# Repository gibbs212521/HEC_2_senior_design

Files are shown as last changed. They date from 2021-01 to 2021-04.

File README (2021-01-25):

##################################################################################
#                                                                                #

#                                                                                #
##################################################################################

##################################################################################

                #########################################
                #                                       #
                #              Code Example             #
                #   C Code Snippet for Multi-Platform   #
                #           ---Adaptations---           #
                #                                       #
                #########################################

#if defined(WIN32) || defined(_WIN32) || defined(__WIN32__) || defined(__NT__)
   //define something for Windows (32-bit and 64-bit, this part is common)
   #ifdef _WIN64
      //define something for Windows (64-bit only)
   #else
      //define something for Windows (32-bit only)
   #endif
#elif __APPLE__
    #include <TargetConditionals.h>
    #if TARGET_IPHONE_SIMULATOR
         // iOS Simulator
    #elif TARGET_OS_IPHONE
        // iOS device
    #elif TARGET_OS_MAC
        // Other kinds of Mac OS
    #else
    #   error "Unknown Apple platform"
    #endif
#elif __linux__
    // linux
#elif __unix__ // all unices not caught above
    // Unix
#elif defined(_POSIX_VERSION)
    // POSIX
#else
#   error "Unknown compiler"
#endif

/* ********** can be auto-generated in python *********** */

##################################################################################

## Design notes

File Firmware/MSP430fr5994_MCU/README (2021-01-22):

IMPORTANT:
--include_path="C:/ti/ccs1011/ccs/ccs_base/msp430/include" --include_path="C:/ti/ccs1011/ccs/tools/compiler/ti-cgt-msp430_20.2.4.LTS/include" --define=__MSP430FR5994__ --define=_MPU_ENABLE -g --advice:power=all

ALL from Code Composer Studio's compiler:
-vmspx --data_model=restricted --use_hw_mpy=F5 --include_path="C:/ti/ccs1011/ccs/ccs_base/msp430/include" --include_path="C:/ti/ccs1011/ccs/tools/compiler/ti-cgt-msp430_20.2.4.LTS/include" --advice:power=all --advice:hw_config=all --define=__MSP430FR5994__ --define=_MPU_ENABLE -g --printf_support=minimal --diag_warning=225 --diag_wrap=off --display_error_number --silicon_errata=CPU21 --silicon_errata=CPU22 --silicon_errata=CPU40

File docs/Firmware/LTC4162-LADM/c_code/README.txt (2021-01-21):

LTC4162 C Library
==============================

Introduction:
-------------

This  C library includes headers and several functions to simplify communication
with  the  LTC4162.  This  low  level library provides a header file with the
definitions  of registers and bit fields within those registers, and routines to
read and write those registers and individual bit-fields.

Files:
------

LTC4162-LADM_reg_defs.h - Header file containing definitions of registers and bit
fields in the LTC4162.  Names and addresses of registers are defined here.
Names, addresses, sizes, offsets, and masks are defined for bit fields in the
LTC4162.  This information is also packed into a definition that is used by
LTC4162-LADM.c

LTC4162-LADM.c - Functions to initialize a LTC4162 instance, read and write
registers and bit-fields

LTC4162-LADM.h - Header file defining prototypes, data structures and constants
used by LTC4162-LADM.c

LTC4162-LADM_formats.h - File defining constants and macros that can be used by
LTC4162-LADM.c to convert real values to LTC4162 integer values at compile-time
(optimized away) and to convert LTC4162 integer values to real values at run-time
for UI display or debug (floating point arithmetic required).

LTC4162-LADM_pec.c - File containing bit-wise and table lookup CRC-8 functions to
compute SMBus Packet Error Check byte.

LTC4162-LADM_pec.h - File containing Packet Error Check function headers.

LTC4162-LADM_example_generic.c - An example showing how to use the LTC4162.c
library. Dummy functions containing print statements are used in place of
hardware reads and writes.

LTC4162-LADM_example_linux.c - An example using the Linux kernel i2c-dev
interface to communicate with the LTC4162. We've tested this
on a Raspberry Pi 3 Model B.

LTC4162-LADM_bf_config.c - An example re-writing all LTC4162 writable
bit fields to their power-on default state. Can be used as a template to
quickly modify settings from their default.

LTC4162-LADM_reg_config.c - An example re-writing all LTC4162 writable
registers to their power-on default state. Can be used as a template to
quickly modify settings from their default. This program is smaller, but
less readable than LTC4162-LADM_bf_config.c.

LTC4162-LADM_example_mzero.ino - An Arduino Zero compatible example using
the libraries within MZeroSketchbook to communicate with the LTC4162.
This example can be uploaded directly to the DC2038A demoboard. The default GUI-
compatible DC2038A firmware can be restored through the DC2038A GUI.
To build the Arduino Zero project successfully, the following common files
must be in the LTC4162-LADM_example_mzero folder:
  LTC4162-LADM_example_mzero.ino (exists in folder by default)
  LTC4162-LADM.c
  LTC4162-LADM.h
  LTC4162-LADM_formats.h
  LTC4162-LADM_reg_defs.h
Install Arduino IDE version 1.8.7 or later from https://www.arduino.cc/en/Main/Software
if you don't already have it. In Windows Explorer, double-click on the copy of
LTC4162-LADM_example_mzero.ino to launch Arduino IDE.
Click on Tools -> Board: -> Boards Manager , and install the
"Arduino SAMD Boards" version 1.6.20 or later.
Click on Tools -> Board: and select Arduino/Genuino Zero (Native USB Port).
Click on File -> Preferences , and change Sketchbook location to be the path to
the MZeroSketchbook folder. This is located at the top-level directory of this SDK.
Plug in your LTC4162-LADM demoboard via USB.
Click on Tools -> Port . Select the port corresponding to the LTC4162-LADM demoboard.
You're now ready to compile and upload the sketch to your LTC4162-LADM demoboard.

LTC4162-LADM_example_linduino.ino - An example using the LT_SMBus Linduino library
to communicate with the LTC4162. This example can be uploaded onto a Linduino and
can also be easily adapted to use other TWI/I2C/SMBus Arduino libraries.
More information about Linduino is available here:
https://www.analog.com/en/design-center/evaluation-hardware-and-software/linduino.html
To build the Linduino project successfully, the following common files
must be in the LTC4162-LADM_example_linduino folder:
  LTC4162-LADM_example_linduino.ino
  LTC4162-LADM.c
  LTC4162-LADM.h
  LTC4162-LADM_formats.h
  LTC4162-LADM_reg_defs.h
Install Arduino IDE version 1.8.7 or later from https://www.arduino.cc/en/Main/Software
if you don't already have it. In Windows Explorer, double-click on the copy of
LTC4162-LADM_example_ linduino.ino to launch Arduino IDE.
Click on Tools -> Board: and select Arduino/Genuino Uno.
Click on File -> Preferences , and change Sketchbook location to be the path to
the LTSketchbook folder which can be downloaded from here:
https://github.com/analogdevicesinc/Linduino/tree/master/LTSketchbook
Plug in your Linduino via USB.
Click on Tools -> Port . Select the port corresponding to the Linduino.
You're now ready to compile and upload the sketch to your Linduino.

Makefile - Makefile to build the examples.  Targets are generic, linux and clean.
  "make generic" builds LTC4162-LADM_example_generic.c.
  "make linux" builds LTC4162-LADM_example_linux.c.

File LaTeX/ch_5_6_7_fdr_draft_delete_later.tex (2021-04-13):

%		For public use only, fair use laws still apply
%		A tutorial template created by Chad Gibbons

%	I recommend for generic help the following website
%	http://www.emerson.emory.edu/services/latex/latex_toc.html
%	There are many good websites and forums for LaTeX
%
%	If you have a problem, google it. (ex. "How do I start my page numbers at a different number")

%%%%%%%%%%%%%%%%%%%%%%%%%%%%%%%%%%%%%%%%%%%%%%%%%%%%%%
%					 													  %
%					 													  %
%					  ALWAYS BEGIN THE PROGRAM WITH								  %
%					 													  %
%						\documentclass{class_type}								  %
%																		  %
%		Different class types have different commands associated with them, similar to header files			  %
%					 													  %
%					 													  %`
%%%%%%%%%%%%%%%%%%%%%%%%%%%%%%%%%%%%%%%%%%%%%%%%%%%%%%

\documentclass[12pt]{article}
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
\usepackage[english]{babel}
\usepackage{csquotes}				%	Permits \enquote{quote}
\usepackage{graphicx}				%	Permits \includegraphics[]{image}
\usepackage{caption}				%	Permits the void caption \caption*{}
\usepackage{titlesec}				%	Modify section titles
\usepackage{wrapfig}				% 	Insert wrappable objects like figures or tables
%\usepackage{a4wide}				% 	Expand width of body lazily
\usepackage{multicol}				% 	Permits multicolumn
\usepackage{multirow}				%	Permites utilization of multiple rows of a table
\usepackage{tocloft}				%	Permits modification of Table of Contents
\usepackage{amssymb}				%	Greek Alphabet Symbols
\usepackage{appendix}

\usepackage{scrextend}				% 	Permits padding margins of document

\graphicspath{ {./images/} }			%	Sets filepath to images folder in location of TeX Document

\usepackage[utf8]{inputenc}			%	biblatex depends on on this package
\usepackage{comment}
%\usepackage[backend=bibtex,style=numeric]{biblatex}	%	LaTeX blibliography	%% Note: ieee stle lower-cases titles past first letter (Which seems wrong)
\usepackage[backend=bibtex,style=numeric,sorting=none]{biblatex}
%\bibliographystyle{ieeetr}			% INVESTIGATE FURTHER FOR AUTO ORDERING OF BIB REFERENCES
\bibliography{FDR_Draft}				%	REMEMBER TO RENAME THIS FILE IF MOVING TO NEW .bib

%\addbibresource{hec2.bib}

			%	Makes Table of Contents Functionally a table of Hyperlinks
\usepackage{hyperref}
\hypersetup{
	colorlinks,
	citecolor= black,
	filecolor = black,
	linkcolor = blue,
	urlcolor = blue
	}

			%	Next Three Lines permit use of .tif images in \includegraphics
\usepackage{epstopdf}
\epstopdfDeclareGraphicsRule{.tif}{png}{.png}{convert #1 \OutputFile}
\AppendGraphicsExtensions{.tif}

\renewcommand{\thesection}{\Roman{section}} 
\renewcommand{\thesubsection}{\thesection.\Alph{subsection}}
\renewcommand{\thesubsubsection}{\thesection.\arabic{subsubsection}}
\setlength\cftsecnumwidth{3em}
\setlength\cftsubsecnumwidth{3em}
\setlength\cftsubsubsecnumwidth{3em}

			%	Define Abstract to be IEEE compliant (10pt, centered, roman numerals, capitalized)
\titleformat{\abstract}{\normalfont\btshape}{\Roman{section}}{1em}{\MakeUppercase}
			%	Define Sections to be IEEE compliant (10pt, centered, roman numerals, capitalized)
\titleformat{\section}{\normalfont\filcenter}{\Roman{section}.}{1em}{\MakeUppercase}
			%	Define Subections to be IEEE compliant (10pt, left, roman numerals, capitalized)
\titleformat{\subsection}{\normalfont\itshape}{\Alph{subsection}.}{1em}{}
			%	Define Subsubections to be IEEE compliant (10pt, left, roman numerals, capitalized, inline text)
\titleformat{\subsubsection}[runin]{\normalfont\itshape}{\indent\arabic{subsubsection}.)}{1em}{}
			%	Define Table of Contents to be IEEE compliant

			%	Next Two Lines Make Document San-Serif
%\renewcommand{\familydefault}{\sfdefault}		
%\usepackage{helvet}

\usepackage{textcomp}				%	For subsection symbol w/ \textsection
\usepackage{pdfpages}				%	For inserting PDF document and pages into LaTeX file
							%% 		Recommended pdfpages format : 									%%
							%%		\includepdf[pages=-,width=0.9\linewidth,pagecommand={}]{./appendices/file.pdf}		%%

\newcommand{\cross}[1][1pt]{\ooalign{ 	%	Creating footnote cross symbol
  \rule[1ex]{1ex}{#1}\cr% Horizontal bar
  \hss\rule{#1}{.7em}\hss\cr}}% Vertical bar

%\usepackage[T1]{fontspec}
\usepackage{inconsolata}				%	converts \ttfamily to consolas font
%\IfFileExists{zi4.sty}{\usepackage{zi4}}					%	renamed version of inconsolata
%{\usepackage{inconsolata}}	
%\newfontfamily{\ttconsolas}{Consolas}

%%%%%%%%%%%%%%%%%%%%%%%%%%%%%%%%%%%%%%%%%%%%%%%%%%%%%%%			PREAMBLE

%%%%%%%%%%%%%%%%%%%%%%%%%%%%%%%%%%%%%%%%%%%%%%%%%%%%%%%			DOCUMENT

%%%%%%%%%%%%%%%%%%%%%%%%%%%%%%%%%%%%%%%%%%%%%%%%%%%%%%
%					 													  %
%					 													  %
%					  ALWAYS BEGIN THE DOCUMENT WITH								  %
%					 													  %
%							\begin{document}									  %
%					 													  %
%					 													  %
%%%%%%%%%%%%%%%%%%%%%%%%%%%%%%%%%%%%%%%%%%%%%%%%%%%%%%

\begin{document}

\section{Testing and Validation}
\indent
Validation of a product prototype is an important step to determine the performance, reliability, and durability of the designed product. Without proper testing, the product life cycle can be severely limited due to component failure or subcircuit malfunction.  All basic functionality for each subsystem is verified by following standard test practices. The transmitter and receiver subsystems were subjected to validation tests described below to observe their actual performance. 

\pagebreak

\section*{Transmitter Tests} %%%%%%%%%%%%%%%%%%%%%%%%%%%%%%%%%%%%%%%%%%%%%%%%%
\subsection{Transmitter Power Supply Tests}
\indent
The transmitter prototype board testing starts by applying DC voltage on pins 3, and 4 positive terminals and pins 1-7 negative terminals. DC voltage is supplied using a bench power supply with the current limit set to 0.3A. The power supply voltage is gradually increased from 0V to the nominal voltage of 48V while the bench power supply current was constantly monitored.
The 30V regulator will start regulating if the input voltage is higher than 38.3V. The expected output voltage on TP 1 is 30V +/-2\% due to reference voltage tolerance and resistors used for setting the output voltage.\\

\noindent
After the 30V regulator test, the voltage output is verified the following low voltage regulators are verified:\\
\hfill \\
\indent \indent $\cdot$ 3.3V regulator (U11) test point TP2 nominal voltage 3.3V  tolerance +/- 1.5\% \\
\indent \indent $\cdot$ 5V regulator (U11) test point TP3 nominal voltage 5V  tolerance +/- 1.5\%\\

\noindent
Below is the part of the schematic diagram showing test points TP1, TP2, and TP3.
\hfill
\begin{figure}[h!]
\centering
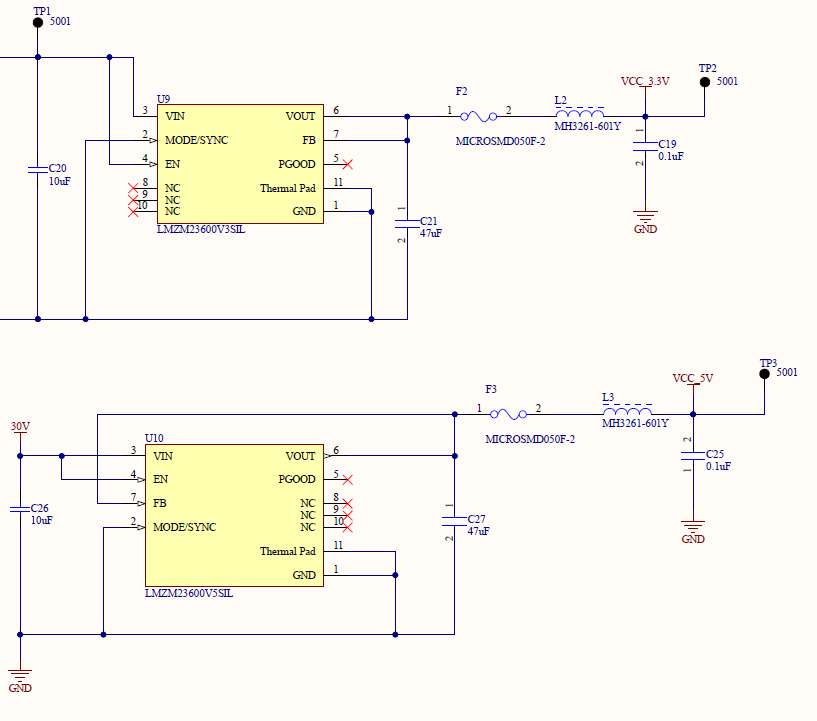
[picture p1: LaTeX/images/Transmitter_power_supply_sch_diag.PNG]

\caption{Transmitter Voltage Regulator Circuits}
\end{figure}

\hfill \\
\indent
After power modules are verified the test firmware can be loaded using a JTAG connection on the board.  The firmware sets all parameters in the default state for testing. The coil driver is disabled and all peripherals are turned off.

\subsection{Transmitter Coil Driver Tests}
\indent
After the firmware is loaded the board is turned off and the transmitter coil is connected to the terminals J3 and J4. The coil driver circuit is tested using a variable voltage supply. To perform this test PPTC fuse, F1 is removed and the bench power supply is connected to the TP1 (positive terminal) and the negative terminal is connected to the ground.  The oscilloscope probe is attached to the drain of  Q1 (GaN FET transistor).  The second probe is connected to the output of the 13.56MHz temperature compensated oscillator (TP4).\\

\indent
After the test equipment is attached the power supply is turned on and the output voltage is gradually increased. When the power supply is higher than 5V voltage regulators (3.3V and 5V) are enabled and they provide power to the transmitter subcircuits.  The temperature compensated oscillator (TXCO) enable line is controlled by push buttons. When the oscillator enable line is set to a high level a 13.56MHz signal is enabled and 13.56MHz is fed into the Class E amplifier driver (U11). The expected voltage from the TXCO on TP4 is 3.3Vpp.  After the oscillator subcircuit is verified the oscilloscope probe is placed on one of the terminals of jumper R32 to verify the functionality of U11. The expected amplitude on the output of the Class E amplifier driver is 5Vpp.\\

\noindent
The figure below presents the subcircuit wherein the transmission signal is generated and tested.
\hfill
\begin{figure}[h!]
\centering
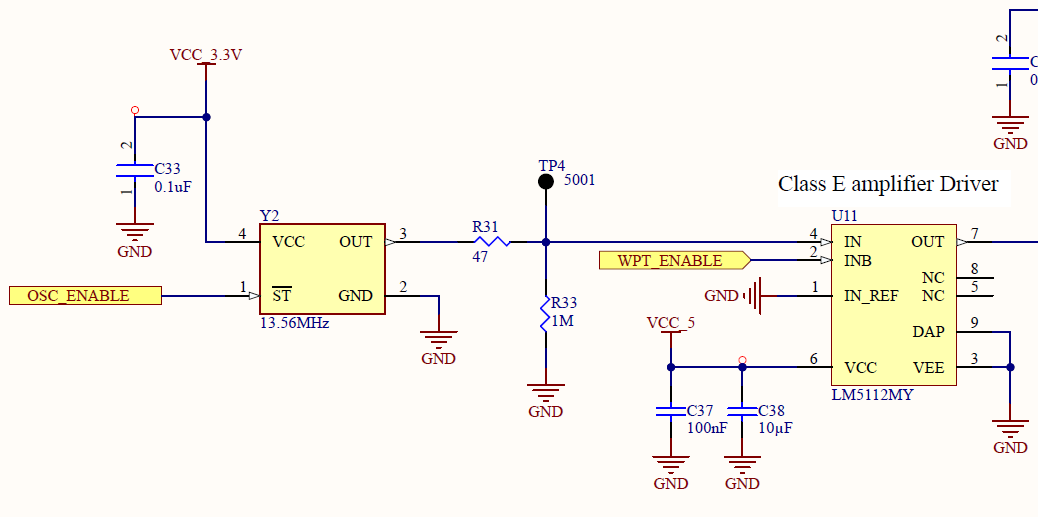
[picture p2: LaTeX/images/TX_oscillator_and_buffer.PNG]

\caption{Oscillator and Buffer Subcircuit}
\end{figure}
\hfill \\
\pagebreak

\indent
The GaN FET switching is verified by observing the GaN FET drain voltage waveform that will have a voltage swing from 0V to 117V if the power supply voltage is set to 30 V. For lower supply voltages the swing will be lower but it always should swing from 0V to some positive voltage.  After the GaN FET switching is verified the transmitter coil resonance will be adjusted. \\

\indent
To set transmitter coil resonance a variable capacitor (C28) must be adjusted while the voltage across the coil is monitored using a 100X oscilloscope probe attached to J4  (transmitter board coil terminal). The trimmer capacitor must be adjusted until the voltage across the transmitter coil reaches the maximum value. After the resonance is achieved the power supply voltage is gradually increased to 30V while the supply current is constantly monitored.  The expected voltage on the drain of the GaN FET is 117Vpp. The measured voltage is recorded.  The 30V power supply current should be 120mA if there is no load present (no receiver coil in the front of the transmitter coil).\\

\noindent
The figure below presents the subcircuit wherein the transmission signal is amplified and observed by a Class E amplifier.
\hfill
\begin{figure}[h!]
\centering
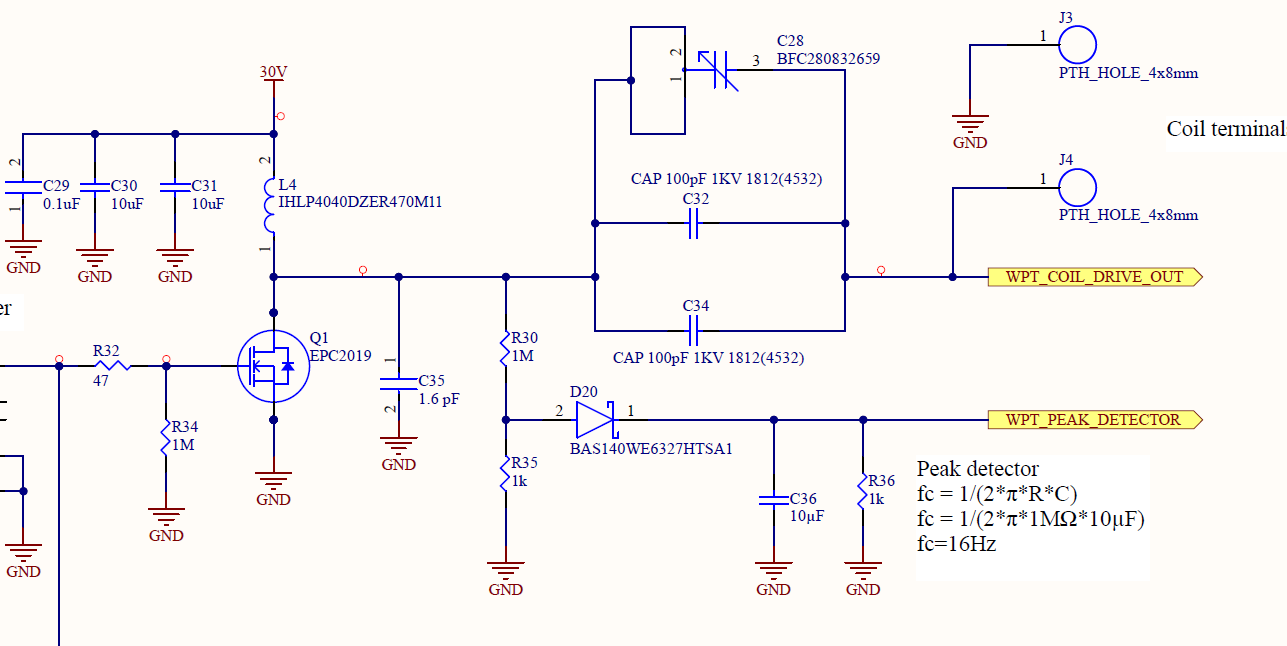
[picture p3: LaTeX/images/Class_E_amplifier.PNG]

\caption{Transmission Signal Class E Amplifier Subcircuit}
\end{figure}
\hfill \\
\pagebreak
\hfill \\
\indent
Transmitter power output is measured when the class E amplifier is verified and the amplifier power supply voltage is 30V.  The specified transmitter power output is 30W. The power output is measured by placing receiving LC circuit loaded with a 50Ω high power resistor in the front of the transmitter coil at a distance of 5 cm. The peak to peak voltage across the load is measured using the oscilloscope and recorded in the table. This process is repeated for distances of 4 cm, 3 cm, 2 cm, and 1 cm.
\hfill
\begin{figure}[h!]
\centering
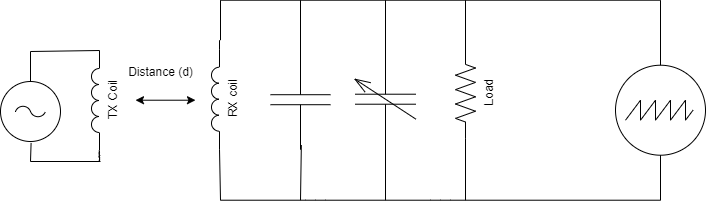
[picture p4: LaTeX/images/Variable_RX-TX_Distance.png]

\caption{Received Power vs. Distance Test Setup}
\end{figure}

\subsection{Transmitter Firmware Tests}

\noindent
The figure below is a reference for the transmitter part numbers and pin numbers.  The part numbers can be found adjacent to the part outline with a prefix of P, J, U, Q, F, D, R, C, or L.  Pin numbers are found without a prefix adjacent to the first and last pin with their respective number in any part denoted by the prefix P where space provides.
\hfill
\begin{figure}[h!]
\centering
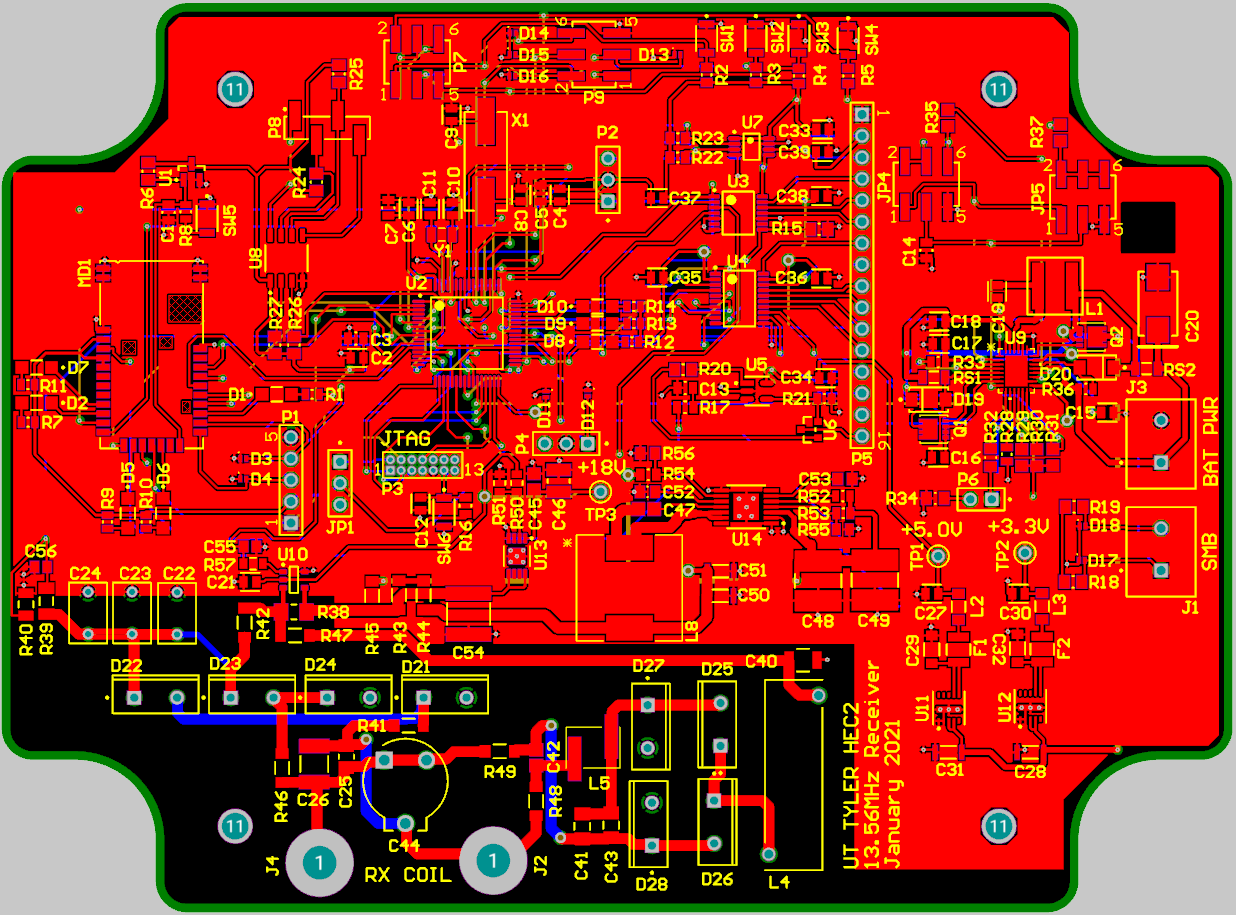
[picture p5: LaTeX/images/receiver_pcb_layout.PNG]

\caption{Reference Layout for Part and Pin Numbers}
\end{figure}

\hfill
\pagebreak
\hfill 
\subsection{Transmitter Firmware Tests}

\indent
The first recommendation in any trouble rise of troubleshooting of quality assurance is to check the mcu\_setup.c and mcu\_setup.h files.  Additionally, it is good to note that a unit test is a type of software test that only requires building a small portion of the codebase in order to test a set of specific modules.  Unit testing reduces the total amount of time dedicated into the development of any software.

%%% Currently at once every two seconds
\subsubsection*{The MCU Clock On LED} (MCU\_Clock\_on or D8 by the microcontroller) should be blinking at a rate of approximately twice every second \textbf{(This rate is subject to change)}.  If this is not occurring, the clock interrupt routine is not operating properly.  Investigate for over-polling at the UART RX Pins (P2.0 and P2.5) is occurring.  Alternatively, the TX Pins could be written out of turn (P2.1 and P2.6) which would thus initiate the UART Interrupts EUSCI\_A0\_VECTOR (located at P2.0 and P2.1) or EUSCI\_A1\_VECTOR (located at P2.5 and P2.6).  If this is not the case, the next step would be to troubleshoot the ADC (Analog to Digital Converter) Pins (P3.0, P3.1, P3.2, and P3.3).  If this issue where the ADC12\_B\_VECTOR interrupt contravenes the clock interrupt is detected, the error is likely caused by a breakdown in the hierarchy of interrupts.  In such a case, the code must be provided additional logic on how to handle specific interrupts in the scheduler’s run method.

\subsubsection*{The LCD Ticker Panel} should display some coherent statement or acronym.  If it does not, running of a “Hello World” unit test to the LCD is required for appropriate troubleshooting.  The unit test should utilize the identical function used in the production code.  If the unit test passes without errors, the error would reside in the accumulation of text that is meant to be passed into the LCD Ticker Panel.

\subsubsection*{The UART (RX/TX) CON} tests require unit tests. There are four unit tests to be done to test the non-Bluetooth UART ports (P2.5 and P2.6).  The first involves transmitting a ‘A’ character to the same PCB’s RX\_CON Pin (P2.5).  The next unit test would involve transmitting a string and acknowledgement TCP handshake.  These same unit tests are repeated with a secondary PCB.

\subsubsection*{The Bluetooth} validation tests will involve a unit test from the personal computer that connects to the receiver and sweeps through a set of pre-programmed unit tests that provide specific responses and sample data points.

\subsubsection*{The Wireless Power Transmission (WPT) Signal Generation} test should be conducted prior to connecting the transmitter's WPT coil.  Press Button 0 at SW1 to turn on the signal generator and measure the voltage at the transmitter WPT Coil Junction points (J3 with J4 as well as J5 with J6).  Once the voltage is observed, press Button 1 at SW2 to turn off the signal generator, and a drop off of voltage should be observed. \textbf{(NOTE: The button closest to the microcontroller is Button 0 while the button furthest from the microcontroller and closest to the pins of Part P5 is Button 4. The buttons are arranged in sequential order.)}
%%%%%%%%%%%%%%%  NEED WPT_PEAK_DETECTOR Algorithm
\hfill
\pagebreak
\section*{Receiver Tests}  %%%%%%%%%%%%%%%%%%%%%%%%%%%%%%%%%%%%%%%%%%%%

\subsection{Receiver Power Supply Tests}
\indent
The receiver prototype board testing starts by applying DC voltage across coil terminals for power supply verification at the Receiver Coil Junction Points (J2 and J4).  The Coil terminal subcircuit is shown in the figure below.
\hfill
\begin{figure}[h!]
\centering
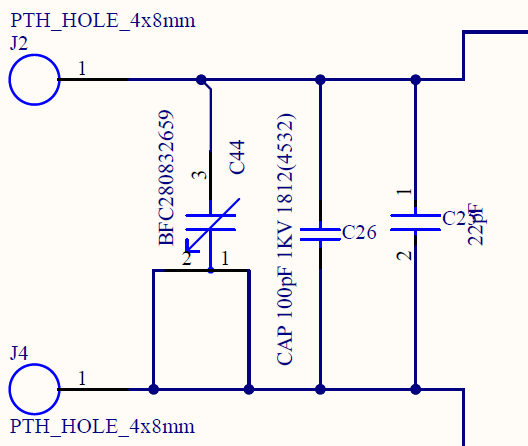
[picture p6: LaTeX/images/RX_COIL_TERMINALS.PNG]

\caption{Receiver Coil Terminal Subcircuit}
\end{figure}
\hfill \\
\indent
This test is necessary for determining whether the voltage regulators output voltages are matching the design specification.\\

\noindent
The following voltage regulators are verified in this test:
\indent \indent $\cdot$3.3V regulator (U12) test point TP2 nominal voltage 3.3V  tolerance +/- 1.5\%\\
\indent \indent $\cdot$5V regulator (U11) test point TP1 nominal voltage 5V  tolerance +/- 1.5\%\\
\indent \indent $\cdot$18V regulator (U13A) test point TP3 nominal voltage 18V tolerance +/- 2\%\\

\noindent
After power module verification the test firmware can be loaded using a JTAG connection on the board.  The firmware sets all parameters in the default state for testing.

\hfill \\
\pagebreak

\subsection{Receiver Wireless Power Rectifier Tests}

\noindent
Specification  for AC-DC (RF-DC) conversion efficiency is 80\%\\
 
\noindent
Conversion efficiency is tested using resistive load and without any other circuit attached to the DC side of the converter (R43 is removed). The load voltage and current are continuously  measured.  The specified receiver coil distance from the charger coil is 5 cm max.
\subsubsection*{Efficiency Test Protocol}\hfill \\
\noindent
This test is determines the efficiency of the power transfer at various distances:\\
\indent \indent $\cdot$The transmitter RF output is set to output 30W.\\
\indent \indent $\cdot$The receiver coil is placed at a 5 cm distance from the transmitter\\
\indent \indent $\cdot$Current and load voltage are recorded\\

\noindent
Previous steps are performed for distances 4 cm, 3 cm 2 cm, and 1 cm.  Using collected information load power is calculated.  Efficiency is calculated using the following equation:

\begin{equation}
\eta = \frac{P_{receiver}}{P_{transmitter}} \cdot 100\%
\end{equation}
\hfill
\begin{figure}[h!]
\centering
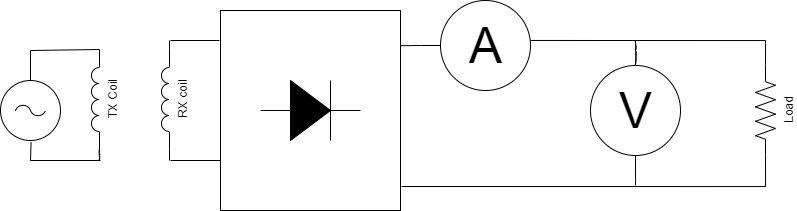
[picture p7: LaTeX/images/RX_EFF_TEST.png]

\caption{Receiver RF-DC Converter Efficiency Test Setup}
\end{figure}

\subsection{Receiver Battery Charger Tests}

\indent
The bench power supply current should initially be llimited to 1A and the initial voltage should be set to 20V.  There are two diode voltage drops (1.4V) in the full wave rectifier bridge circuit.  18.6V on charger input is high enough for the proper operating voltage for the LTC4162-L battery charger.  The charger is functional without the battery pack and according to the datasheet, the voltage on the charger output will rise to the programmed constant-voltage value. By measuring this voltage it is possible to determine whether the charger regulates the proper voltage for a given programmed value.
\hfill 
\pagebreak
\hfill \\

\indent
A 18650 battery with two cells in series discharged to 3.2-3.8V per cell may be used for constant current and constant voltage charge testing.  The bench power supply should be connected followed by the battery and no change in MCU behavior should be noted. Constant current charging should begin.  The current limit of the bench power supply may be increased and the charging current should increase up to a maximum of 3.2A. The maximum charging current, charging voltage, cell count, and power supply current and voltage should be recorded and efficiency calculated.\\

\indent Then the power supply should be disconnected and reconnected and there should be no effect on the MCU power state. Charging should automatically resume when the power supply is reconnected. The battery should be allowed to charge until it enters constant voltage mode, which may be recognized by a slowly decreasing charge current that is much lower than the maximum current observed during constant current charging.  A 2 ohm load should be connected to the battery under charge for at least 30 seconds and removed without any effect on MCU operation.

\subsection{Receiver Firmware Tests}

\indent
The first recommendation in any trouble rise of troubleshooting of quality assurance is to check the mcu\_setup.c and mcu\_setup.h files.  Additionally, it is good to note that a unit test is a type of software test that only requires building a small portion of the codebase in order to test a set of specific modules.  Unit testing reduces the total amount of time dedicated into the development of any software.

%%% Currently at once every two seconds
\subsubsection*{The MCU Clock On LED} (MCU\_Clock\_on or D8 by the microcontroller) should be blinking at a rate of approximately twice every second \textbf{(This rate is subject to change)}.  If this is not occurring, the clock interrupt routine is not operating properly.  Investigate for over-polling at the UART RX Pins (P2.0 and P2.5) is occurring.  Alternatively, the TX Pins could be written out of turn (P2.1 and P2.6) which would thus initiate the UART Interrupts EUSCI\_A0\_VECTOR (located at P2.0 and P2.1) or EUSCI\_A1\_VECTOR (located at P2.5 and P2.6).  If this is not the case, the next step would be to troubleshoot the ADC (Analog to Digital Converter) Pins (P3.0, P3.1, P3.2, and P3.3).  If this issue where the ADC12\_B\_VECTOR interrupt contravenes the clock interrupt is detected, the error is likely caused by a breakdown in the hierarchy of interrupts.  In such a case, the code must be provided additional logic on how to handle specific interrupts in the scheduler’s run method.

\subsubsection*{The LCD Ticker Panel} should display some coherent statement or acronym.  If it does not, running of a “Hello World” unit test to the LCD is required for appropriate troubleshooting.  The unit test should utilize the identical function used in the production code.  If the unit test passes without errors, the error would reside in the accumulation of text that is meant to be passed into the LCD Ticker Panel.

\subsubsection*{The UART (RX/TX) CON} tests require unit tests. There are four unit tests to be done to test the non-Bluetooth UART ports (P2.5 and P2.6).  The first involves transmitting a ‘A’ character to the same PCB’s RX\_CON Pin (P2.5).  The next unit test would involve transmitting a string and acknowledgement TCP handshake.  These same unit tests are repeated with a secondary PCB.

\subsubsection*{The Bluetooth} validation tests will involve a unit test from the personal computer that connects to the receiver and sweeps through a set of pre-programmed unit tests that provide specific responses and sample data points.  The Bluetooth tests for the receiver should also include data requests pertaining to the voltage from the battery, the battery's current charge, and any data utilized in the battery charger.
\hfill \\
\pagebreak
\hfill
\section*{System Tests}
\subsection{Coil Test}
Coil impedance is measured using Vector Network Analyzer (VNA). The impedance measurement is obtained by setting the instrument to measure S-parameters (S11) at 13.56 MHz.  Before measurements, the instrument must be calibrated using calibration standards (short circuit, open circuit, and 50$\omega$ load).  The measured impedance is in complex form R+jX form.\\

\noindent
Specified inductance: 909.66nH\\

\noindent
The coil's inductance is determined using the formula below:
\begin{equation}
L = \frac{X_L}{\omega}
\end{equation}
\noindent
Where $\omega$ = 2$\pi$f\\

\noindent
The figure below shows the the equivalent circuit of how the transmitter / receiver coils were evaluated using a Vector Network Analyzer.
\hfill
\begin{figure}[h!]
\centering
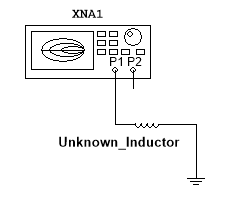
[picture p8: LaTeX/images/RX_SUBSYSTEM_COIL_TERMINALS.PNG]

\caption{VNA Test Setup}
\end{figure}

\pagebreak

\noindent
Although VNA is not very precise for quality factor measurements it still can be used for estimation. The quality factor is determined by obtaining S21 parameter (forward voltage gain).\\

\noindent
Specified Q factor: 1119\\
 
 \noindent
The quality factor also can be determined by dividing reactance by the resistance the formula is shown below:
\begin{equation}
Q = \frac{X_L}{R}
\end{equation}

\subsection{System Level Firmware Tests}

\subsubsection*{The Bluetooth Localization Test} utilizes the “M” command on the RN4870 BLE chip with 3 prior locations to triangulate which direction is moving towards the transmitter.  This test begins with a computer provided unit test that accepts four distances, the first three that are used to triangulate the receiver in reference to the transmitter and a fourth that must be closer than all three triangulating distances to be considered passing.
\hfill 
\pagebreak

\subsection{Test Results Summary}

\subsubsection{Transmitter Evaluations} \hfill
\subsubsection*{DC Power Test} \hfill \\
\noindent
30V regulator no-load condition measured output voltage 30.04 V\\
5V regulator measured output voltage TP3 5.03V\\
3.3V regulator measured output voltage TP2 3.33V\\
 
\subsubsection*{Coil Driver Test} \hfill \\
Oscillator output voltage TP4 3.69V$_{pp}$\\
 
\noindent
Oscillator output Frequency (13.56 MHz) measured: 13.56MHz\\
Class E amplifier driver voltage jumper R32 (nominal 5Vpp) measured 5.80Vpp
\hfill
\begin{figure}[h!]
\centering
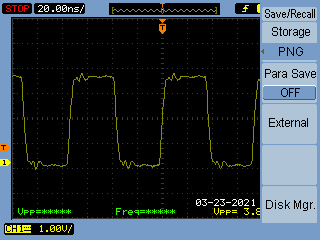
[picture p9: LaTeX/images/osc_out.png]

\caption{Class E Amplifier Driver Output}
\end{figure}
\hfill \\
\pagebreak

\noindent
Q1 Dran nom. 117 V$_{pp}$ (30 V supply) Measured 102V$_{pp}$
\hfill
\begin{figure}[h!]
\centering

\caption{Q1 Drain Voltage Waveform}
\end{figure}

\noindent
Transmitter coil voltage 117 V$_{pp}$ (30 V supply) Measured 204V$_{pp}$
\hfill
\begin{figure}[h!]
\centering

\caption{Q1 Drain Voltage Waveform}
\end{figure}
\hfill 
\pagebreak
\hfill \\
\noindent
Transmitter subsystem input current at 30V supply (120 mA nom. no laod) Measured 140 mA

\begin{table}[h!]
\centering
%Received Power (DC) vs Distance Test
\caption{Transmitted Power vs. Distance Test}
\begin{tabular}{ | c | c | c | }
\hline
 Distance [cm] & Measured Voltage [V$_{pp}$] & Received Power [W] \\
 \hline
5 & & \\
\hline
4 & & \\
\hline
3 & & \\
\hline
2 & & \\
\hline
1 & & \\
\hline
\end{tabular}
\end{table}

\subsubsection{Receiver Evaluations} \hfill \\
\subsubsection*{DC Power Test} \hfill \\
\noindent
5V regulator measured output voltage TP1 5.07V\\
3.3V regulator measured output voltage TP2 3.33V\\
18V regulator measured output voltage TP3 18.26V\\

\begin{table}[h!]
\centering
\caption{Received Power (DC) vs Distance Test}
\begin{tabular}{ | c | c | c |  c |}
\hline
Distance [cm] & Measured Voltage [V] & Measured Current [A] & Power Received [W] \\
\hline
5 & & & \\
\hline
4 & & & \\
\hline
3 & & & \\
\hline
2 & & & \\
\hline
1 & & & \\
\hline
\end{tabular}
\end{table}

\subsubsection*{Coil Design Verification Test}\hfill \\
\noindent
Specified inductance: 909.66nH\\ 
Measured impedance at 13.56MHz: 0.43 +j78.28$\Omega$\\
\hfill \\
\pagebreak
\hfill \\
\begin{figure}[h!]
\centering

\caption{VNA TX/RX Coil Impedance Measurement}
\end{figure}
\hfill \\
\noindent 
Measured inductance using VNA (HP8753E) 0.917 $\mu$H\\
Measured inductance using LCR meter (HP4262A) 0.97$\mu$H\\
Q factor from VNA impedance measurement: 182
\hfill
\pagebreak
\section{Broader Impacts of the Project}

\indent
This product follows FDA, IEE, and government safety regulations. A few ethical issues faced by our design include high voltages across the coil, excessive heat generation within the receiver, and electromagnetic field interference. During simulation stages, high voltages were observed across the coil which increases the risk of electric shock hazard. In order to lower this risk, the coil insulation will adhere to a wider voltage range. Within the receiver, excessive heat generation along high current levels can cause damage to batteries. Therefore, lower charging currents will be used in order to prevent damage. Excessive heat also increases the cost of the project as fans would need to be added. Electromagnetic field interference caused by the transmitter coil can disrupt the charging circuit and cause battery failure. To prevent this issue, additional shielding will be implemented. \\

\indent
During testing stages, minor ethical issues were faced by the design. Within the receiver board, there was an inductor that was not suited for a frequency of 13.56 MHz board causing failure, and our rectifier circuits caused more loading than expected when tested with a signal generator. Also, the 48V to 30V buck stage microcontroller failed during testing for reasons that are yet to be further investigated by the team. When components get too hot, there’s not only a risk of it failing, but also of leaking its chemicals which can be dangerous to human skin and eyes. Therefore, the group will adhere to safety procedures such as wearing Personal Protective Equipment (PPE). Another risk observed here is electrical shock hazard due to the overloading in the circuit. To prevent this, the group will continuously measure the circuit for abnormal values while testing.\\

\indent
Our project’s goal is to provide users a low-cost medium-power wireless charger. There are no products like this one in the market for a few reasons: chargers do not supply more than 5W via inductive charging, an existing industrial unit with same purposes as our product is priced at about \$2000 USD, and available wireless chargers are limited for charging a single type of device only. With our product, users will be able to charge a standard battery type and integrate it in their own design or use it for stand-alone operations. Our product communicates electronic circuits, electromagnetic fields, digital systems, and microprocessors concepts to the audience. This product will not only be a low-cost wireless charger option, it will also provide customers with a charger for mobile devices of all shapes and sizes, no wiring exposure, apply greater range of tolerance for misalignment when charging, and provide a compact charging area. \\

\indent
Our product will be useful to robotics hobbyists and inventors who are developing new products that require wireless charging, serve to influence kids and teenagers interested in STEM, can be used for research and development, and capitalized in OEM market.

\begin{table}[h!]
\centering
\caption*{Ethical and Professional Considerations}
\begin{tabular} {| r | c | }
\hline
\parbox{0.4\linewidth}{\raggedright Public Health} &   \parbox{0.65\linewidth}{\hfill \\
$\cdot$ Medical Equipment RF Exposure \\ $\cdot$ Electrical Shock \\ $\cdot$ Chemical Exposure}\\
\hline
\parbox{0.4\linewidth}{\raggedright Safety and Wellness} &   \parbox{0.65\linewidth}{\hfill \\
$\cdot$ RF Bandwidth Jamming \\ $\cdot$ Electrical Shock \\ $\cdot$ Chemical Exposure}\\
\hline
\parbox{0.4\linewidth}{\raggedright Global Factors} &   \parbox{0.65\linewidth}{\hfill \\
$\cdot$ International Governing Bodies \\ $\cdot$ Sourcing Restrictions \\ $\cdot$ Inter-Market Penetrability}\\
\hline
\parbox{0.4\linewidth}{\raggedright Societal Factors} &   \parbox{0.65\linewidth}{\hfill \\
$\cdot$ Open-Source Capitalization\\ $\cdot$ STEM Educational Resources \\ $\cdot$ Professional Organizations \\ $\cdot$ Customer Privacy \& Security}\\
\hline
\parbox{0.4\linewidth}{\raggedright Environmental Factors} &   \parbox{0.65\linewidth}{\hfill \\
$\cdot$ Chemical Pollution\\ $\cdot$ User Environmental Awareness\\ $\cdot$ Emergency Shut Off Cases}\\
\hline
\parbox{0.4\linewidth}{\raggedright Economic Factors} &   \parbox{0.65\linewidth}{\hfill \\
$\cdot$ Open-Source Capitalization\\ $\cdot$ Specialty Clientele\\ $\cdot$ Rapid Agile-Deployment\\ $\cdot$ Light-Weight Production}\\
\hline
\end{tabular}
\end{table}
\hfill \\

\section{Conclusion}

\indent
This conclusion reflects the current state of our testing and troubleshooting process. We expect to continue testing our prototype and resolving issues in order to bring performance as close as possible to our initial specifications.\\

\indent
The 5V LCD contrast control circuit on both boards failed due to a design error: the digital potentiometer chosen was not capable of controlling a voltage greater than the 3.3V digital supply voltage. The 5V supplied to the potentiometer simply fed into the 3.3V supply through the protection diodes until the circuit was disabled.\\

\indent
The 48V to 30V buck stage control IC on the transmitter board self-destructed for as-yet unknown reasons. No obvious design errors were found. Further diagnosis was postponed pending testing of the remainder of the board using a bench power supply.\\
\hfill \\
\pagebreak
\hfill \\

\indent
Initial tests of the battery charging circuit were successful. A test battery of two fully charged 18650 cells was correctly detected and not charged further. After partial discharge the charger entered a constant-voltage charging mode and charged the battery at a slowly decreasing current of approximately 1A. The receiver board continued to operate on battery power when simulated wireless power was removed. Further testing of constant current charging, telemetry, and the SMbus smart battery interface is pending.\\

\indent
Initial testing of the wireless power transfer resulted in a period of successful inductive power transfer and a brief success in achieving a resonant link. A failure on the transmitter board was traced to an inductor that was not suitable for operation at 13.56 Mhz. The inductor and damaged components were replaced and testing continued. A resonant link was achieved between the transmitter and receiver, but an unexpected transient destroyed the transmitter amplifier transistor. A more robust replacement will be installed for further testing.\\

\indent
In summation, our testing revealed a few avoidable design errors which can be corrected or managed until a major revision is possible. The greatest challenge our testing has revealed is controlling the high voltages and unexpected transients that even a moderate-power resonant link creates. We hope that the use of more robust components will make it possible to continue testing and characterizing the real-world performance of our wireless power circuit. A further challenge is minimizing the losses from the high-frequency rectification stage. Our initial tests indicate that switching losses in the full wave bridge rectifier are significant. As suggested by our faculty advisor, it is possible that half-wave rectification will prove more efficient than a full-wave bridge.\\

\indent
With the benefit of foresight, we would have made a few minor and one major change in our design process. The wireless power transfer circuit is the most original component of our design and ideally would have been prototyped and tested much earlier in the design process. More minor changes would include accepting the more limited selection of 3.3V LCD’s and deleting the 5V rail and support circuitry. The 48V transmitter power supply and buck stage was chosen to minimize current and provide headroom for adjustments to the wireless transmitter voltage, but further testing may prove that a 30V supply with no further conversion is sufficient.
\hfill 
\pagebreak

%%%%%%%%%%%%%%%%%%%%%%%%%%%%%%%%%%%%%%%%%%%%%%%%%%%%%%%%
%%%%%%%%%%%%%										        %%%%%%%%%%%%%
%%%%						ABOVE IS IN DOCUMENT PROPER					         %%%%
%%%%%%%%%%%%%										        %%%%%%%%%%%%%
%%%%%%%%%%%%%%%%%%%%%%%%%%%%%%%%%%%%%%%%%%%%%%%%%%%%%%%%

%%%% APPENDICES %%%%

%\hline
%\parbox{0.4\linewidth}{\raggedright
%
%} &  \parbox{0.4\linewidth}{\raggedright
%
%}\\
%\hline
\section{Experimental Data Collection Sheets}

\subsection{Transmitter Subsystem Data}

\begin{table}[h!]
\centering
\caption*{Transmitter Subsystem Data}
\begin{tabular}{ | c | c | }
\hline
\textbf{Power Supply Verification} & \textbf{Pass or Fail} \\
\hline
\parbox{0.5\linewidth}{\raggedright \hfill \\[-0.25 em]
30V power supply voltage nominal 30V +/-2\% Measured (TP1) \hfill \\[0.1 em]
} &  \parbox{0.4\linewidth}{\raggedright \hfill \\ [0.7 em]
\underline{\hspace{0.625in}} V  \hspace{0.125 in}Pass \space / \space  Fail \hfill \\ [0.3 em]
} \\
\hline
\parbox{0.5\linewidth}{\raggedright \hfill \\[-0.25 em]
3.3V regulator (U11) test point TP2 nominal voltage 3.3V  tolerance +/- 1.5\% \hfill \\[0.1 em]
} &  \parbox{0.4\linewidth}{\raggedright \hfill \\ [0.7 em]
\underline{\hspace{0.625in}} V  \hspace{0.125 in}Pass \space / \space  Fail \hfill \\ [0.3 em]
} \\
\hline
\parbox{0.5\linewidth}{\raggedright \hfill \\[-0.25 em]
5V regulator (U11) test point TP3 nominal voltage 5V  tolerance +/- 1.5\% \hfill \\[0.1 em]
} &  \parbox{0.4\linewidth}{\raggedright \hfill \\ [0.7 em]
\underline{\hspace{0.625in}} V  \hspace{0.125 in}Pass \space / \space  Fail \hfill \\ [0.3 em]
} \\ 
\hline
\parbox{0.5\linewidth}{\raggedright \hfill \\[-0.25 em]
Coil driver Circuit Test \hfill \\[0.1 em]
} &  \parbox{0.4\linewidth}{\raggedright \hfill \\ [0.7 em]
\underline{\hspace{0.625in}} V  \hspace{0.125 in}Pass \space / \space  Fail \hfill \\ [0.3 em]
} \\ 
\hline
\parbox{0.5\linewidth}{\raggedright \hfill \\[-0.25 em]
Verify functionality of Transmitter Sub-circuits \hfill \\[0.1 em]
} &  \parbox{0.4\linewidth}{\raggedright \hfill \\ [0.7 em]
\underline{\hspace{0.625in}} V  \hspace{0.125 in}Pass \space / \space  Fail \hfill \\ [0.3 em]
} \\ 
\hline
\parbox{0.5\linewidth}{\raggedright \hfill \\[-0.25 em]
Verify Functionality of U11 \hfill \\[0.1 em]
} &  \parbox{0.4\linewidth}{\raggedright \hfill \\ [0.7 em]
\underline{\hspace{0.625in}} V  \hspace{0.125 in}Pass \space / \space  Fail \hfill \\ [0.3 em]
} \\ 
\hline
\parbox{0.5\linewidth}{\raggedright \hfill \\[-0.25 em]
Voltage test for drain of the GaN FET \hfill \\[0.1 em]
} &  \parbox{0.4\linewidth}{\raggedright \hfill \\ [0.7 em]
\underline{\hspace{0.625in}} V  \hspace{0.125 in}Pass \space / \space  Fail \hfill \\ [0.3 em]
} \\ 
\hline
\parbox{0.5\linewidth}{\raggedright \hfill \\[-0.25 em]
Test Peak to Peak Voltage across load \hfill \\[0.1 em]
} &  \parbox{0.4\linewidth}{\raggedright \hfill \\ [0.7 em]
\underline{\hspace{0.625in}} V  \hspace{0.125 in}Pass \space / \space  Fail \hfill \\ [0.3 em]
} \\ 
\hline
\parbox{0.5\linewidth}{\raggedright \hfill \\[-0.25 em]
Test Transmitter Power Output \hfill \\[0.1 em]
} &  \parbox{0.4\linewidth}{\raggedright \hfill \\ [0.7 em]
\underline{\hspace{0.625in}} V  \hspace{0.125 in}Pass \space / \space  Fail \hfill \\ [0.3 em]
} \\ 
\hline
\end{tabular}
\end{table}
\noindent
\textbf{This process is repeated for distances of 5 cm, 4 cm, 3 cm, 2 cm, and 1 cm.}

\subsection{Receiver Regulators Subsystem Data}

\begin{table}[h!]
\centering
\caption*{Receiver Regulators Subsystem Data}
\begin{tabular}{ | c | c | }
\hline
\textbf{Power Supply Verification} & \textbf{Pass or Fail} \\
\hline
\parbox{0.5\linewidth}{\raggedright \hfill \\[-0.25 em]
DC voltage across coil terminals (J2 \& J4)
 \hfill \\[0.1 em]} &  \parbox{0.4\linewidth}{\raggedright \hfill \\ [0.7 em]
\underline{\hspace{0.625in}} V  \hspace{0.125 in}Pass \space / \space  Fail \hfill \\ [0.3 em]
} \\
\hline
\parbox{0.5\linewidth}{\raggedright \hfill \\[-0.25 em]
5V regulator (U11) test point TP3 nominal voltage 5V  tolerance +/- 1.5\%
\hfill \\[0.1 em]} &  \parbox{0.4\linewidth}{\raggedright \hfill \\ [0.7 em]
\underline{\hspace{0.625in}} V  \hspace{0.125 in}Pass \space / \space  Fail \hfill \\ [0.3 em]
} \\
\hline
\parbox{0.5\linewidth}{\raggedright \hfill \\[-0.25 em]
3.3V regulator (U11) test point TP2 nominal voltage 3.3V  tolerance +/- 1.5\%
\hfill \\[0.1 em]} &  \parbox{0.4\linewidth}{\raggedright \hfill \\ [0.7 em]
\underline{\hspace{0.625in}} V  \hspace{0.125 in}Pass \space / \space  Fail \hfill \\ [0.3 em]
} \\ 
\hline
\parbox{0.5\linewidth}{\raggedright \hfill \\[-0.25 em]
Firmware Test Successful Load
\hfill \\[0.1 em]} &  \parbox{0.4\linewidth}{\raggedright \hfill \\ [0.7 em]
\underline{\hspace{0.625in}} V  \hspace{0.125 in}Pass \space / \space  Fail \hfill \\ [0.3 em]
} \\ 
\hline
\end{tabular}
\end{table}
\hfill \\
\pagebreak

\subsection{Receiver Rectifier Subsystem Data}

\begin{table}[h!]
\centering
\caption*{Receiver Rectifier Subsystem Data}
\begin{tabular}{ | c | c | }
\hline
\textbf{Efficiency Test Protocols} & \textbf{Parameters} \\
\hline
\parbox{0.5\linewidth}{\raggedright \hfill \\[-0.25 em]
The transmitter RF output
 \hfill \\[0.1 em]} & 
 30 W\\
\hline
\parbox{0.5\linewidth}{\raggedright \hfill \\[-0.25 em]
The receiver coil placement (parallel)
\hfill \\[0.1 em]} & 
5 cm\\
\hline
\parbox{0.5\linewidth}{\raggedright \hfill \\[-0.25 em]
Current measured
\hfill \\[0.1 em]} &  \parbox{0.4\linewidth}{\raggedright \hfill \\ [0.7 em] \underline{\hspace{0.625in}} 
A 
\hspace{0.125 in}Pass \space / \space  Fail \hfill \\ [0.3 em]} \\ 
\hline
\parbox{0.5\linewidth}{\raggedright \hfill \\[-0.25 em]
Load Voltage measured
\hfill \\[0.1 em]} &  \parbox{0.4\linewidth}{\raggedright \hfill \\ [0.7 em]\underline{\hspace{0.625in}} 
V  
\hspace{0.125 in}Pass \space / \space  Fail \hfill \\ [0.3 em]} \\ 
\hline
\parbox{0.5\linewidth}{\raggedright \hfill \\[-0.25 em]
Load Power
\hfill \\[0.1 em]} &  \parbox{0.4\linewidth}{\raggedright \hfill \\ [0.7 em]\underline{\hspace{0.625in}} 
W
\hspace{0.125 in}Pass \space / \space  Fail \hfill \\ [0.3 em]} \\ 
\hline
\parbox{0.5\linewidth}{\raggedright \hfill \\[-0.25 em]
Efficiency
\hfill \\[0.1 em]} &  \parbox{0.4\linewidth}{\raggedright \hfill \\ [0.7 em]\underline{\hspace{0.625in}} 
\%
\hspace{0.125 in}Pass \space / \space  Fail \hfill \\ [0.3 em]} \\ 
\hline
\end{tabular}
\end{table}
\noindent
\textbf{This process is repeated for distances of 5 cm, 4 cm, 3 cm, 2 cm, and 1 cm.}

\subsection{Charger Subsystem Data}

\begin{table}[h!]
\centering
\caption*{Charger Subsystem Data}
\begin{tabular}{ | c | c | }
\hline
\textbf{Test Protocols} & \textbf{Parameters} \\
\hline
\parbox{0.5\linewidth}{\raggedright \hfill \\[-0.25 em]
Set bench power supply current limit
 \hfill \\[0.1 em]} & 
 1 A \\
\hline
\parbox{0.5\linewidth}{\raggedright \hfill \\[-0.25 em]
Set initial voltage
\hfill \\[0.1 em]} & 
20 V\\
\hline
\parbox{0.5\linewidth}{\raggedright \hfill \\[-0.25 em]
Verify Charger Input Voltage
\hfill \\[0.1 em]} &  
18.6 V\\
\hline
\parbox{0.5\linewidth}{\raggedright \hfill \\[-0.25 em]
Voltage Charger Output
\hfill \\[0.1 em]} &  \parbox{0.4\linewidth}{\raggedright \hfill \\ [0.7 em] \underline{\hspace{0.625in}} 
V 
\hspace{0.125 in}Pass \space / \space  Fail \hfill \\ [0.3 em]} \\ 
\hline
\end{tabular}
\end{table}
\hfill \\
\pagebreak

\subsection{SMBus Subsystem Test  Data}

\begin{table}[h!]
\centering
\caption*{SMBus Subsystem Test Data}
\begin{tabular}{ | c | c | }
\hline
\textbf{Test Protocols} & \textbf{Parameters} \\
\hline
\parbox{0.5\linewidth}{\raggedright \hfill \\[-0.25 em]
Verify Interface Functionality
\hfill \\[0.1 em]} &  \parbox{0.4\linewidth}{\centering \hfill \\ [0.7 em] 
Pass \space / \space  Fail \hfill \\ [0.3 em]} \\ 
\hline
\parbox{0.5\linewidth}{\raggedright \hfill \\[-0.25 em]
Input Undervoltage Setting
\hfill \\[0.1 em]} &  \parbox{0.4\linewidth}{\raggedright \hfill \\ [0.7 em]\underline{\hspace{0.625in}} 
V  
\hspace{0.125 in}Pass \space / \space  Fail \hfill \\ [0.3 em]} \\ 
\hline
\parbox{0.5\linewidth}{\raggedright \hfill \\[-0.25 em]
Final Charge Voltage
\hfill \\[0.1 em]} &  \parbox{0.4\linewidth}{\raggedright \hfill \\ [0.7 em]\underline{\hspace{0.625in}} 
V
\hspace{0.125 in}Pass \space / \space  Fail \hfill \\ [0.3 em]} \\ 
\hline
\parbox{0.5\linewidth}{\raggedright \hfill \\[-0.25 em]
Target Charge Current
\hfill \\[0.1 em]} &  \parbox{0.4\linewidth}{\raggedright \hfill \\ [0.7 em]\underline{\hspace{0.625in}} 
A
\hspace{0.125 in}Pass \space / \space  Fail \hfill \\ [0.3 em]} \\ 
\hline
\parbox{0.5\linewidth}{\raggedright \hfill \\[-0.25 em]
Input Current Limit Target
\hfill \\[0.1 em]} &  \parbox{0.4\linewidth}{\raggedright \hfill \\ [0.7 em]\underline{\hspace{0.625in}} 
A
\hspace{0.125 in}Pass \space / \space  Fail \hfill \\ [0.3 em]} \\ 
\hline
\end{tabular}
\end{table}

\subsection{Coil Subsystem Test Data}
\begin{table}[h!]
\centering
\caption*{Coil Subsystem Test Data}
\begin{tabular}{ | c | c | }
\hline
\textbf{Test Protocols} & \textbf{Parameters} \\
\hline
\parbox{0.5\linewidth}{\raggedright \hfill \\[-0.25 em]
Calibration Test for Short Circuit
\hfill \\[0.1 em]} &  \parbox{0.4\linewidth}{\raggedright \hfill \\ [0.7 em] \underline{\hspace{0.625in}} 
$\mu$H
\hspace{0.125 in}Pass \space / \space  Fail \hfill \\ [0.3 em]} \\ 
\hline
\parbox{0.5\linewidth}{\raggedright \hfill \\[-0.25 em]
Calibration Test for Open Circuit
\hfill \\[0.1 em]} &  \parbox{0.4\linewidth}{\raggedright \hfill \\ [0.7 em]\underline{\hspace{0.625in}} 
$\mu$H
\hspace{0.125 in}Pass \space / \space  Fail \hfill \\ [0.3 em]} \\ 
\hline
\parbox{0.5\linewidth}{\raggedright \hfill \\[-0.25 em]
Calibration Test with 50$\Omega$ Resistive Load
\hfill \\[0.1 em]} &  \parbox{0.4\linewidth}{\raggedright \hfill \\ [0.7 em]\underline{\hspace{0.625in}} 
$\mu$H
\hspace{0.125 in}Pass \space / \space  Fail \hfill \\ [0.3 em]} \\ 
\hline
\parbox{0.5\linewidth}{\raggedright \hfill \\[-0.25 em]
Inductive Reactance
\hfill \\[0.1 em]} &  \parbox{0.4\linewidth}{\raggedright \hfill \\ [0.7 em]\underline{\hspace{0.625in}} 
j$\Omega$
\hspace{0.125 in}Pass \space / \space  Fail \hfill \\ [0.3 em]} \\ 
\hline
\parbox{0.5\linewidth}{\raggedright \hfill \\[-0.25 em]
Impedance
\hfill \\[0.1 em]} &  \parbox{0.4\linewidth}{\raggedright \hfill \\ [0.7 em]\underline{\hspace{0.625in}} 
$\Omega$
\hspace{0.125 in}Pass \space / \space  Fail \hfill \\ [0.3 em]} \\ 
\hline
\parbox{0.5\linewidth}{\raggedright \hfill \\[-0.25 em]
Quality Factor Estimation
\hfill \\[0.1 em]} &  \parbox{0.4\linewidth}{\raggedright \hfill \\ [0.7 em]\underline{\hspace{0.625in}} 
\hspace{0.125 in}Pass \space / \space  Fail \hfill \\ [0.3 em]} \\ 
\hline
\parbox{0.5\linewidth}{\raggedright \hfill \\[-0.25 em]
S$_{21}$ parameter (Forward Voltage Gain)
\hfill \\[0.1 em]} &  \parbox{0.4\linewidth}{\raggedright \hfill \\ [0.7 em]\underline{\hspace{0.625in}} 
\hspace{0.125 in}Pass \space / \space  Fail \hfill \\ [0.3 em]} \\ 
\hline
\end{tabular}
\end{table}

\end{document}

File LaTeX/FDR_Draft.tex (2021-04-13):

%		For public use only, fair use laws still apply
%		A tutorial template created by Chad Gibbons

%	I recommend for generic help the following website
%	http://www.emerson.emory.edu/services/latex/latex_toc.html
%	There are many good websites and forums for LaTeX
%
%	If you have a problem, google it. (ex. "How do I start my page numbers at a different number")

%%%%%%%%%%%%%%%%%%%%%%%%%%%%%%%%%%%%%%%%%%%%%%%%%%%%%%
%					 													  %
%					 													  %
%					  ALWAYS BEGIN THE PROGRAM WITH								  %
%					 													  %
%						\documentclass{class_type}								  %
%																		  %
%		Different class types have different commands associated with them, similar to header files			  %
%					 													  %
%					 													  %`
%%%%%%%%%%%%%%%%%%%%%%%%%%%%%%%%%%%%%%%%%%%%%%%%%%%%%%

\documentclass[12pt]{article}
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

\title{\Large \textbf{The University of Texas at Tyler\\
College of Engineering and Computer Science\\
Tyler, TX 75799\\
\hfill \\
\hfill \\[0.5em]
Final Design Report \\ [0.25em] For\\[0.25em]
Wireless Charger Project}}		%note left quote command vs " = \textquotedblright
%%  FIX FONT of Sub Sub Title  >> It should fit in with the text below. <<
\author{\large \hfill \\[0.5em] \textbf{A design project to fulfill the requirements of Senior Design}\\ \textbf{ 
in the Department of Electrical Engineering}\\ \textbf{ 
at The University of Texas at Tyler
}\hfill \\ \hfill \\[0.5em]}
\date{\normalsize \flushleft  The  individuals  whose  names  and  signatures  appear  below  certify  that  the  narrative, diagrams,  figures,  tables,  calculations,  and  analyses  contained  within  this  document  are their original work except as otherwise cited.
\hfill \\ \hfill \\[0.5em]
\underline{Flory, David\space\space\space\space\space\space\space\space\space\space\space} \hspace{0.25in}
\underline{\space\space\space\space\space\space\space\space\space\space\space\space\space\space\space\space\space\space\space\space\space\space\space\space\space\space\space\space\space\space\space\space\space\space\space\space\space\space\space\space\space} \hspace{0.25in}
\underline{\today \space\space\space\space\space\space\space} \hspace{0.25in}\\
\hspace{1.8in} Signature \hspace{1.8in} Date \hfill \\ \hfill \\
\underline{Fran\c{c}a, Natasha\space\space\space\space\space\space} \hspace{0.25in}
\underline{\space\space\space\space\space\space\space\space\space\space\space\space\space\space\space\space\space\space\space\space\space\space\space\space\space\space\space\space\space\space\space\space\space\space\space\space\space\space\space\space\space} \hspace{0.25in}
\underline{\today \space\space\space\space\space\space\space} \hspace{0.25in}\\
\hspace{1.8in} Signature \hspace{1.8in} Date \hfill \\ \hfill \\
\underline{Franulovic, Franci \space\space} \hspace{0.25in}
\underline{\space\space\space\space\space\space\space\space\space\space\space\space\space\space\space\space\space\space\space\space\space\space\space\space\space\space\space\space\space\space\space\space\space\space\space\space\space\space\space\space\space} \hspace{0.25in}
\underline{\today \space\space\space\space\space\space\space} \hspace{0.25in}\\
\hspace{1.8in} Signature \hspace{1.8in} Date \hfill \\ \hfill \\
\underline{Gibbons, Chad \space\space\space\space\space\space\space} \hspace{0.25in}
\underline{\space\space\space\space\space\space\space\space\space\space\space\space\space\space\space\space\space\space\space\space\space\space\space\space\space\space\space\space\space\space\space\space\space\space\space\space\space\space\space\space\space} \hspace{0.25in}
\underline{\today \space\space\space\space\space\space\space} \hspace{0.25in}\\
\hspace{1.8in} Signature \hspace{1.8in} Date \hfill \\ \hfill \\
\underline{Sosa, Francisco \space\space\space\space\space\space\space} \hspace{0.25in}
\underline{\space\space\space\space\space\space\space\space\space\space\space\space\space\space\space\space\space\space\space\space\space\space\space\space\space\space\space\space\space\space\space\space\space\space\space\space\space\space\space\space\space} \hspace{0.25in}
\underline{\today \space\space\space\space\space\space\space} \hspace{0.25in}\\
\hspace{1.8in} Signature \hspace{1.8in} Date \hfill \\
}
%\date{12/29/2018}					%	Set permanent date or use date section as additional text real estate on the title page.
%\date{Sic et Non \\ Quid Faciendus Est}

%%%%%%%%%%%%%%%%%%%%%%%%%%%%%%%%%%%%%%%%%%%%%%%%%%%%%%%			DOCUMENT

%%%%%%%%%%%%%%%%%%%%%%%%%%%%%%%%%%%%%%%%%%%%%%%%%%%%%%
%					 													  %
%					 													  %
%					  ALWAYS BEGIN THE DOCUMENT WITH								  %
%					 													  %
%							\begin{document}									  %
%					 													  %
%					 													  %
%%%%%%%%%%%%%%%%%%%%%%%%%%%%%%%%%%%%%%%%%%%%%%%%%%%%%%

\begin{document}
\includepdf[pages=-,pagecommand={}]{./front_page/FDR_front_page_signed.pdf}

\pagenumbering{gobble}

\pagebreak

\section*{Acknowledgments}
\pagenumbering{roman}
\indent \indent
We as a team wish to thank Indus Instruments and Dr. Sridhar Madala for being the benefactors and sponsors of our Project.  Indus Instruments develops and creates electronic devices and software to meet the needs of various industries; for instance, they provide Baylor College of Medicine critical equipment for medical research.   Dr. Sridhar Madala has been generous with our time and was critical in the initial planning phase of the project.  Dr. Madala's familiarity with FCC and international wireless transmission regulations gave clear constraints and direction to this project.  Thus, we especially thank Dr. Sridhar Madala for agreeing to be HEC-2's technical advisor.

\pagebreak

\section*{Executive Summary}
\indent \indent
The team has designed and is prototyping a managed, 30 watt wireless resonant charger for use with lithium-ion battery packs. It shall be a versatile solution to the problem of powering autonomous mobile devices fitted with moderately sized battery packs of approximately four to six 18650 cells configured for 7.4 to 14.7 volts nominal output. With an estimated cost around \$300, it fills a gap between inexpensive inductive chargers in the 5 watt range and custom 90 watt robotic power systems that have an entry level price of \$2000.\\ \indent

Our charging system is made with two essential components: a transmitter and receiver. The transmitter is supplied by standard line voltage and will be responsible for safely delivering up to 30 watts of resonant power to the receiver when in range and appropriately positioned. It shall communicate status with the receiver over a Bluetooth link and shall enable or disable power transmission when requested.\\ \indent

The receiver shall communicate with the transmitter and to a user GUI over Bluetooth links, and optionally with the user’s own application (i.e. a robot microcontroller) over a serial link. It will be capable of delivering requested power transmission and charging status information and beginning or ending the charging process. It shall cease charging on receipt of an error status from the charging circuit and will notify the user to take corrective action. Under normal conditions it will deliver power to the charging control IC, which shall charge the attached battery pack.\\ \indent

The charger may be configured to charge 7.4 to 14.7 nominal Li-Ion battery cells, which must have internal protection circuitry in accordance with UL1642 and IEC61960. Optimal configurations would include a 7.4V pack rated for 3.2A charging, a 11.1V pack rated for 2.2A charging, or a 14.8V pack rated for 1.7A charging.\\ \indent

To best demonstrate the full potential of our project, the team is pursuing optional deliverables that should be completed if time permits once the core project is completed. These stretch goals include a mobile robot capable of charging itself for continuous wireless operation and integration with a smart Li-ion battery for detailed fuel gauge and battery health status.

\pagebreak

\tableofcontents

\pagebreak

\listoffigures

\pagebreak

\listoftables

\pagebreak

	%%%%%%%%%%%%%%%%%%%%%%%%%%%%%%%%%%%%%%%%%%
	%														 %
	%														 %
	%		\hfill fills in the remaining spaces of the given line with spaces			 %
	%														 %
	%					\\ ends line           							 %
	%														 %
	%	Determine the number of "\hfill \\ " iterations in accord with the number of lines		 %
	%				   within you abstract.							 %
	%														 %
	%														 %
	%%%%%%%%%%%%%%%%%%%%%%%%%%%%%%%%%%%%%%%%%%

	%%%%%%%%%%%%%%%%%%%%%%%%%%%%%%%%%%%%%%%%%%
	%														 %
	%														 %
	%		The primary purpose of an abstract is to give sufficient information		 %
	%					on your report to inform 						 %
	%		researchers, students, grant providers, corporate executives, professors,  	 %
	%				professionals, or the audience of your intention			 %
	%		whether or not either reading or purchasing your report is necessary.		 %
	%														 %
	%														 %
	%%%%%%%%%%%%%%%%%%%%%%%%%%%%%%%%%%%%%%%%%%

\pagenumbering{arabic}

%
%	Start with defining the problem you are trying to solve and why there is still a need to solve it
%
%	+ (Problem) User devices need wireless recharging solutions
%	+ (Why need to solve exists) Shortage of cost effective mid range wireless power transfer products in market.
%
%	Is this the only product in the market? <-- we answered this >:(
%
%	
%

\section{Project Description}
\indent \indent
Our team noted a need for users to charge medium power devices via wireless charging.  After further investigation we also determined that there is a shortage of cost effective medium power wireless chargers on the market.\\ \indent

Our project is a 30 watts nominal resonant wireless charger prototype for use with 4 to 6 cell lithium ion battery packs. It is managed by a microcontroller. It may be monitored and controlled by a user GUI or directly by the target application. Unlike existing customized and proprietary robotic charging systems, our product will charge a standard battery type and be suitable for both stand-alone operations and integration into the user's own design.\\ \indent

The team has been unable to discover any equivalent products to our own for retail. The most comparable product is Wibotic's Standard High Power System\cite{WiboSHPS}, a 90 watt magnetic resonance device that is marketed to businesses designing commercial drones and robotic systems. On the lower end, nearly all unbranded, low-cost wireless chargers that are available from mass online retailers supply no more than 5W via inductive charging. For a single industrial unit, we have received a price quote for approximately \$2000 USD. Individuals and small R\&D teams that search for suitable devices through online retailers will find that these low-end transmitters are not modular and are limited to one specific purpose such as charging cell phones or key-fobs.\\ \indent

Our charging system employs magnetic resonance coupling to charge a lithium ion battery pack, delivering between 15 and 30 watts of power. The power transmitter and receiver communicates as a unified system that can provide battery management, protect against overcharging, and provide both diagnostic and telemetric information to the user and to an optional serial connection with the powered application’s control circuitry. The charging system may be monitored and controlled by the user either through an attached LCD interface or a GUI from either a Bluetooth connected PC or smartphone.\\ \indent

This wireless charging alternative's intended market consists of hobbyists and prototype designers considering a self-docking direct electrical connection solution. This is the charging method used by the Roomba\cite{RoombaEduData}, which engages with a custom dock and charges using metal contacts. While this is a cost-effective solution for a mass-produced product, wireless charging is a superior choice for autonomous mobile devices that might have a wide variety of sizes and shapes. The benefits offered by our product's wireless charging include flexible placement of the charger, a compact charging area, greater tolerance for misalignment between the charger and the target device, and the absence of exposed electrical connections.  Additionally, this product would solve the same need for OEM producers who are interested in a ``turn-key'' wireless charging solution.\\

\pagebreak
\indent
To best demonstrate the full potential of our project, the team has specified optional deliverables that include a mobile robot capable of charging itself for continuous wireless operation, fully integrated with a smart Li-ion battery for detailed fuel gauge and battery health status.\\ \indent %% (May be retracted at a later date)

The team holds that a moderate power, low cost wireless charger with accessible telemetry is useful to a small but important market of robotics hobbyists and developers, who at present, are not being served by either costly, proprietary business-to-business solutions or the low power and poorly documented inductive chargers available on the hobby market.\\ \indent

Below in Figure 1, the general flow of power from the AC to DC Wall Converter to the end user's device and information from the user is shown.
\hfill 
\begin{figure}[h!]
\centering
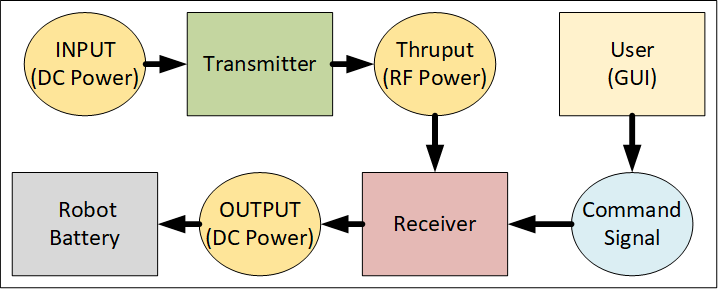
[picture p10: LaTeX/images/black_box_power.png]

\caption{Operation Story Block Diagram}
\end{figure}

\indent
The project is divided between two teams: the hardware team and the software team.

\subsection{Software Team's Focus for Project}

\indent \indent
The software team is focused on two programs: the microcontrollers' firmware and the graphical user interface (GUI) software application.  The firmware operates the transmitter or receiver while the GUI allows for the user to readily monitor and interact throughout the charging process.

\hfill
\pagebreak
\hfill

\subsection{Hardware Team's Focus for Project}

\indent \indent
The hardware team is focused on producing three modular components: the receiver PCB, the transmitter PCB, and the coil module.  The image below displays how these modules operate together.

%%%%%%%%%%%%%%%

\begin{figure}[h!]
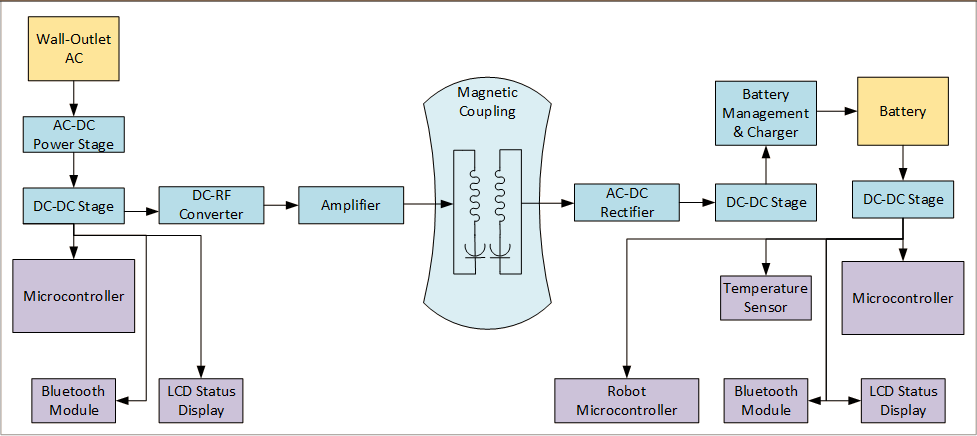
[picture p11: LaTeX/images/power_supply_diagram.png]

\caption{Power Supply of Transmitter and Receiver Subsystems}
\end{figure}
\indent
While the image below explicitly separates out the receiver and transmitter modules.  Note that the completed PCB boards have a power transferring coil module affixed to them individually.
\begin{figure}[h!]
\centering
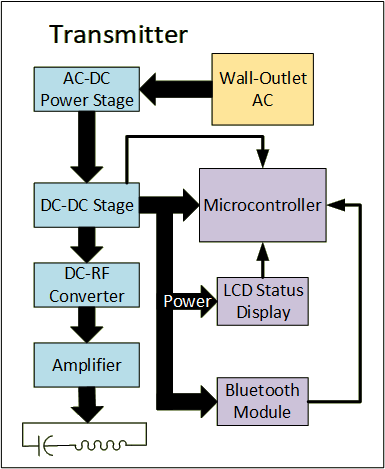
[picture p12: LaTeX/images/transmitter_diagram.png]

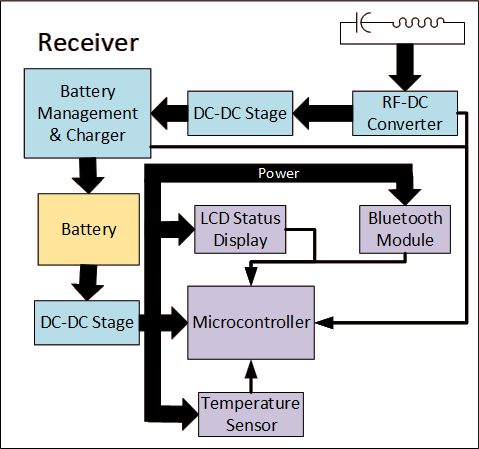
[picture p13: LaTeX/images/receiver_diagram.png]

\caption{Transmitter and Receiver Block Diagrams}
\end{figure}
\hfill \\

%%%%%%%%%%%%%%%%%%%%%%%%5

\hfill 
\pagebreak
\hfill

\section{Final Design Specifications}

\indent
Table 1 below shows the specs of the receiver subsystem.
\hfill

	% Wrap Table Example

%\begin{wraptable}[1]{2}[3]{4}
%...
%\end{wraptable}
%Number of lines (optional)
%“r” for right and “l” for left figure placement.
%Overhang (optional)
%Width to be reserved.

%\newcolumntype{C}{>{\centering\arraybackslash} m{6cm} }  %# New column type
%\newcolumntype{R}{>{\raggedleft \arraybackslash} m{6cm} }  %# New column type

\begin{table}[h!]
\centering
\caption{Receiver Specifications}
\begin{tabular} {| r | c | }
\hline
\parbox{0.225\linewidth}{\raggedleft \hfill \\ Charge time \\  (Per 4Ah Battery Packs)\\} & ~ 5 Hours Max\\
\hline
Battery pack voltage & 14.2 V  \\
\hline
\parbox{0.25\linewidth}{\raggedleft \hfill \\  Coupling Efficiency \\ Transmitter to Receiver\\[0.4em]} & 90\%\\
\hline
\parbox{0.25\linewidth}{\raggedleft \hfill \\  AC-DC \\ Conversion Efficiency} & 80\%\\
\hline
\parbox{0.25\linewidth}{\raggedleft \hfill \\  Charging Controller \\  DC-DC converter} & 85\%\\[0.4em]
\hline
\parbox{0.25\linewidth}{\raggedleft \hfill \\  Overall Receiver \\  Conversion Efficiency} & 61.2\%\\[0.4em]
\hline
\parbox{0.25\linewidth}{\raggedleft \hfill \\  Maximum Battery \\ Charging Current} &   \parbox{0.225\linewidth}{\centering 1.25 A (14.7 V \\ battery pack)}\\
\hline
\parbox{0.25\linewidth}{\raggedleft \hfill \\  Charger Subsystem \\  Charge Protocol} &  \parbox{0.225\linewidth}{\centering \hfill \\  Constant Current \\Constant Voltage \\(Li-ION Battery)}\\
\hline
Battery Type &   \parbox{0.25\linewidth}{\centering\hfill \\  Lithium-Ion \\ (4 x18650 in Series or 2P4S Configuration)}\\
\hline
\parbox{0.25\linewidth}{\raggedleft \hfill \\  Power Negotiation} &  \parbox{0.225\linewidth}{\centering\hfill \\ Bluetooth 5 LE\\}\\
\hline
\parbox{0.25\linewidth}{\raggedleft \hfill \\  Transmitter Locator \\ Method \\[0.4em]} &   \parbox{0.225\linewidth}{\centering \hfill \\  RF Localization  [Bluetooth]}\\
\hline
Deliverable Demo &   \parbox{0.25\linewidth}{\centering \hfill \\  Self-Moving Device (Robot)}\\
\hline
Telemetry &   \parbox{0.25\linewidth}{\centering \hfill \\  Report State \\to GUI Device}\\[0.4em]
\hline
LCD display &   \parbox{0.25\linewidth}{\centering \hfill \\  Diagnostic Character \\String Display}\\
\hline
\end{tabular}
\end{table}
 
 \pagebreak
 
\indent 
Table 2 below shows the specs of the transmitter subsystem.  

\hfill

\begin{table}[h!]
\centering
\caption{Transmitter Specifications}
\begin{tabular} {| r | c | }
\hline
Operating frequency & 13.56 MHz\\
\hline
RF power output & 30 W\\
\hline
Max operating range & 5 cm\\
\hline
DC Power supply  & 48 V 1.25 A max.  \\
\hline
\parbox{0.275\linewidth}{\raggedleft  Conversion Efficiency\\ DC-AC\\[0.4em]}  & 80\%\\
\hline
Telemetry &\parbox{0.24\linewidth}{\centering Report State \\to GUI Device\\[0.4em]}\\
\hline
\end{tabular}
\end{table}

\indent
Table 3 below shows the communication specifications. 
\hfill

\begin{table}[h!]
\centering
\caption{Communication Link Specifications}
\begin{tabular} {| r | c | }
\hline
\parbox{0.275\linewidth}{\raggedleft Communication Medium \\[0.4em]} &  \parbox{0.24\linewidth}{\centering Bluetooth 5 LE}\\
\hline
\parbox{0.275\linewidth}{\raggedleft Protocol} &  \parbox{0.24\linewidth}{\centering \hfill\\[0.1em] L2CAP \\ (RFCOMM)\\[0.5em]}\\
% L2CAP === Logical Link Control and Adaptation Protocol (Host Stack --> One Controller with multiple devices pairing)
\hline
\end{tabular}
\end{table}

\indent
 Table 4 below shows the GUI software specifications.
 \hfill

\begin{table}[h!]
\centering
\caption{GUI Specifications}
\begin{tabular} {| r | c | }
\hline
\parbox{0.275\linewidth}{\raggedleft GUI OS} & \parbox{0.24\linewidth}{\centering \hfill \\ WinOS, IOS, \\ Linux, \& Android}\\[0.4em]
\hline
\parbox{0.275\linewidth}{\raggedleft License} &    \parbox{0.24\linewidth}{\centering LGPL 3.0} \\
\hline
\parbox{0.275\linewidth}{\raggedleft Software Architecture} &   \parbox{0.24\linewidth}{\centering \hfill \\ Model-Controller-View (MCV) Architecture\\[0.4em]} \\
\hline
\parbox{0.275\linewidth}{\raggedleft Delivery Model} &   \parbox{0.24\linewidth}{\centering \hfill \\ Open Source \\ (Free App Download)} \\[0.4em]
\hline
%\parbox{0.45\linewidth}{\raggedleft Deployment Model} &   \parbox{0.45\linewidth}{\centering Open Source / Free To Download App} \\
%\hline
\end{tabular}
\end{table}

\pagebreak

\subsection{Feasibility Study}

\indent \indent
The design consists of two subsystems: the transmitter and the receiver. This product is expected to be used by hobbyists and prototype designers for different applications that require contactless charging. There is no similar device available in the price range from \$200 to \$400.  The expected cost of the charger system is \$300. There are some commercial chargers available right now and the cost of that system is \$2000. The price of \$300 per system will make wireless charging affordable for hobbyists and freelance hardware developers.\\

\indent
The design tools such as Altium designer and Multisim simulator are available free of charge to all group members using the provided UT Tyler license. Also, parts manufacturers are providing free simulation and evaluation tools for development. In addition to the software evaluation kits may be required for testing certain parts of the system such as the microcontroller, Bluetooth module, and the battery charger controller. Most of those evaluation modules are already purchased and they are available to team members. Evaluation kits are purchased by Indus Instruments.\\

\indent
The system is designed such that it uses standard components that are available at any electronic components store and they can be purchased without restrictions. PCB fabrication will be given to a company located in China that is offering quick turnaround PCB fabrication and fast shipping. Components purchasing and printed circuit board assembly will be done at Indus Instruments. Indus Instruments have all the necessary equipment that can handle surface mount components.\\

\indent
All test equipment required for development and testing will be available. Indus Instruments will provide space and necessary test equipment for the wireless charging system prototype evaluation and testing.\\

\indent
The final product cost is estimated at around \$300 (for small quantities). Most likely for larger quantities, it is possible to decrease the cost even more. 

\pagebreak

\subsection{Microcontroller}

\indent \indent
There are four aspects to analyze: economics, technical, legal, and scheduling. A single MSP430FR5994 part costs about \$3 to \$4, while the MSP-EXP430FR5994 LaunchPad kit costs \$16.99. Considering the team only needs two of these microcontrollers (one for the transmitter and one for the receiver), this is an economic and reasonable cost. \cite{MSP430FR599x}  \cite{testKit}. On the technical side, this microcontroller’s memory, voltage supply limitations, UART and I$^2$Cmode specifications, and overall low power consumption makes it the ideal model for our project needs \cite{MSP430FR599x}. Some of the most important standards TI’s MSP430FR5994 complies with include ANSI, JEDEC, and ESDA \cite{MSP430FR599x}. Lastly, the team already has in hands the LaunchPad kit for the microcontroller. The individual microcontrollers are also ready-to-purchase items with delivery times of less than 7 days. More testing will be done once the team has the first PCB design in hands.

\subsection{Transmitter Coil}

%%%%%%  COME BACK TO ME %%%%%%%%%%%%%%%%%%%%%%%%%%%%%%%%%%%%%%%%%%%%%%%%%%%%%%%%%%%%%%%%%%%%%%%%%%%%%%%%%%%%%%%%%%%%%%%%%%%%%%%%%%%%%%%%%%%%%%%%%%%%%%%%%%%%%%%%%%%%%%%%%%%%%%%%%%%%%%%%%%%%%%%%%%%%%%%%%%%%%%%%%%%%%%%%%%%%%%%%%%%%%%%%%%%%%%%%%%%%%%%%%%%%%%%%%%%%%%%%%%%%%%%%%%%%%%%%%%%%%%%%%%%%%%%%%%%%%%%%%%%%%%%%%%%%%%%%%%%%%%%%%%%%%%%%%%%%%%%%%%%%%%%%%%%%%%%%%%%%%%%%%%%%%%%%%%%%%%%%%%%%%%%%%%%%%%%%%%%%%%%%%%%%%%%%%%%%%%%%%%%%%%%%%%%%%%%%%%%%%%%%%%%%%%%%%%%%%%%%%%%%%%%%%%%%%%%%%%%%%%%%%%%%%%%%%%%%%%%%%%%%%%%%%%%%%%%%%%%%%%%%%%%%%%%%%%%%%%%%%%%%%%%%%%%%%%%%%%%%%%%%%%%%%%%%%%%%%%%%%%%%%%%%%%%%%%%%%%%%%%%%%%%%%%%%%%%%%%%%%%%%%%%%%%%%%%%%%%%%%%%%%%%%%%%%%%%%%%%%%%%%%%%%%%%%%%%%%%%%%%%%%%%%%%%%%%%

\indent \indent
The circular planar coil was the most inexpensive approach, the copper tubing to make the coils has an approximate value of  \$15.99. The design properties also significantly contributed to reducing the complexity of acquiring the main coil parameters. It was important to take this factor into account because of the time constraint of two months. In order to reduce the complexity in our project, the spiral planar design was the best option.\\

\indent
The calculation of the inductance formula in the planar spiral design was easier to acquire than the other two proposed solutions. This was crucial because it significantly gave the project a higher chance of matching the predestined inductance of the circuit requirement of .909 $\mu$H.\\

\indent
The economical and ethical considerations did not affect our decision making as much, due to the fact that there were not many differences. Furthermore, this design was appropriate for our project and the team does have the budget, resources and time to successfully to implement this design. \\

\indent
The planar spiral coil design allows the project to more reduces the complexity of the formulas implemented in the calculations. 

%%%%%%%%%%%%%%%%%%%%%%%%%%%%%%%%%%%%%%%%%%%%%%%%%%%%%%%%%%%%%%%%%%%%%%%%%%%%%%%%%%%%%%%%%%%%%%%%%%%%%%%%%%%%%%%%%%%%%%%%%%%%%%%%%%%%%%%%%%%%%%%%%%%%%%%%%%%%%%%%%%%%%%%%%%%%%%%%%%%%%%%%%%%%%%%%%%%%%%%%%%%%%%%%%%%%%%%%%%%%%%%%%%%%%%%%%%%%%%%%%%%%%%%%%%%%%%%%%%%%%%%%%%%%%%%%%%%%%%%%%%%%%%%%%%%%%%%%%%%%%%%%%%%%%%%%%%%%%%%%%%%%%%%%%%%%%%%%%%%%%%%%%%%%%%%%%%%%%%%%%%%%%%%%%%%%%%%%%%%%%%%%%%%%%%%%%%%%%%%%%%%%%%%%%%%%%%%%%%%%%%%%%%%%%%%%%%%%%%%%%%%%%%%%%%%%%%%%%%%%%%%%%%%%%%%%%%%%%%%%%%%%%%%%%%%%%%%%%%%%%%%%%%%%%%%%%%%%%%%%%%%%%%%%%%%%%%%%%%%%

\subsection{Transmitter}

\indent \indent
The transmitter class-E amplifier circuit was simulated at an efficiency of 98\%. The actual transmitter efficiency would be around 90\%. In the simulation, it was determined that the current required to power the class-E amplifier is 0.9 A at 30 V. The power for the transmitter will be supplied by using an external 48 V AC to DC converter followed by a step-down converter in the transmitter subsystem.\\

\pagebreak

\indent
The main concern in this subsystem is the immunity of the supporting circuits to the RF electromagnetic field generated by the transmitter coil. The transmitter coil placement must be done such that the electromagnetic field has minimal effects on the electronic circuits in the transmitter. The transmitter sensitive electronic parts may require EMI shields.\\

\indent
During the simulation, the high voltage across the coil was observed. The highest voltage observed was 320 V$_{pp}$. That voltage poses a serious electric shock hazard. Therefore, the transmitter coil insulation must be capable of withstanding voltages that are in the 500V to 1kV range to provide a safety margin for the design. One way of achieving this is to make a plastic box that would contain the transmitter coil and have insulation that is capable of withstanding voltages in the 500 V to 1000 V range.  \\

\indent
Heat dissipation in the Class E amplifier circuit is expected to be around 3W (based on the efficiency of 90\%). That dissipation will occur in inductors, capacitors (due to ESR), and the amplifier transistor. The transistor will have a proper heatsink to prevent overheating. Since the dissipation in the transistor is very small (on-resistance is 50 mΩ) the proper thermal management will be achieved on the printed circuit board. Coils used in the transmitter will be designed such that the col resistance is minimized which also will decrease the heat dissipation in the transmitter circuit.

\subsection{Receiver}

\indent \indent
There is a possibility that the receiver RF to DC stage performs with higher losses than the losses that were determined in the simulation. According to the simulation data, the RF to DC conversion will be 81\% efficient. In the system specification, the conversion efficiency is set to 80\%. It is important to keep efficiency above 80\% to prevent excessive heat generation. If received power is 25W and efficiency is  80\% then power dissipation is 5 W.   \\

\indent
The excessive heat may have adverse effects on battery life and the speed of charging \cite{TPSM265R1}. A higher temperature environment requires lower charging currents to prevent further temperature rise and damage to the battery cells. Also, excessive heat generation must be minimized to avoid the use of fans and large heat-sinks. Heat-sinks and fans would increase the cost and the size of our product.   If during the prototype test phase efficiency drops below 80\% the circuit must be redesigned to achieve the target specification efficiency. \\

\pagebreak

\indent
One problem that is likely to occur is the interference in the battery charging and communication link circuits caused by a strong electromagnetic field generated by the transmitter coil. Even though all good practices will be followed for the circuit board design the electromagnetic interference still may not be prevented. Charging circuit disruption can cause battery failure due to overcharging or overheating. If this problem occurs the additional EMI shielding will be required. The shielding includes placing metal boxes over sensitive electronic subcircuits and placing additional filters in series with DC power supplies for sensitive parts such as a microcontroller, Bluetooth module, and charger controller.

\subsection{Thermal Considerations for 3.3V and 5V Voltage Regulators}

\indent \indent
According to the simulation data both parts have small power dissipation. The largest power dissipation is 0.18 W (5.0V regulator).\\

\indent
The graph below provides thermal resistance junction to ambient as a function of the printed circuit board. The equation below can be used to find the required thermal resistance junction to ambient ($\Theta_{JA}$). The estimated ambient temperature in the transmitter is 45$^{\circ}$C.

\begin{equation}
\Theta_{JA} = \frac{125^\circ C - T_{A(max)}}{P_{D(max)}} \Bigg[\frac{^\circ C}{W}\Bigg]
\end{equation}

\noindent
$\Theta_{JA}$ = $\frac{125-45}{0.18}$ = 444.44 \Big[$\frac{^\circ C}{W}$\Big]

\noindent
The estimated transmitter PCB area will be around 100cm2. Given the board size and thermal resistance vs. board size, those regulators will have a proper heatsink.

\begin{figure}[h!]
\centering
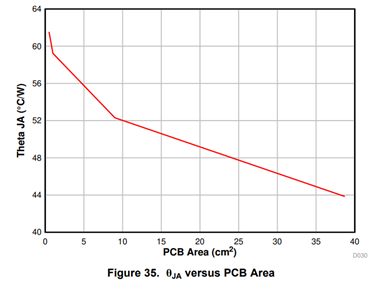
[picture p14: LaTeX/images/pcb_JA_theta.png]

\caption{Thermal Resistance vs. PCB Area \cite{TPSM265R1}}
\end{figure}

\pagebreak

\noindent
Thermal considerations (for class E amplifier voltage regulator (30V, 1.0A buck converter) 

\begin{equation}
T_{A(max)} = T_{J(max)} - R_{TH} \cdot P_{TOT}
\end{equation}
\noindent
$\cdot $ P$_{TOT}$ is the total device power dissipation in [W]
\\
\noindent
$\cdot $ T$_A$ is the ambient temperature in [$^\circ$C]
\\
\noindent
$\cdot $ T$_J$ is the junction temperature in [$^\circ$C]
\\
\noindent
$\cdot $ R$_{TH}$ is the thermal resistance of the package \Big[$\frac{^\circ C}{W}$\Big]
\\
\noindent
$\cdot $ T$_{A(max)}$ is the maximum ambient temperature in [$^\circ$C]
\\
\noindent
$\cdot $ T$_{J(max)}$ is the maximum junction temperature in [$^\circ$C]
\\

\noindent
The expected ambient temperature is 40$^\circ$C (that is temperature inside the transmitter enclosure).\\
Thermal resistance for a standard board ($\Theta_{JA}$) is 62.5\Big[$\frac{^\circ C}{W}$\Big] \cite{TPS54160}.\\
From the simulation the total power dissipation is 1 W.\\
From the recommended operating conditions the maximum junction temperature is 150$^\circ$C \cite{TPS54160}.\\
Based on the data from the simulation and the datasheet the maximum ambient temperature can be determined\\
T$_{A(MAX)}$ = T$_{J(MAX)}$ - R$_{TH}$*P$_{TOT}$ \\
T$_{A(MAX)}$ = 150 – 62.5*1 = 87.5$^\circ$C

\hfill
\pagebreak
\hfill

\indent
The expected ambient temperature is lower than the maximum temperature calculated based on simulation data. Therefore, this part will operate within specified recommended conditions in the datasheet.

\subsection{Charging Subsystem}

\indent \indent
The LTC4162-L is designed to manage a power path between an external input power source Vin, an output power V$_{out}$, and an installed battery pack. When external input power greater than the battery voltage is available at V$_{in}$, the LTC4162 will route V$_{in}$ to V$_{out}$ and charge the connected battery. If external power is interrupted or falls below V$_{bat}$, battery power will be automatically routed to V$_{out}$. As long as the battery has charge or a power source exists at V$_{in}$, V$_{out}$ will be supplied with power, but the voltage will range from V$_{bat}$ to V$_{in}$. In order to provide consistent voltage to the target device output power should be drawn directly from the battery. Leaving V$_{out}$ unused allows the maximum power point tracking feature to operate with optimal efficiency.\\

\indent
The LTC4162 draws power directly from Vout and has its own internal LDO linear regulators. All other components of the wireless receiver PCB must be powered by an appropriate DC-DC stage at V$_{out}$ that can convert any potential input voltage (i.e. 7.4-35 V) to the required operating voltages of 5 V and 3.3 V. In the event that the battery is severely depleted and cannot power the microprocessor and Bluetooth interface, it will be necessary for the transmitter to be capable of initiating charging independently.\\

\indent
Since the LTC4162 has only an internal buck voltage regulator, the wireless power receiver subsystem must provide power to Vin that is higher than the voltage of the battery but below the maximum input voltage of 35V.\\

\indent
The LTC4162 approaches 95\% efficiency at recommended switching frequency when the input voltage is no more than approximately 5V above battery charging voltage, and surpasses 90\% in less ideal configurations. Heat losses will be in the range of three watts or less. It has a $\Theta_{JC}$ of 3.4 \Big[$\frac{^\circ C}{W}$\Big] and will be soldered to a four-layer PCB. The team does not anticipate any thermal management issues with this circuit.

\subsection{Battery Considerations}
\indent
Li-Ion batteries offer superb performance and high energy density, but require special attention to safety. Under normal circumstances the LTC4162-L will monitor battery voltage and avoid overcharging. A NTC thermistor will allow the LTC4162 to monitor local charging temperatures and limit current in accordance with JEIDA recommendations.\\

\pagebreak

\indent
For safety reasons, the team requires stricter battery specifications than originally planned. While our charger’s thermistor can limit charging current in response to ambient temperature extremes, it cannot monitor individual cells--particularly if the battery pack is intended to be modular. While it can recognize and respond to abnormal battery voltages or short conditions, it cannot automatically determine maximum safe charging current. Any battery pack used must have a maximum charge current greater than the maximum current delivery of the charger. Battery packs must also meet UL1642 and IEC61960 standards and contain internal protection circuitry to limit charge and discharge currents and protect against thermal runaway.\\

\indent
The LTC4162 can deliver a maximum of 3.2 amps and has an efficiency of up to 95\%. Assuming optimal efficiency and 26 W output from the wireless receiver, the charging voltage must be at least $\frac{25 W}{3.2 A}$ = 7.8 V in order to fully utilize the available power. Since the voltage of a typical Li-Ion cell is 3.7 V and the charging voltage is 4.2 V, the target battery pack should consist of two or more cells in series. The LTC4162 supports 1 to 8 cell series arrangements provided the input voltage is adequate. Optimal arrangements would include a 7.4V pack rated for 3.2 A charging, a 11.1 V pack rated for 2.2 A charging, or a 14.8 V pack rated for 1.7 A charging. The number of cells is set by selection pins and may be configured by a DIP switch or jumpers. It is not necessary to specify a specific number of cells for suitable battery packs, provided that they meet UL1642 and IEC61960 standards. The optimal balance of safe charging rates and performance will likely be found with packs utilizing six to eight 18650 cells or the equivalent. The power delivery estimates above are optimistic and actual power delivery from the charger may not reach these levels. As prototyping progresses, it will be possible to refine battery recommendations and expected charging times.\\

\indent
Ideally, up to 25 W will be delivered to the battery pack, making the battery the largest potential source of heat in our system. Since the battery pack is intended to be a modular, removable component with flexible specifications, it will not necessary for it to be enclosed with the wireless receiver PCB and receiving coil. It will be connected by an appropriate low-loss cable and connector, and exact placement will be determined by the user application. For this reason, the team has specified that only battery packs with internal temperature monitoring and protection circuitry should be used with this charger.\\

\indent
Our original specifications suggested that the charging subsystem would be capable of detailed monitoring of battery health and charge state. The team has learned that this type of information must be obtained at the individual cell level by a specialized controller which is usually integrated into the battery pack itself. Our charge subsystem can only recognize an approaching low-battery condition by a drop in voltage, and cannot estimate battery capacity except by calculation using charging voltage, charge times and currents, and such data would be of limited use considering battery aging and user-replaceability. It will be possible to notify the user and target device of a drop in battery voltage, but more detailed fuel gauge and battery health information will require an SMBus enabled smart battery. An I$^2$C line on the MSP430FR5994 will be reserved for communication with an optional SMBus capable smart battery pack. If feasible, optional battery pack telemetry may be polled by firmware and reported to the user along with the data already available from the LTC4162.\\

\indent
All the parts and design resources needed to complete the charging and power subsystem are readily available. Constructing this subsystem within the projected time-frame is feasible.

\begin{table}[h!]
\centering
\caption{Final Design's Charging Subsystem  Specifications}
\begin{tabular} {| r | c | }
\hline
\parbox{0.3\linewidth}{\raggedleft DC-DC stage from wireless receiver to V$_{in}$} &   \parbox{0.65\linewidth}{\hfill \\
May not be necessary, pending further determination of wireless receiver output voltage}\\
\hline
\parbox{0.3\linewidth}{\raggedleft DC-DC stage from V$_{out}$} &   \parbox{0.65\linewidth}{\hfill \\
5V at 100mA; 3.3V at 100 mA}\\
\hline
\parbox{0.3\linewidth}{\raggedleft Battery Requirements} &   \parbox{0.65\linewidth}{\hfill \\
UL1642 and IEC61960 compliant Li-Ion packs with 7.4-15 V$_{DC}$ nominal output voltage}\\
\hline
\parbox{0.3\linewidth}{\raggedleft \vspace{0.4em} Maximum Charging Current} &   \parbox{0.65\linewidth}{\hfill \\
3.2A (7.4V); 2.2A (11.1V); 1.7A (14.8V)}\\
\hline
\parbox{0.3\linewidth}{\raggedleft \vspace{0.4em} Provision for optional smart battery health and fuel gauge monitoring} &   \parbox{0.65\linewidth}{\hfill \\
Reserved I$^2$C line from MSP430FR5994 with buffering}\\
\hline
\end{tabular}
\end{table}
\hfill \\

\subsection{Microcontroller Considerations}

\indent \indent
The MSP430FR5994 has a body size that ranges from 6mm by 6mm to 12mm by 12mm depending on the package the group purchases, 8KB RAM, 68 GPIO pins, 4 I$^2$C, 4 UART, up to four serial communication ports, and 20 ADC channels. The MSP430 series include limitations that range from safety to performance \cite{MSP430FR599x}.\\

\noindent
Relevant limitations to the project include:\\

\noindent
1. ESD (Electrostatic discharge) ratings. For a human-body model, safe discharge ratings are around 500 V to 1000 V, while for a charged-device model, safe discharge ratings are around 250 V. These regulations are taken from JEDEC JS-001 and JESD22-C101 respectively \cite{MSP430FR599x}.\\

\noindent
2. Absolute maximum ratings: voltage applied to any pin must be within -0.3 V to 4.1 V, voltage difference between DVCC and AVCC pins must stay within -0.3 V to 0.3 V (if not, writing errors could occur to RAM and FRAM), and current at any device pin must have a maximum of  -2 to 2 mA \cite{MSP430FR599x}.\\

\noindent
3. Supply voltage applied should be within 1.8 V to 3.6 V, maximum ACLK frequency should be 50 kHz, and maximum SMCLK frequency should be 16 MHz \cite{MSP430FR599x}.\\

\noindent
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

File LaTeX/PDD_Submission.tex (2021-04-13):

%		For public use only, fair use laws still apply
%		A tutorial template created by Chad Gibbons

%	I recommend for generic help the following website
%	http://www.emerson.emory.edu/services/latex/latex_toc.html
%	There are many good websites and forums for LaTeX
%
%	If you have a problem, google it. (ex. "How do I start my page numbers at a different number")

%%%%%%%%%%%%%%%%%%%%%%%%%%%%%%%%%%%%%%%%%%%%%%%%%%%%%%
%					 													  %
%					 													  %
%					  ALWAYS BEGIN THE PROGRAM WITH								  %
%					 													  %
%						\documentclass{class_type}								  %
%																		  %
%		Different class types have different commands associated with them, similar to header files			  %
%					 													  %
%					 													  %`
%%%%%%%%%%%%%%%%%%%%%%%%%%%%%%%%%%%%%%%%%%%%%%%%%%%%%%

\documentclass[12pt]{article}
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

\title{\Large \textbf{The University of Texas at Tyler\\
College of Engineering and Computer Science\\
Tyler, TX 75799\\
\hfill \\
\hfill \\[0.5em]
Primary Design Document Draft \\ For\\[0.5em]
Wireless Charger Project}}		%note left quote command vs " = \textquotedblright
%%  FIX FONT of Sub Sub Title  >> It should fit in with the text below. <<
\author{\large \hfill \\[0.5em] \textbf{A design project to fulfill the requirements of Senior Design}\\ \textbf{ 
in the Department of Electrical Engineering}\\ \textbf{ 
at The University of Texas at Tyler
}\hfill \\ \hfill \\[0.5em]}
\date{\normalsize \flushleft  The  individuals  whose  names  and  signatures  appear  below  certify  that  the  narrative, diagrams,  figures,  tables,  calculations,  and  analyses  contained  within  this  document  are their original work except as otherwise cited.
\hfill \\ \hfill \\[0.5em]
\underline{Flory, David\space\space\space\space\space\space\space\space\space\space\space} \hspace{0.25in}
\underline{\space\space\space\space\space\space\space\space\space\space\space\space\space\space\space\space\space\space\space\space\space\space\space\space\space\space\space\space\space\space\space\space\space\space\space\space\space\space\space\space\space} \hspace{0.25in}
\underline{\today \space\space\space\space\space\space\space} \hspace{0.25in}\\
\hspace{1.8in} Signature \hspace{1.8in} Date \hfill \\ \hfill \\
\underline{Franca, Natasha\space\space\space\space\space\space} \hspace{0.25in}
\underline{\space\space\space\space\space\space\space\space\space\space\space\space\space\space\space\space\space\space\space\space\space\space\space\space\space\space\space\space\space\space\space\space\space\space\space\space\space\space\space\space\space} \hspace{0.25in}
\underline{\today \space\space\space\space\space\space\space} \hspace{0.25in}\\
\hspace{1.8in} Signature \hspace{1.8in} Date \hfill \\ \hfill \\
\underline{Franulovic, Franci \space\space} \hspace{0.25in}
\underline{\space\space\space\space\space\space\space\space\space\space\space\space\space\space\space\space\space\space\space\space\space\space\space\space\space\space\space\space\space\space\space\space\space\space\space\space\space\space\space\space\space} \hspace{0.25in}
\underline{\today \space\space\space\space\space\space\space} \hspace{0.25in}\\
\hspace{1.8in} Signature \hspace{1.8in} Date \hfill \\ \hfill \\
\underline{Gibbons, Chad \space\space\space\space\space\space\space} \hspace{0.25in}
\underline{\space\space\space\space\space\space\space\space\space\space\space\space\space\space\space\space\space\space\space\space\space\space\space\space\space\space\space\space\space\space\space\space\space\space\space\space\space\space\space\space\space} \hspace{0.25in}
\underline{\today \space\space\space\space\space\space\space} \hspace{0.25in}\\
\hspace{1.8in} Signature \hspace{1.8in} Date \hfill \\ \hfill \\
\underline{Sosa, Francisco \space\space\space\space\space\space\space} \hspace{0.25in}
\underline{\space\space\space\space\space\space\space\space\space\space\space\space\space\space\space\space\space\space\space\space\space\space\space\space\space\space\space\space\space\space\space\space\space\space\space\space\space\space\space\space\space} \hspace{0.25in}
\underline{\today \space\space\space\space\space\space\space} \hspace{0.25in}\\
\hspace{1.8in} Signature \hspace{1.8in} Date \hfill \\
}
%\date{12/29/2018}					%	Set permanent date or use date section as additional text real estate on the title page.
%\date{Sic et Non \\ Quid Faciendus Est}

%%%%%%%%%%%%%%%%%%%%%%%%%%%%%%%%%%%%%%%%%%%%%%%%%%%%%%%			DOCUMENT

%%%%%%%%%%%%%%%%%%%%%%%%%%%%%%%%%%%%%%%%%%%%%%%%%%%%%%
%					 													  %
%					 													  %
%					  ALWAYS BEGIN THE DOCUMENT WITH								  %
%					 													  %
%							\begin{document}									  %
%					 													  %
%					 													  %
%%%%%%%%%%%%%%%%%%%%%%%%%%%%%%%%%%%%%%%%%%%%%%%%%%%%%%

\begin{document}
%\maketitle
\includepdf[pages=-,pagecommand={}]{./front_page/FDR_front_page_signed.pdf}

\pagenumbering{gobble}

\pagebreak

\section*{Executive Summary}
\pagenumbering{roman}
\indent \indent
The team proposes to design and prototype a managed, 30 watt wireless resonant charger for use with lithium-ion battery packs. It will be a versatile solution to the problem of powering autonomous mobile devices fitted with moderately sized battery packs of approximately four to six 18650 cells configured for 7.4 to 14.7 volts nominal output. With a preliminary cost estimate of \$300, it fills a gap between inexpensive inductive chargers in the 5 watt range and custom 90 watt robotic power systems with an entry level price of \$2000.\\ \indent

Our charging system will be made of two essential components: a transmitter and receiver. The transmitter will be supplied by standard line voltage and will be responsible for safely delivering up to 30 watts of resonant power to the receiver when in range and appropriately positioned. It will communicate status with the receiver over a Bluetooth link and will enable or disable power transmission when requested.\\ \indent

The receiver will communicate with the transmitter and to a user GUI over Bluetooth links, and optionally with the user’s own application (i.e. a robot microcontroller) over a serial link. It will be capable of delivering requested power transmission and charging status information and beginning or ending the charging process. It will disable charging on receipt of an error status from the charging circuit and will notify the user to take corrective action. Under normal conditions it will deliver power to the charging control IC, which in turn will charge the attached battery pack.\\ \indent

The charger may be configured to charge 7.4 to 14.7 nominal Li-Ion battery cells, which must have internal protection circuitry in accordance with UL1642 and IEC61960. Optimal configurations would include a 7.4V pack rated for 3.2A charging, a 11.1V pack rated for 2.2A charging, or a 14.8V pack rated for 1.7A charging.\\ \indent

To best demonstrate the full potential of our project, the team has specified optional deliverables that will be completed if time permits once the core project is completed. These stretch goals include a mobile robot capable of charging itself for continuous wireless operation and integration with a smart Li-ion battery for detailed fuel gauge and battery health status.\\

\pagebreak

\tableofcontents

\pagebreak

\listoffigures

\pagebreak

\listoftables

\pagebreak

	%%%%%%%%%%%%%%%%%%%%%%%%%%%%%%%%%%%%%%%%%%
	%														 %
	%														 %
	%		\hfill fills in the remaining spaces of the given line with spaces			 %
	%														 %
	%					\\ ends line           							 %
	%														 %
	%	Determine the number of "\hfill \\ " iterations in accord with the number of lines		 %
	%				   within you abstract.							 %
	%														 %
	%														 %
	%%%%%%%%%%%%%%%%%%%%%%%%%%%%%%%%%%%%%%%%%%

	%%%%%%%%%%%%%%%%%%%%%%%%%%%%%%%%%%%%%%%%%%
	%														 %
	%														 %
	%		The primary purpose of an abstract is to give sufficient information		 %
	%					on your report to inform 						 %
	%		researchers, students, grant providers, corporate executives, professors,  	 %
	%				professionals, or the audience of your intention			 %
	%		whether or not either reading or purchasing your report is necessary.		 %
	%														 %
	%														 %
	%%%%%%%%%%%%%%%%%%%%%%%%%%%%%%%%%%%%%%%%%%

\pagenumbering{arabic}

\section{Project Description}
\indent \indent
Our project is to design and prototype a 30 watts nominal resonant wireless charger for use with 4 to 6 cell lithium ion battery packs. It will be microcontroller managed and may be monitored and controlled by a user GUI or directly by the target application. Unlike existing customized and proprietary robotic charging systems, our product will charge a standard battery type and be suitable for both stand-alone operation and integration into the user's own design.\\ \indent

The team has been unable to discover any equivalent to our intended product for retail. The closest comparable product is a 90 watt magnetic resonance device that is marketed to businesses designing commercial drones and robotic systems. On the lower end, nearly all unbranded, low-cost wireless chargers that are available from mass online retailers supply no more than 5W via inductive charging. For a single industrial unit, the team has received a price quote for approximately \$2000 USD. Individuals and small R\&D teams that search for suitable devices through online retailers will find that these low-end transmitters are not modular and are limited to one specific purpose such as charging cell phones or key-fobs.\\ \indent
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

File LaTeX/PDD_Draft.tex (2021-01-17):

%		For public use only, fair use laws still apply
%		A tutorial template created by Chad Gibbons

%	I recommend for generic help the following website
%	http://www.emerson.emory.edu/services/latex/latex_toc.html
%	There are many good websites and forums for LaTeX
%
%	If you have a problem, google it. (ex. "How do I start my page numbers at a different number")
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

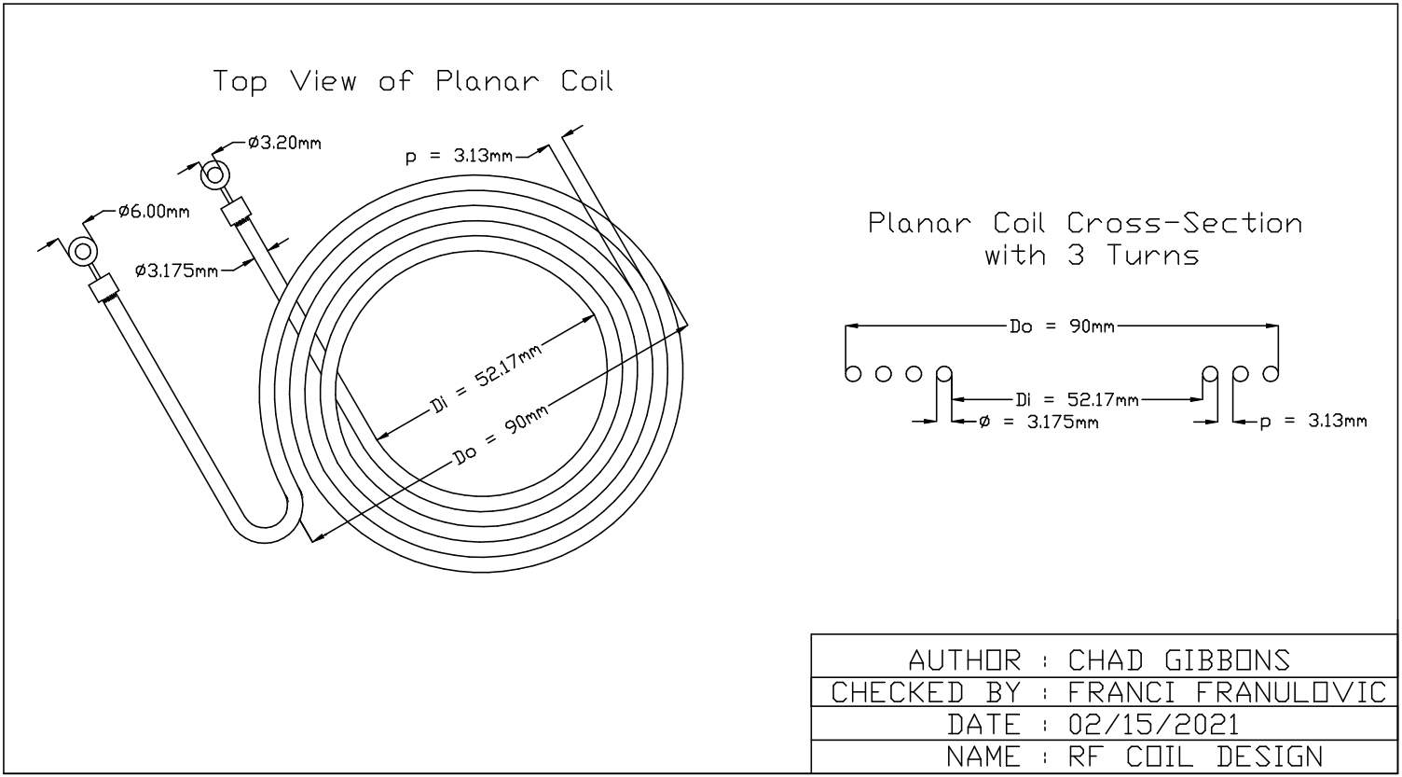
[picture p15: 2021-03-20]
docs/Hardware/Coil_CAD.PNG

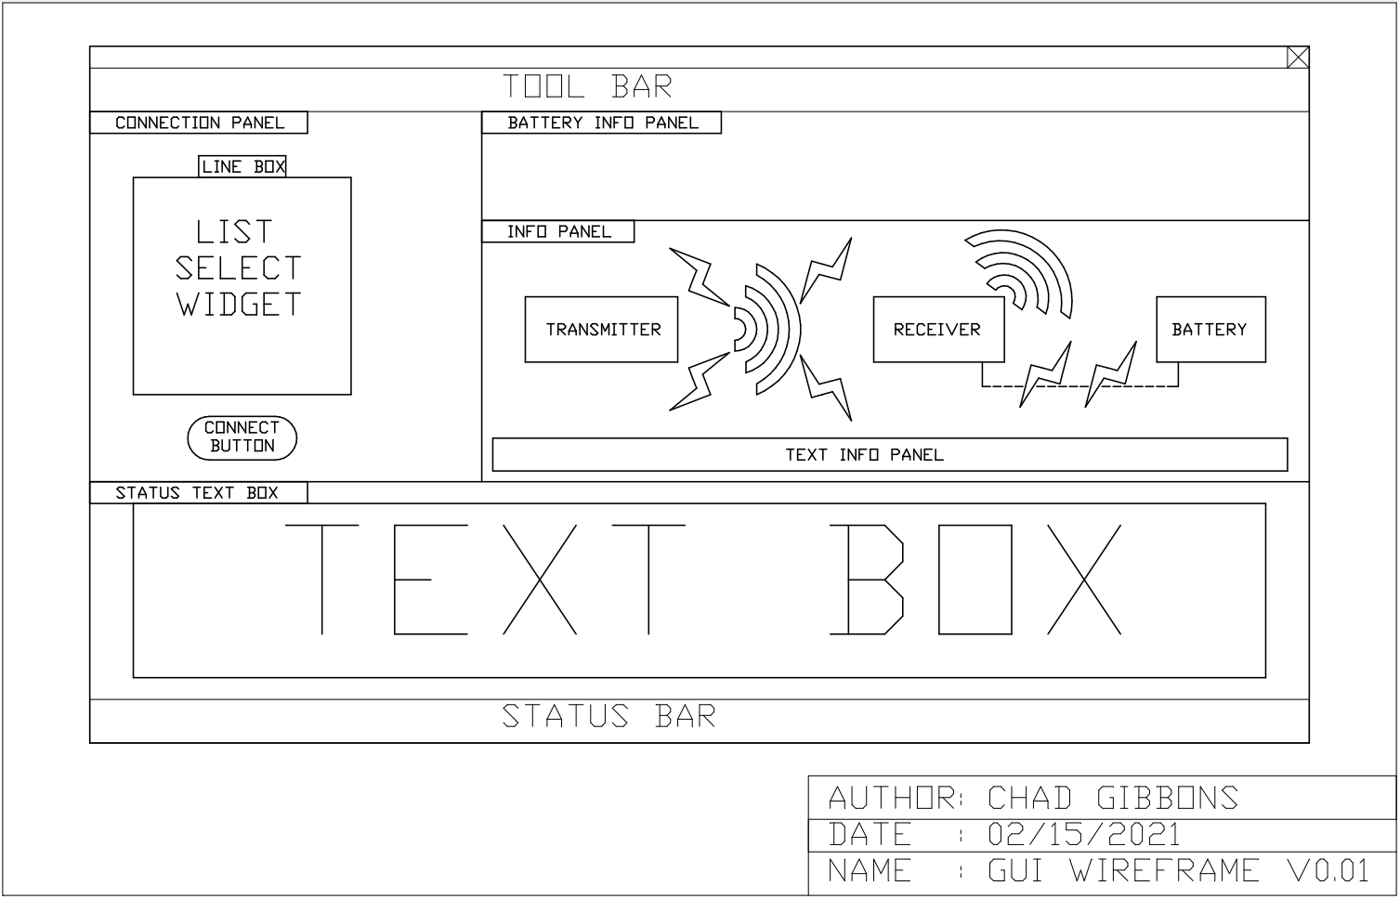
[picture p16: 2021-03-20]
docs/Hardware/GUI_Wireframe_V0_01.PNG

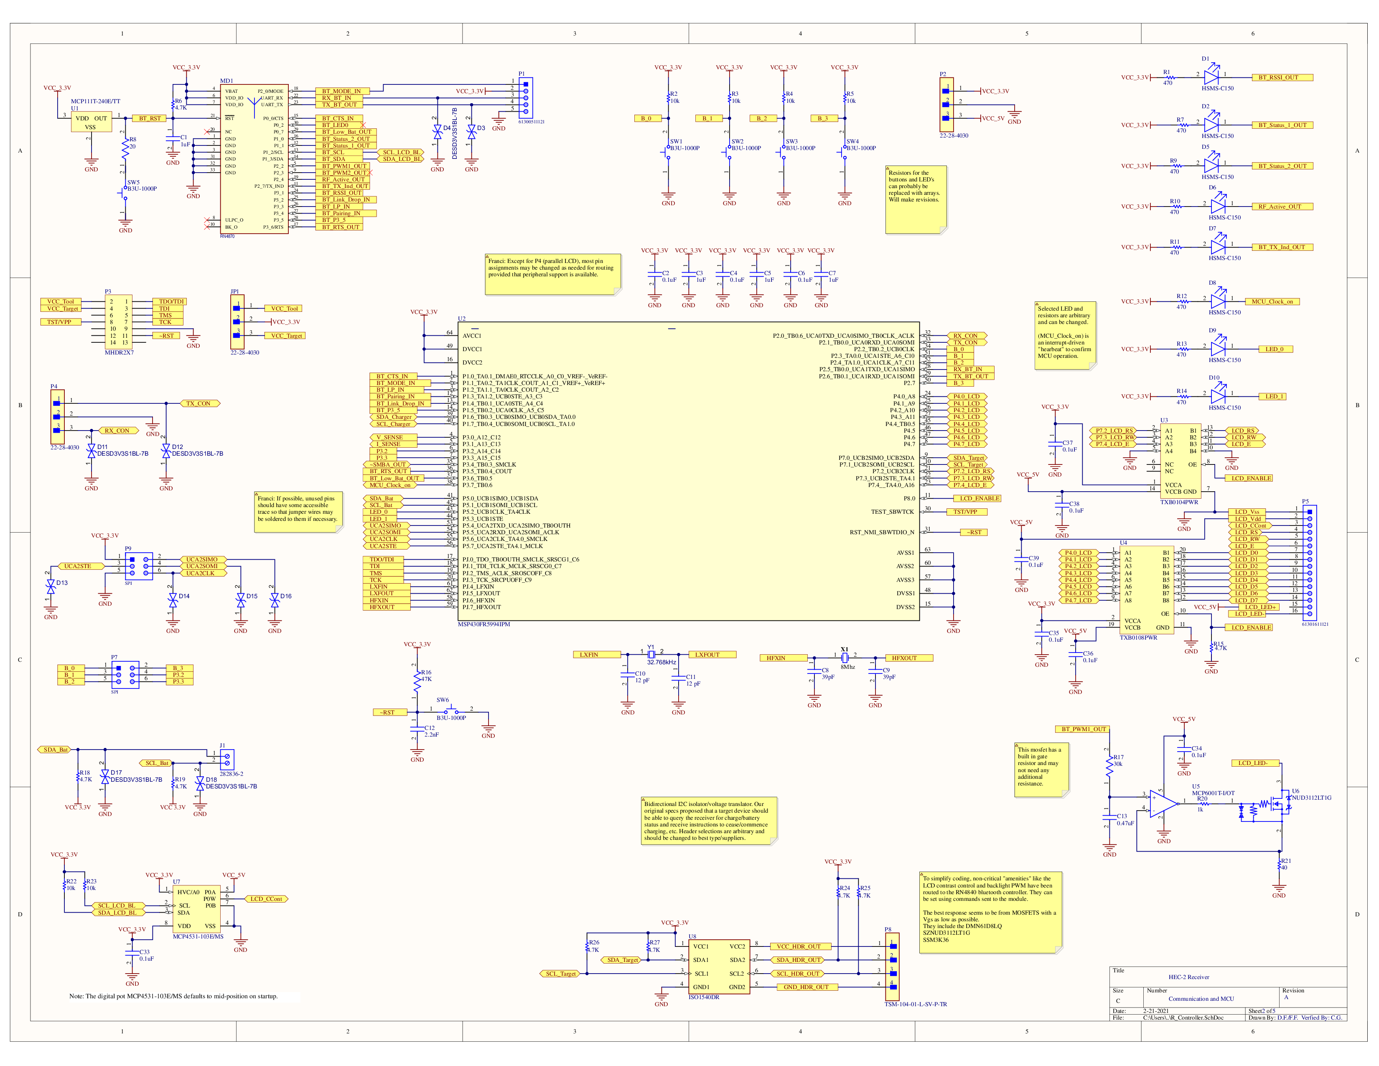
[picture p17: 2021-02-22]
Hardware/Receiver/receiver_png/HEC2 Receiver_002.png

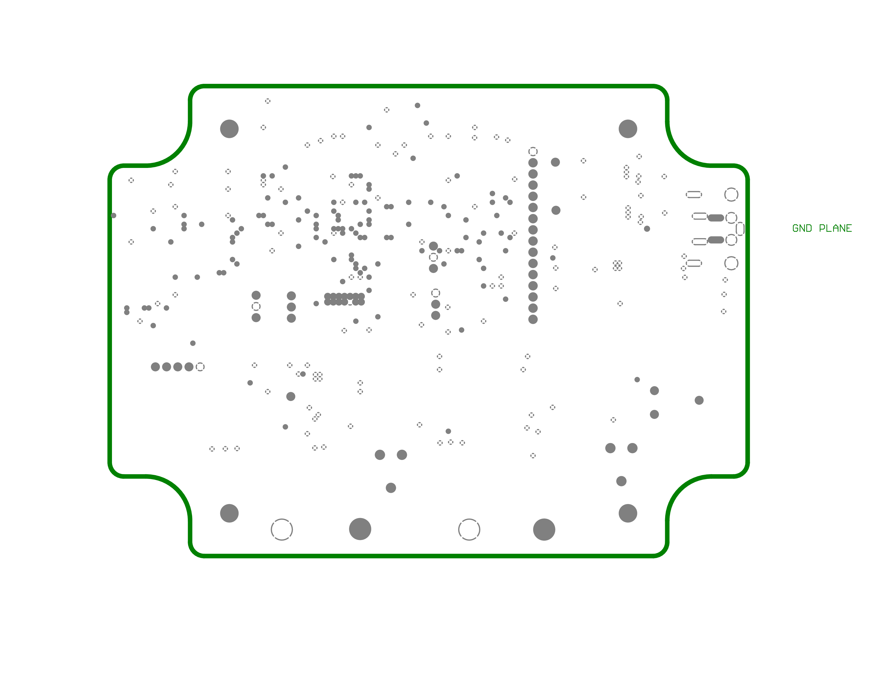
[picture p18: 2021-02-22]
Hardware/Transmitter/transmitter_png/HEC2 Transmitter_006.png

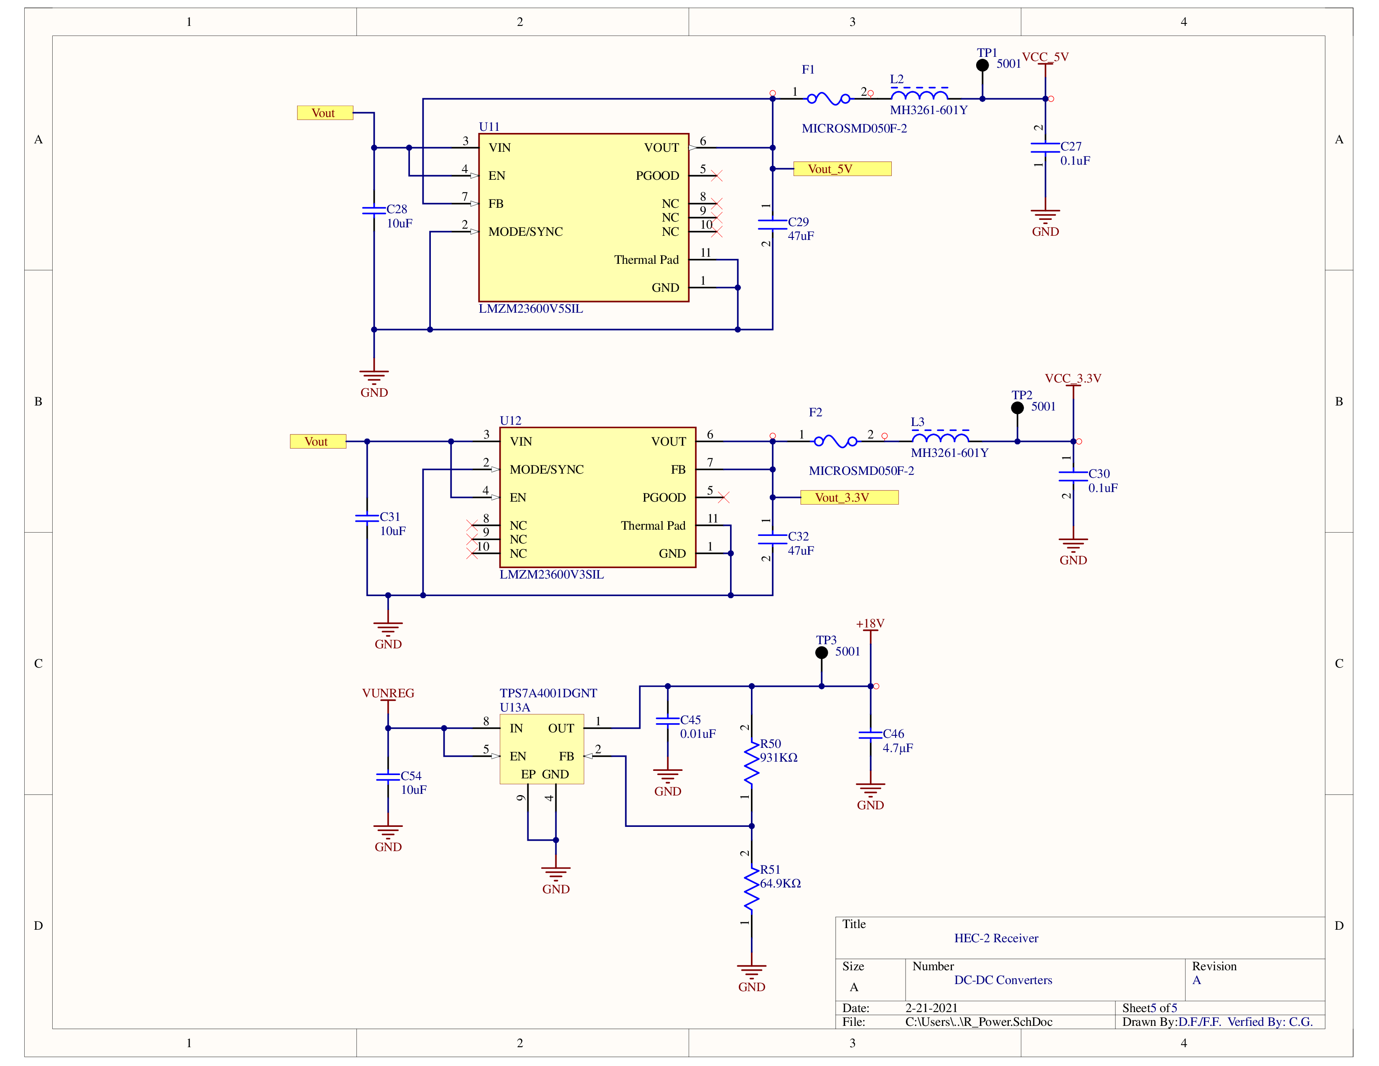
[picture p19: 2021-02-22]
Hardware/Receiver/receiver_png/HEC2 Receiver_005.png

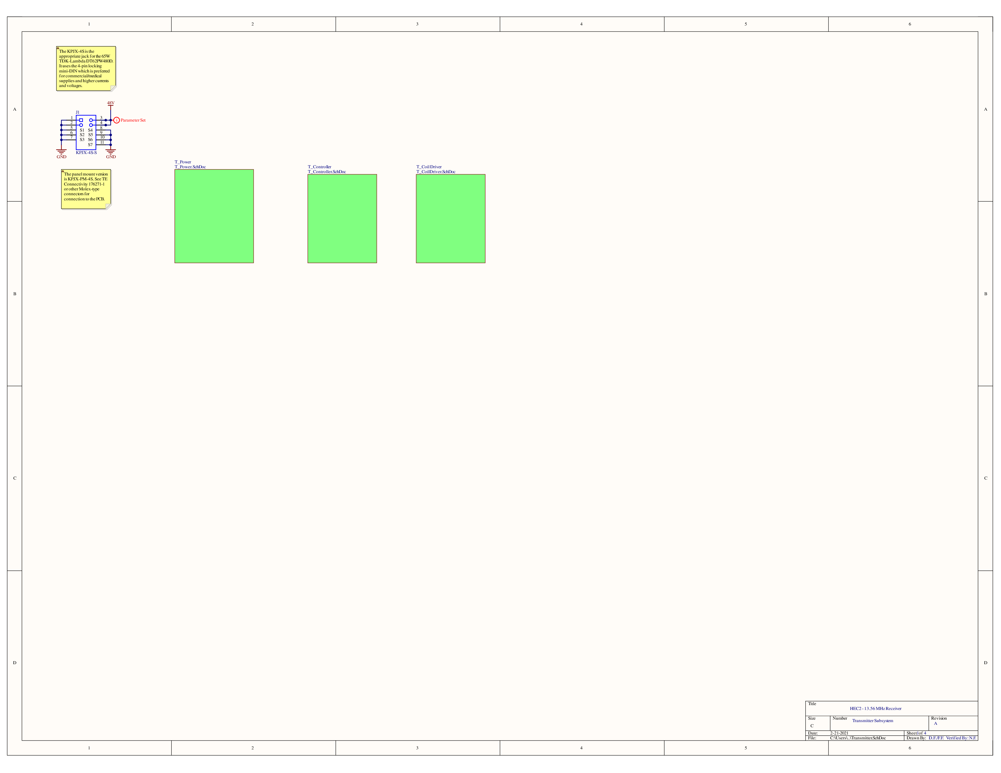
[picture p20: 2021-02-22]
Hardware/Transmitter/transmitter_png/HEC2 Transmitter_001.png

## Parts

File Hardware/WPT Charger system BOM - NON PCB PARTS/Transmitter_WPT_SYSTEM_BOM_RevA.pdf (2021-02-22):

ASSEMBLY NO: | | DATE: | 03-02-21
ASSEMBLY NAME: | Wireless Charger System | PREPARED BY: | Franci Franulovic
REVISION: | A | VERIFIED BY: | David Flory
SOLDER TYPE: | Lead-Free
ITEM | QTY | REFERENCE | DESCRIPTION | MFG | MFG P/N | VENDOR | VENDOR P/N | Datasheet URL | NOTES | Unit Price
1 | 1 | RECEIVER | Desktop AC Adapters 65W 48Vout 1.36A | TDK-Lambda | DT62PW480D | Mouser | 967-DT62PW480D | https://www.mouser.com/datasheet/2/400/dt62-80-d_e-1825770.pdf | | $53.00

2 1

RECEIVER /
TRANSMITTER

Electrical Enclosures IP68/NEMA 6P
Plastic Enclosure 5.88" x 4.38" x 2.19"
Opaque | Bud Industries | PU-16537 | Mouser | 967-DT62PW480D

https://www.mouser.com/catalog/specsheets/Bud_
PU%20Series_NEMA_6PIP68_PC_Enclosure.pdf | $25.30
3 | 1 | RECEIVER | Printed Circuit Board | JLC PCB | JLC PCB | Custom made | $6.68
4 | 1 | TRANSMITTER | Printed Circuit Board | JLC PCB | JLC PCB | Custom made | $6.69
5 | 0.1 | COIL RECEIVER

Hook-up Wire 14AWG 19/27 PTFE Spool
304.8 m | Alpha Wire | 5859 RD005 | Mouser | 602-5859-100-03

https://www.mouser.com/datasheet/2/14/AW_Pro
duct_Specification-1837536.pdf | $1.98
6 | 0.1 | COIL TRANSMITTER

Hook-up Wire 14AWG 19/27 PTFE
Spool 304.8 m | Alpha Wire | 5859 RD005 | Mouser | 602-5859-100-03

https://www.mouser.com/datasheet/2/14/AW_Pro
duct_Specification-1837536.pdf | $1.98

7 4

COIL RECEIVER /
TRANSMITTER | Terminals SOLIS DIN 0.5-1.0 | TE Connectivity | 165291 | Mouser | 571-165291

https://www.te.com/commerce/DocumentDelivery/DDEController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
rtCntxt=165291&DocFormat=pdf | $0.45
8 0.67 | | COIL RECEIVER | Super-Conductive 101 Copper TubesCopper Tubing 1/8" 3ft spool | Mcmaster-Carr | 8965K22 | Mcmaster-Carr | 8965K22 | https://www.mcmaster.com/tubing/od~1-8/material~copper/ | $6.94
9 0.67 | | COIL TRANSMITTER | Super-Conductive 101 Copper TubesCopper Tubing 1/8" 3ft spool | Mcmaster-Carr | 8965K22 | Mcmaster-Carr | 8965K22 | https://www.mcmaster.com/tubing/od~1-8/material~copper/ | $6.94
10 | 1 | Receiver | RRC-SMBus Cable | RRC | RRC-SMBus Cable | Mouser | 328-RRCSMBUSCABLE | https://www.mouser.com/datasheet/2/836/DS_SMBus_Battery_Cable_B-1360935.pdf | $22.35

11 2

COIL RECEIVER /
TRANSMITTER

Enclosures, Boxes, & Cases SENSOR
CUBE WHITE | New Age Enclosures | 789-S1A-404012 | Mouser | 789-S1A-404012

https://www.mouser.com/datasheet/2/290/NewAgeEnclosures_12092019_404012_cube_r1_0-
1673104.pdf | Coil enclosure | $5.70

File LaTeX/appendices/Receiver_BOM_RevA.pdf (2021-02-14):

ASSEMBLY NO: | | DATE: | 03-02-21
ASSEMBLY NAME: | HEC2 Receiver | PREPARED BY: | David Flory
REVISION: | A | VERIFIED BY: | Franci Franulovic
SOLDER TYPE: | Lead-Free
ITEM | QTY | REFERENCE | DESCRIPTION | MFG | MFG P/N | VENDOR | VENDOR P/N | Datasheet URL | NOTES | Unit Price
1 | 4 | C1, C3, C5, C7 | Multilayer Ceramic Capacitors MLCC - SMD/SMT Multilayer Ceramic Capacitors MLCC - SMD/SMT 1.0uF 10V X7R 10% | Yageo | CC0805KKX7R6BB105 | Mouser | 603-CC805KKX7R6BB105 | https://www.mouser.com/datasheet/2/447/UPY-GPHC_X7R_6.3V-to-50V_18-1154002.pdf | | $0.25
2 14 | | C2, C4, C6, C17, C21, C27, C30, C33, C34, C35, C36, C37, C38, C39 | Multilayer Ceramic Capacitors MLCC - SMD/SMT Multilayer Ceramic Capacitors MLCC - SMD/SMT 50V 0.1uF X7R 0805 10% | KEMET | C0805C104K5RACTU | Mouser | 80-C0805C104K5R | https://www.mouser.com/datasheet/2/212/KEM_C1002_X7R_S MD-1102033.pdf | | $0.13
3 | 2 | C8, C9 | Multilayer Ceramic Capacitors MLCC - SMD/SMT Multilayer Ceramic Capacitors MLCC - SMD/SMT 50V 39pF C0G 0805 5% | KEMET | C0805C390J5GACTU | Mouser | 80-C0805C390J5G | https://www.mouser.com/datasheet/2/212/KEM_C1003_C0G_S MD-1101588.pdf | | $0.24
4 | 2 | C10, C11 | Multilayer Ceramic Capacitors MLCC - SMD/SMT Multilayer Ceramic Capacitors MLCC - SMD/SMT 50V 12pF C0G 0805 5% | KEMET | C0805C120J5GACTU | Mouser | 80-C0805C120J5G | https://www.mouser.com/datasheet/2/212/KEM_C1003_C0G_S MD-1101588.pdf | | $0.11
5 | 1 | C12 | Multilayer Ceramic Capacitors MLCC - SMD/SMT Multilayer Ceramic Capacitors MLCC - SMD/SMT 50V 2200pF X8R 0805 5% | KEMET | C0805C222J5HACTU | Mouser | 80-C0805C222J5H | https://www.mouser.com/datasheet/2/212/KEM_C1007_X8R_ULTRA_150C_SMD-1102703.pdf | | $0.69
6 | 1 | C13 | Multilayer Ceramic Capacitors MLCC - SMD/SMT Multilayer Ceramic Capacitors MLCC - SMD/SMT 470nF 16V X7R 10% | Yageo | CC0805KKX7R7BB474 | Mouser | 603-CC805KKX7R7BB474 | https://www.mouser.com/datasheet/2/447/UPY-GPHC_X7R_6.3V-to-50V_18-1154002.pdf | | $0.23
7 | 1 | C14 | Multilayer Ceramic Capacitors MLCC - SMD/SMT Multilayer Ceramic Capacitors MLCC - SMD/SMT 1.0uF 10V X7R 10% | Yageo | CC0805KKX7R6BB105 | Mouser | 603-CC805KKX7R6BB105 | https://www.mouser.com/datasheet/2/447/UPY-GPHC_X7R_6.3V-to-50V_18-1154002.pdf | | $0.25
8 | 2 | C15, C18 | Multilayer Ceramic Capacitors MLCC - SMD/SMT Multilayer Ceramic Capacitors MLCC - SMD/SMT 10volts 10uF X5R 10% | KEMET | C0805C106K8PACTU | Mouser | 80-C0805C106K8P | https://www.mouser.com/datasheet/2/212/KEM_C1006_X5R_S MD-1103249.pdf | | $0.14
9 | 1 | C16 | Multilayer Ceramic Capacitors MLCC - SMD/SMT Multilayer Ceramic Capacitors MLCC - SMD/SMT 50V 0.1uF X7R 0805 10% | KEMET | C0805C104K5RACTU | Mouser | 80-C0805C104K5R | https://www.mouser.com/datasheet/2/212/KEM_C1002_X7R_S MD-1102033.pdf | | $0.24
10 | 1 | C19 | Multilayer Ceramic Capacitors MLCC - SMD/SMT Multilayer Ceramic Capacitors MLCC - SMD/SMT 50V 0.022uF C0G 0805 5% | KEMET | C0805C223J5GACTU | Mouser | 80-C0805C223J5G | https://www.mouser.com/datasheet/2/212/KEM_C1003_C0G_S MD-1101588.pdf | | $0.76
11 | 1 | C20 | Tantalum Capacitors - Solid SMD Tantalum Capacitors - Solid SMD 50V 10uf 2917 10% ESR=800mOhms | KEMET | T491D106K050AT | Mouser | 80-T491D106K050 | https://www.mouser.com/datasheet/2/212/1/KEM_T2005_T49 1-1093550.pdf | | $1.83
12 | 1 | C25 | Multilayer Ceramic Capacitors MLCC - SMD/SMT Multilayer Ceramic Capacitors MLCC - SMD/SMT 22pF 1KVolts 5% | Murata | GRM31A7U3A220JW31D | Mouser | 81-GRM31A7U3A220JW1D | https://www.mouser.com/datasheet/2/281/1/GRM31A7U3A220JW31_01-1987629.pdf | | $0.43
13 | 1 | C26 | Multilayer Ceramic Capacitors MLCC - SMD/SMT Multilayer Ceramic Capacitors MLCC - SMD/SMT 100pF 1KV C0G 5% | Vishay | VJ1812A101JXGAT | Mouser | 77-VJ1812A101JXGAT | https://www.mouser.com/datasheet/2/427/vjcommercialseries-1764145.pdf | | $0.76
14 | 4 | C28, C31, C50, C51 | Multilayer Ceramic Capacitors MLCC - SMD/SMT Multilayer Ceramic Capacitors MLCC - SMD/SMT 1206 50V 10uF X5R 10% T: 1.6mm | TDK | C3216X5R1H106K160AB | Mouser | 810-C3216X5R1H106K | https://product.tdk.com/info/en/catalog/datasheets/mlcc_commercial_general_en.pdf?ref_disty=mouser | | $0.85
15 | 2 | C29, C32 | Multilayer Ceramic Capacitors MLCC - SMD/SMT Multilayer Ceramic Capacitors MLCC - SMD/SMT 1206 25VDC 47uF 20% X5R 1.6mm | TDK | C3216X5R1E476M160AC | Mouser | 810-C3216X5R1E476M | https://product.tdk.com/info/en/catalog/datasheets/mlcc_commercial_general_en.pdf?ref_disty=mouser | | $1.05
16 | 1 | C40 | Multilayer Ceramic Capacitors MLCC - SMD/SMT Multilayer Ceramic Capacitors MLCC - SMD/SMT 100Vdc 10uF 10% 1210/2502 | Murata | GRM32EC72A106KE05L | Mouser | 81-GRM32EC72A106KE05 | https://www.mouser.com/datasheet/2/281/1/GRM32EC72A106KE05_01A-1988109.pdf | | $1.38
17 | 1 | C42 | Multilayer Ceramic Capacitors MLCC - SMD/SMT Multilayer Ceramic Capacitors MLCC - SMD/SMT 0805 10pF 1KV C0G 5% | Vishay | VJ0805A100JXGAT5Z | Mouser | 77-VJ0805A100JXGAT5Z | https://www.mouser.com/datasheet/2/427/vjhvarcguard-1763127.pdf | | $0.68
18 | 1 | C44 | Trimmer / Variable Capacitors Trimmer / Variable Capacitors TRIMMER CAPACITOR | Vishay | BFC280832659 | Mouser | 594-2222-808-32659 | https://www.vishay.com/doc?28528 | | $7.21
19 | 1 | C46 | Multilayer Ceramic Capacitors MLCC - SMD/SMT Multilayer Ceramic Capacitors MLCC - SMD/SMT 50V 4.7uF X7R 1210 10% | KEMET | C1210X475K5RACTU | Mouser | 80-C1210X475K5R | https://www.mouser.com/datasheet/2/212/1/KEM_C1013_X7R_FT_CAP_SMD-1103280.pdf | | $1.81
20 | 1 | C47 | Multilayer Ceramic Capacitors MLCC - SMD/SMT Multilayer Ceramic Capacitors MLCC - SMD/SMT 16V .01uF C0G 0805 5% | AVX | 0805YA103JAT2A | Mouser | 581-0805YA103J | https://www.mouser.com/datasheet/2/40/C0GNP0_Dielectric-951274.pdf | | $0.96

21 | 2 | C48, C49
| | Multilayer Ceramic Capacitors MLCC - SMD/SMT Multilayer Ceramic Capacitors MLCC - SMD/SMT 2220 1uF 250volts X7R 10% | Murata | GRM55DR72E105KW01L | Mouser | 81-GRM55RR72E105K | https://www.mouser.com/datasheet/2/281/1/GRM55DR72E105KW01_01-1988382.pdf | | $1.48
22 | 1 | C52 | Multilayer Ceramic Capacitors MLCC - SMD/SMT Multilayer Ceramic Capacitors MLCC - SMD/SMT 16V 1uF X7R 0805 10% | KEMET | C0805C105K4RACTU | Mouser | 80-C0805C105K4R | https://www.mouser.com/datasheet/2/212/KEM_C1002_X7R_S MD-1102033.pdf | | $0.13
23 | 1 | C54 | Multilayer Ceramic Capacitors MLCC - SMD/SMT Multilayer Ceramic Capacitors MLCC - SMD/SMT 100V 10uF X7R 2220 20% Tol HIGH CV | AVX | 22201C106MAT2A | Mouser | 581-22201C106MAT2A | https://www.mouser.com/datasheet/2/40/X7RDielectric-777024.pdf | | $1.83
24 | 8 | D1, D2, D5, D6, D7, D8, D9, D10 | Standard LEDs - SMD Standard LEDs - SMD Red Diffused 626nm 10mcd | Broadcom Limited | HSMS-C150 | Mouser | 630-HSMS-C150 | https://www.mouser.com/datasheet/2/678/av02-0551en-ds-hsmx-cxxx-05mar2012-1827675.pdf | | $0.41
25 | 5 | D3, D11, D12, D17, D18 | ESD Suppressors / TVS Diodes ESD Suppressors / TVS Diodes Low Cap Bi TVS 10pF 3.3V 3.8Vbr 25kV | Diodes Incorporated | DESD3V3S1BL-7B | Mouser | 621-DESD3V3S1BL-7B | https://www.mouser.com/datasheet/2/115/DESD3V3S1BL-321080.pdf | | $0.29
26 | 5 | D4, D13, D14, D15, D16 | ESD Suppressors / TVS Diodes ESD Suppressors / TVS Diodes Low Cap Bi TVS 10pF 3.3V 3.8Vbr 25kV | Diodes Incorporated | DESD3V3S1BL-7B | Mouser | 621-DESD3V3S1BL-7B | https://www.mouser.com/datasheet/2/115/DESD3V3S1BL-321080.pdf | | $0.29
27 | 2 | D19, D20 | Schottky Diodes & Rectifiers Schottky Diodes & Rectifiers 1.0 Amp 40 Volt | STMicroelectronics | STPS140A | Mouser | 511-STPS140A | https://www.mouser.com/datasheet/2/389/stps140-1851573.pdf | | $0.44
28 8 | | D21, D22, D23, D24, D25, D26, D27, D28 | Schottky Diodes & Rectifiers Schottky Diodes & Rectifiers SIC DIODES | Infineon | IDH04SG60CXKSA2 | Mouser | 726-IDH04SG60CXKSA2 | https://www.infineon.com/dgdl/Infineon-ApplicationNote_PFCCCMBoostConverterDesignGuide-AN-v02_00-EN.pdf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 | | $2.64
29 | 2 | F1, F2 | Resettable Fuses - PPTC Resettable Fuses - PPTC .5A 13.2V 40A Imax | Littelfuse | MICROSMD050F-2 | Mouser | 650-MICROSMD050F-2 | https://www.mouser.com/datasheet/2/240/Littelfuse_PTC_MICROSMD_Catalog_Datasheet.pdf-1021745.pdf | | $0.47
30 | 2 | J1, J3 | Fixed Terminal Blocks Fixed Terminal Blocks 5.0MM PCB MOUNT 2P | TE Connectivity | 282836-2 | Mouser | 571-2828362 | http://www.te.com/commerce/DocumentDelivery/DDEController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 | | $0.80
31 | 2 | J2, J4 | | | | Mouser
32 | 3 | JP1, P2, P4 | Headers & Wire Housings Headers & Wire Housings 3P VERT HEADER Sn | Molex | 22-28-4030 | Mouser | 538-22-28-4030 | https://www.mouser.com/datasheet/2/276/0022284030_PCB_HEADERS-228162.pdf | | $0.16
33 | 2 | JP4, JP5 | Headers & Wire Housings Headers & Wire Housings WR-PHD 2.54mm SMT 6P Hdr Dual Strt | Wurth Elektronik | 61000621121 | Mouser | 710-61000621121 | https://www.mouser.com/datasheet/2/445/61000621121-1717892.pdf | | $0.93
34 | 1 | L1 | Fixed Inductors Fixed Inductors 6.8uH Shld 20% 9A 20.8mOhms AECQ2 | Coilcraft | XAL6060-682MEB | Mouser | 994-XAL6060-682MEB | https://www.mouser.com/datasheet/2/597/xal60xx-270658.pdf | | $2.58
35 | 2 | L2, L3 | Ferrite Beads Ferrite Beads 600 ohms 25% HIGH CURRENT | Bourns | MH3261-601Y | Mouser | 652-MH3261-601Y | https://www.mouser.com/datasheet/2/54/mh-777565.pdf | | $0.10
36 | 1 | L4 | Fixed Inductors Fixed Inductors WE-SD Rod Core 10uH 5A 15.1mOhm | Wurth Elektronik | 744711005 | Mouser | 710-744711005 | https://www.mouser.com/datasheet/2/445/744711005-1722097.pdf | | $1.83
37 | 1 | L5 | Fixed Inductors Fixed Inductors WE-CAIR Air Coil 100nH 1.7A 150MHz | Wurth Elektronik | 744912210 | Mouser | 710-744912210 | https://www.mouser.com/datasheet/2/445/744912210-1723335.pdf | | $1.16
38 | 1 | L8 | Fixed Inductors Fixed Inductors 220uH Shld 10% 2.1A 245mOhms AECQ2 | Coilcraft | MSS1210-224KEB | Mouser | 994-MSS1210-224KEB | https://www.mouser.com/datasheet/2/597/mss1210-270677.pdf | | $2.26
39 | 1 | MD1 | Bluetooth Modules (802.15.1) Bluetooth Modules (802.15.1) Bluetooth Low Energy BLE Module, Shielded, Antenna, ASCII Interface, 12x22mm | Microchip | RN4870-I/RM140 | Mouser | 579-RN4870-I/RM140 | https://www.mouser.com/datasheet/2/268/RN4870-71-Bluetooth-Low-Energy-Module-Data-Sheet-D-1658564.pdf | | $7.38
40 | 1 | P1 | Headers & Wire Housings Headers & Wire Housings WR-PHD 2.54mm Hdr 5P Single Str Gold | Wurth Elektronik | 61300511121 | Mouser | 710-61300511121 | https://www.mouser.com/datasheet/2/445/61300511121-1717845.pdf | | $0.25
41 | 1 | P3 | Headers & Wire Housings Headers & Wire Housings WR-PHD1.27mm Hdr 14P Dual Str Gold | Wurth Elektronik | 62201421121 | Mouser | 710-62201421121 | https://www.mouser.com/datasheet/2/445/62201421121-1718302.pdf | | $1.48
42 | 1 | P5 | Headers & Wire Housings Headers & Wire Housings WR-PHD 2.54mm Hdr 16P Single Str Gold | Wurth Elektronik | 61301611121 | Mouser | 710-61301611121 | https://www.mouser.com/datasheet/2/445/61301611121-1717958.pdf | | $0.90
43 | 1 | P6 | Headers & Wire Housings Headers & Wire Housings 02 SIL VERTICAL PIN HEADER TIN | Harwin | M20-9990246 | Mouser | 855-M20-9990246 | https://www.mouser.com/datasheet/2/181/M20-999-1218971.pdf | | $0.11
44 | 2 | P7, P9 | Headers & Wire Housings Headers & Wire Housings WR-PHD 2.54mm SMT 6P Hdr Dual Strt | Wurth Elektronik | 61000621121 | Mouser | 710-61000621121 | https://www.mouser.com/datasheet/2/445/61000621121-1717892.pdf | | $0.93
45 | 1 | P8 | Headers & Wire Housings Headers & Wire Housings .100" Surface Mount Terminal Strip | Samtec | TSM-104-01-L-SV-P-TR | Mouser | 200-TSM10401LSVPTR | https://www.mouser.com/datasheet/2/527/tsm-1344849.pdf | | $1.27
46 | 2 | Q1, Q2 | MOSFET MOSFET PT8 40V/20V LL NCh PowerTrench MOSFET | ON Semiconductor | FDMC8327L | Mouser | 512-FDMC8327L | https://www.mouser.com/datasheet/2/308/FDMC8327L-D-1807402.pdf | | $0.86
47 | 8 | R1, R7, R9, R10, R11, R12, R13, R14 | Thick Film Resistors - SMD Thick Film Resistors -SMD 470 OHM 1% | Yageo | RC0805FR-07470RL | Mouser | 603-RC0805FR-07470RL | https://www.mouser.com/datasheet/2/447/PYu_RC_Group_51_RoHS_L_10-1664068.pdf | | $0.13

48 | 6 | R2, R3, R4, R5, R22, R23
| | Thick Film Resistors - SMD Thick Film Resistors -SMD 10K OHM 1% | Yageo | RC0805FR-0710KL | Mouser | 603-RC0805FR-0710KL | https://www.mouser.com/datasheet/2/447/PYu_RC_Group_51_RoHS_L_10-1664068.pdf | | $0.13
49 8 | | R6, R15, R18, R19, R24, R25, R26, R27 | Thick Film Resistors - SMD Thick Film Resistors -SMD 1/8watt 4.7Kohms 5% 200ppm | Vishay | CRCW08054K70JNTA | Mouser | 71-CRCW0805J-4.7K | https://www.mouser.com/datasheet/2/427/dcrcw-1762150.pdf | | $0.12
50 | 1 | R8 | Thick Film Resistors - SMD Thick Film Resistors -SMD 1/8watt 20ohms 1% 100ppm | Vishay | CRCW080520R0FKEA | Mouser | 71-CRCW0805-20-E3 | https://www.mouser.com/datasheet/2/427/dcrcwe3-1762152.pdf | | $0.10
51 | 1 | R17 | Thick Film Resistors - SMD Thick Film Resistors -SMD 1/8watt 30Kohms 1% 100ppm | Vishay | CRCW080530K0FKEA | Mouser | 71-CRCW0805-30K-E3 | https://www.mouser.com/datasheet/2/427/dcrcwe3-1762152.pdf | | $0.10
52 | 1 | R20, R57 | Thick Film Resistors - SMD Thick Film Resistors -SMD 1K OHM 1% | Yageo | RC0805FR-071KL | Mouser | 603-RC0805FR-071KL | https://www.mouser.com/datasheet/2/447/PYu_RC_Group_51_RoHS_L_10-1664068.pdf | | $0.13
53 | 1 | R21 | Thick Film Resistors - SMD Thick Film Resistors -SMD 1/8watt 40.2ohms 1% 100ppm | Vishay | CRCW080540R2FKTA | Mouser | 71-CRCW0805-40.2 | https://www.mouser.com/datasheet/2/427/dcrcw-1762150.pdf | | $0.16
54 | 1 | R28 | Thick Film Resistors - SMD Thick Film Resistors -SMD 1/8watt 63.4Kohms 1% 100ppm | Vishay | CRCW080563K4FKEA | Mouser | 71-CRCW0805-63.4K-E3 | https://www.mouser.com/datasheet/2/427/dcrcwe3-1762152.pdf | | $0.10
55 | 3 | R29, R30, R31 | Thick Film Resistors - SMD Thick Film Resistors -SMD 1/8watt 4.7Kohms 1% | Vishay | CRCW08054K70FKEA | Mouser | 71-CRCW0805-4.7K-E3 | https://www.mouser.com/datasheet/2/427/dcrcwe3-1762152.pdf | | $0.10
56 | 2 | R32, R34 | Thick Film Resistors - SMD Thick Film Resistors -SMD 10K OHM 1% | Yageo | RC0805FR-0710KL | Mouser | 603-RC0805FR-0710KL | https://www.mouser.com/datasheet/2/447/PYu_RC_Group_51_RoHS_L_10-1664068.pdf | | $0.13
57 | 2 | R33, R36 | Thick Film Resistors - SMD Thick Film Resistors -SMD 1/8watt 10ohms 5% 200ppm | Vishay | CRCW080510R0JNEA | Mouser | 71-CRCW080510R0JNEA | https://www.mouser.com/datasheet/2/427/dcrcwe3-1762152.pdf | | $0.10
58 | 2 | R35, R37 | Thick Film Resistors - SMD Thick Film Resistors -SMD 100K OHM 1% | Yageo | RC0805FR-07100KL | Mouser | 603-RC0805FR-07100KL | https://www.mouser.com/datasheet/2/447/PYu_RC_Group_51_RoHS_L_10-1664068.pdf | | $0.13
59 | 1 | R38 | Current Sense Resistors - SMD Current Sense Resistors - SMD 1/4watt .02ohms 1% | Vishay | WSL1206R0200FEA | Mouser | 71-WSL1206R0200FEA | http://www.vishay.com/doc?30373 | | $0.89
60 | 1 | R39 | Thick Film Resistors - SMD Thick Film Resistors -SMD 1/4watt 158Kohms 1% | Vishay | CRCW1206158KFKEA | Mouser | 71-CRCW1206-158K-E3 | https://www.mouser.com/datasheet/2/427/dcrcwe3-1762152.pdf | | $0.10
61 | 1 | R40 | Thin Film Resistors - SMD Thin Film Resistors -SMD 0.1W 10Kohms 0.1% 1206 25ppm Auto | Vishay | MCA12060D1002BP500 | Mouser | 594-MCA12060D1002BP5 | https://www.mouser.com/datasheet/2/427/mcx0x0xpre-1762843.pdf | | $0.51
62 | 3 | R41, R42, R46 | Thick Film Resistors - SMD Thick Film Resistors -SMD 0ohm Jumper | Bourns | CR1206-J/-000ELF | Mouser | 652-CR1206-J/-000ELF | https://www.mouser.com/datasheet/2/54/crxxxxx-1858361.pdf | | $0.10
63 | 6 | R43, R44, R45, R47, R48, R49 | Thick Film Resistors - SMD Thick Film Resistors -SMD 0ohm Jumper | Bourns | CR1206-J/-000ELF | Mouser | 652-CR1206-J/-000ELF | https://www.mouser.com/datasheet/2/54/crxxxxx-1858361.pdf | | $0.10
64 | 1 | R50 | Thin Film Resistors - SMD Thin Film Resistors -SMD 1/8W 931K ohm .1% 25ppm | Yageo | RT0805BRD07931KL | Mouser | 603-RT0805BRD07931KL | https://www.mouser.com/datasheet/2/447/PYu_RT_1_to_0_01_RoHS_L_11-1669912.pdf | | $0.43
65 | 1 | R51 | Thin Film Resistors - SMD Thin Film Resistors -SMD 1/8W 64.9K ohm .1% 25ppm | Yageo | RT0805BRD0764K9L | Mouser | 603-RT0805BRD0764K9L | https://www.mouser.com/datasheet/2/447/PYu_RT_1_to_0_01_RoHS_L_11-1669912.pdf | | $0.43
66 | 1 | R52 | Thick Film Resistors - SMD Thick Film Resistors -SMD 1/8watt 1.1Mohms 1% | Vishay | CRCW08051M10FKEA | Mouser | 71-CRCW08051M10FKEA | https://www.mouser.com/datasheet/2/427/dcrcwe3-1762152.pdf | | $0.10
67 | 1 | R53 | Thick Film Resistors - SMD Thick Film Resistors -SMD 1/8watt 75Kohms 1% 100ppm | Vishay | CRCW080575K0FKEA | Mouser | 71-CRCW0805-75K-E3 | https://www.mouser.com/datasheet/2/427/dcrcwe3-1762152.pdf | | $0.10
68 | 1 | R54 | Thick Film Resistors - SMD Thick Film Resistors -SMD 1/8watt 28Kohms 1% 100ppm | Vishay | CRCW080528K0FKEA | Mouser | 71-CRCW0805-28K-E3 | https://www.mouser.com/datasheet/2/427/dcrcwe3-1762152.pdf | | $0.10
69 | 1 | R55 | Thick Film Resistors - SMD Thick Film Resistors -SMD 0805 2.94Kohms 1% AEC-Q200 | Panasonic | ERJ-6ENF2941V | Mouser | 667-ERJ-6ENF2941V | https://www.mouser.com/datasheet/2/315/AOA0000C304-1149620.pdf | | $0.10
70 | 1 | R56 | Thin Film Resistors - SMD Thin Film Resistors -SMD 1/10W 2Kohm 0.5% 25ppm | Susumu | RR1220P-202-D | Mouser | 754-RR1220P-202D | https://www.mouser.com/datasheet/2/392/susumu_RR_Data_Sheet-1206438.pdf | | $0.10
71 | 2 | RS1, RS2 | Current Sense Resistors - SMD Current Sense Resistors - SMD 1206 0.010ohm 1% Curr Sense AEC-Q200 | Panasonic | ERJ-8BWFR010V | Mouser | 667-ERJ-8BWFR010V | https://www.mouser.com/datasheet/2/315/AOA0000C313-1141758.pdf | | $0.74
72 | 6 | SW1, SW2, SW3, SW4, SW5, SW6 | Tactile Switches Tactile Switches Top Actuated w/o boss w/o ground | Omron | B3U-1000P | Mouser | 653-B3U-1000P | https://www.mouser.com/datasheet/2/307/en-b3u-3615.pdf | | $0.92
73 | 3 | TP1, TP2, TP3 | Circuit Board Hardware - PCB Circuit Board Hardware - PCB TEST POINT BLACK | Keystone Electronics | 5001 | Mouser | 534-5001 | https://www.mouser.com/datasheet/2/215/000-5004-741181.pdf | | $0.35
74 | 1 | U1 | Supervisory Circuits Supervisory Circuits Open Drain | Microchip | MCP111T-240E/TT | Mouser | 579-MCP111T-240E/TT | https://www.mouser.com/datasheet/2/268/21889b-64653.pdf | | $0.47
75 | 1 | U2 | 16-bit Microcontrollers - MCU 16-bit Microcontrollers - MCU | Texas Instruments | MSP430FR5994IPM | Mouser | 595-MSP430FR5994IPM | https://www.ti.com/lit/pdf/slaa722 | | $8.11
76 | 1 | U3 | Translation - Voltage Levels Translation - Voltage Levels 4-Bit Bi-directional V-Level Translator | Texas Instruments | TXB0104PWR | Mouser | 595-TXB0104PWR | https://www.ti.com/lit/pdf/scea064 | | $0.93
77 | 1 | U4 | Translation - Voltage Levels Translation - Voltage Levels 8-Bit Bi-directional V-Level Translator | Texas Instruments | TXB0108PWR | Mouser | 595-TXB0108PWR | http://www.ti.com/general/docs/suppproductinfo.tsp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 8 $1.29

78 | 1 | U5 | Operational Amplifiers - Op Amps Operational Amplifiers - Op Amps Single 1.8V 1MHz | Microchip | MCP6001T-I/OT | Mouser | 579-MCP6001T-I/OT | https://www.mouser.com/datasheet/2/268/21733j-740845.pdf | $0.24
79 | 1 | U6 | Gate Drivers Gate Drivers 12V Industrial Relay Inductive Load | ON Semiconductor | NUD3112LT1G | Mouser | 863-NUD3112LT1G | http://www.onsemi.com/pub/Collateral/AND8116-D.PDF | $0.44
80 | 1 | U7 | Digital Potentiometer ICs Digital Potentiometer ICs Sngl 7B V I2C POT | Microchip | MCP4531-103E/MS | Mouser | 579-MCP4531-103E/MS | https://www.mouser.com/datasheet/2/268/DS-22096a-36447.pdf | $0.70
81 | 1 | U8 | Digital Isolators Digital Isolators Low-Power,Bidirec I2C Iso | Texas Instruments | ISO1540DR | Mouser | 595-ISO1540DR | https://www.ti.com/lit/pdf/slyt403a | $4.51
82 | 1 | U9 | Battery Management Battery Management 35V/3.2A Multi-Cell Lithium-Ion Step-Down Battery Charger with PowerPath and I2C Telemetry | Analog Devices Inc. | LTC4162EUFD-SAD#PBF | Mouser | 584-4162EUFDSADPB | https://www.mouser.com/datasheet/2/609/LTC4162_S-1398197.pdf | $7.33
83 | 1 | U10 | Current & Power Monitors & Regulators Current & Power Monitors & Regulators Vltg Out Hi-Sd Msmnt Current Shunt Mntr | Texas Instruments | INA194AIDBVT | Mouser | 595-INA194AIDBVT | https://www.ti.com/lit/pdf/sloa228 | $2.89
84 | 1 | U11 | Non-Isolated DC/DC Converters Non-Isolated DC/DC Converters | Texas Instruments | LMZM23601V5SILT | Mouser | 595-LMZM23601V5SILT | https://www.ti.com/lit/pdf/snva834 | $6.17
85 | 1 | U12 | Non-Isolated DC/DC Converters Non-Isolated DC/DC Converters | Texas Instruments | LMZM23601V3SILT | Mouser | 595-LMZM23601V3SILT | https://www.ti.com/lit/pdf/slpa015 | $6.17
86 | 1 | U13 | LDO Voltage Regulators LDO Voltage Regulators 50mA,100Vin,Sgl Out put LDO Linear Reg | Texas Instruments | TPS7A4001DGNT | Mouser | 595-TPS7A4001DGNT | http://www.ti.com/general/docs/suppproductinfo.tsp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 001 $2.81
87 | 1 | U14 | Switching Voltage Regulators Switching Voltage Regulators | Texas Instruments | LM5161PWPR | Mouser | 595-LM5161PWPR | https://www.ti.com/lit/pdf/snaa137a | $4.21
88 | 3 | C22, C23, C24 | Film Capacitors Film Capacitors 100V .47uF 10% 1E=4.5x9.5x7.2 PCM 5 | WIMA | MKS2D034701E00KSSD | Mouser | 505-MKS2.47/100/10 | https://www.mouser.com/datasheet/2/440/e_WIMA_MKS_2-1139871.pdf | $0.48
89 | 1 | R16 | Thick Film Resistors - SMD Thick Film Resistors -SMD 1/8watt 47Kohms 1% 100ppm | Vishay | CRCW080547K0FKEA | Mouser | 71-CRCW0805-47K-E3 | https://www.mouser.com/datasheet/2/427/dcrcwe3-1762152.pdf | $0.10
90 | 1 | X1 | Crystals Crystals 8MHz 20pF | Fox | FOXSDLF/080-20 | Mouser | 559-FOXSD080-20-LF | https://www.mouser.com/datasheet/2/160/C4SD-1131563.pdf | $0.27
91 | 2 | C41, C43 | Multilayer Ceramic Capacitors MLCC - SMD/SMT Multilayer Ceramic Capacitors MLCC - SMD/SMT 1206 100pF 1000volt C0G +/-5% | Murata | GRM31A5C3A101JW01D | Mouser | 81-GRM31A5C3A101J01D | https://www.mouser.com/datasheet/2/281/1/GRM31A5C3A101JW01_01-1987513.pdf | $0.52
92 | 1 | C45 | Multilayer Ceramic Capacitors MLCC - SMD/SMT Multilayer Ceramic Capacitors MLCC - SMD/SMT 50V 0.01uF X7R 0805 10% | KEMET | C0805X103K5RAC7210 | Mouser | 80-C0805X103K5R7210 | https://www.mouser.com/datasheet/2/212/1/KEM_C1013_X7R_FT_CAP_SMD-1103280.pdf | $0.35
93 | 1 | C53 | Multilayer Ceramic Capacitors MLCC - SMD/SMT Multilayer Ceramic Capacitors MLCC - SMD/SMT 50V 0.033uF X7R 0805 10% | KEMET | C0805S333K5RACTU | Mouser | 80-C0805S333K5R | https://www.mouser.com/datasheet/2/212/1/KEM_C1014_X7R_FE_CAP_SMD-1102761.pdf | $0.41
94 | 2 | C55, C56 | Multilayer Ceramic Capacitors MLCC - SMD/SMT Multilayer Ceramic Capacitors MLCC - SMD/SMT 50V 100pF C0G 0805 5% | KEMET | C0805C101J5GACTU | Mouser | 80-C0805C101J5G | https://www.mouser.com/datasheet/2/212/KEM_C1003_C0G_S MD-1101588.pdf | $0.16
95 | 0 | Y1 | Crystals Crystals 32.768KHZ 10PPM 7PF -40C +85C | ABRACON | ABS07-166-32.768KHZ-T | Mouser | 815-ABS0716632.768KT | | $0.66
96 | 1 | Alternate Y1 | Crystals 32.768kHz 6pF -40C +85C | ECS | ECS-.327-6-34G-TR | Mouser | 520-.327-6-34GT | https://www.mouser.com/datasheet/2/122/ECX-34G-1064121.pdf | $0.74

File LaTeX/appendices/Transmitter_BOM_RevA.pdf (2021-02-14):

ASSEMBLY NO: | | DATE: | 03-02-21
ASSEMBLY | Transmitter | PREPARED BY: | David Flory
REVISION: | A | VERIFIED BY: | Franci Franulovic
SOLDER TYPE: | Lead-Free
ITEM | QTY | REFERENCE | DESCRIPTION | MFG | MFG P/N | VENDOR | VENDOR P/N | Datasheet URL | NOTES | Unit Price
1 | 1 | R42 | Thick Film Resistors - SMD Thick Film Resistors - SMD 1/8watt ZEROohm Jumper | Vishay | CRCW08050000Z0EA | Mouser | 71-CRCW0805-0-E3 | https://www.mouser.com/datasheet/2/427/dcrcwe3-1762152.pdf | | $0.10
2 | 1 | R8 | Thick Film Resistors - SMD Thick Film Resistors - SMD 1/8watt 20ohms 1% 100ppm | Vishay | CRCW080520R0FKEA | Mouser | 71-CRCW0805-20-E3 | https://www.mouser.com/datasheet/2/427/dcrcwe3-1762152.pdf | | $0.10
3 | 1 | R23 | Thick Film Resistors - SMD Thick Film Resistors - SMD 1/8watt 40.2ohms 1% 100ppm | Vishay | CRCW080540R2FKTA | Mouser | 71-CRCW0805-40.2 | https://www.mouser.com/datasheet/2/427/dcrcw-1762150.pdf | | $0.16
4 | 2 | R31, R32 | Thick Film Resistors - SMD Thick Film Resistors - SMD 0805 47.0ohms 1% Tol AEC-Q200 | Panasonic | ERJ-6ENF47R0V | Mouser | 667-ERJ-6ENF47R0V | https://www.mouser.com/datasheet/2/315/AOA0000C304-1149620.pdf | | $0.10
5 8 | | R1, R7, R9, R10, R11, R12, R13, R14 | Thick Film Resistors - SMD Thick Film Resistors - SMD 470 OHM 1% | Yageo | RC0805FR-07470RL | Mouser | 603-RC0805FR-07470RL | https://www.mouser.com/datasheet/2/447/PYu_RC_Group_51_RoHS_L_10-1664068.pdf | | $0.13
6 | 4 | TP1, TP2, TP3, TP4 | Circuit Board Hardware - PCB Circuit Board Hardware - PCB TEST POINT BLACK | Keystone Electronics | 5001 | Mouser | 534-5001 | https://www.mouser.com/datasheet/2/215/000-5004-741181.pdf | | $0.35
7 | 1 | P5 | Headers & Wire Housings Headers & Wire Housings WR-PHD 2.54mm Hdr 16P Single Str Gold | Wurth Elektronik | 61301611121 | Mouser | 710-61301611121 | https://www.mouser.com/datasheet/2/445/61301611121-1717958.pdf | | $0.90
8 | 4 | D13, D14, D15, D16 | ESD Suppressors / TVS Diodes ESD Suppressors / TVS Diodes Low Cap Bi TVS 10pF 3.3V 3.8Vbr 25kV | Diodes Incorporated | DESD3V3S1BL-7B | Mouser | 621-DESD3V3S1BL-7B | https://www.mouser.com/datasheet/2/115/DESD3V3S1BL-321080.pdf | | $0.29
9 16 | | C2, C4, C6, C14, C19, C25, C29, C33, C37, C40, C47, C48, C49, C50, C51, C52, C53 | Multilayer Ceramic Capacitors MLCC - SMD/SMT Multilayer Ceramic Capacitors MLCC - SMD/SMT 50V 0.1uF X7R 0805 10% | KEMET | C0805C104K5RACTU | Mouser | 80-C0805C104K5R | https://www.mouser.com/datasheet/2/212/KEM_C1002_X7R_SM D-1102033.pdf | | $0.13
10 | 1 | C13 | Multilayer Ceramic Capacitors MLCC - SMD/SMT Multilayer Ceramic Capacitors MLCC - SMD/SMT 470nF 16V X7R 10% | Yageo | CC0805KKX7R7BB474 | Mouser | 603-CC805KKX7R7BB474 | https://www.mouser.com/datasheet/2/447/UPY-GPHC_X7R_6.3V-to-50V_18-1154002.pdf | | $0.23
11 | 2 | C35, C45 | Multilayer Ceramic Capacitors MLCC - SMD/SMT 0805 1.6pF 250volts C0G 0.1pF | Murata | GQM2195C2E1R6BB12D | Mouser | 81-GQM2195C2E1R6BB2D | https://www.mouser.com/datasheet/2/281/GQM2195C2E1R6BB12_01-1976051.pdf
12 | 3 | C36, C38, C46 | Multilayer Ceramic Capacitors MLCC - SMD/SMT 10volts 10uF X5R 10% | KEMET | C0805C106K8PACTU | Mouser | 80-C0805C106K8P | https://www.mouser.com/datasheet/2/212/KEM_C1006_X5R_SM D-1103249.pdf | | $0.14
13 | 1 | R24 | Thin Film Resistors - SMD Thin Film Resistors - SMD 1/8W 105K ohm .1% 25ppm | Yageo | RT0805BRD07105KL | Mouser | 603-RT0805BRD07105KL | https://www.mouser.com/datasheet/2/447/PYu_RT_1_to_0_01_RoHS_L_11-1669912.pdf | | $0.43
14 6 | | R2, R3, R4, R5, R21, R22 | Thick Film Resistors - SMD Thick Film Resistors - SMD 10K OHM 1% | Yageo | RC0805FR-0710KL | Mouser | 603-RC0805FR-0710KL | https://www.mouser.com/datasheet/2/447/PYu_RC_Group_51_RoHS_L_10-1664068.pdf | | $0.13
15 | 1 | R29 | Thick Film Resistors - SMD Thick Film Resistors - SMD 10K 5% | Bourns | CR0805-JW-103ELF | Mouser | 652-CR0805-JW-103ELF | https://www.mouser.com/datasheet/2/54/crxxxxx-1858361.pdf | | $0.10
16 6 | | C20, C26, C30, C31, C41, C42 | Multilayer Ceramic Capacitors MLCC - SMD/SMT Multilayer Ceramic Capacitors MLCC - SMD/SMT 1206 50V 10uF X5R 10% T: 1.6mm | TDK | C3216X5R1H106K160AB | Mouser | 810-C3216X5R1H106K | https://product.tdk.com/info/en/catalog/datasheets/mlcc_commercial_general_en.pdf?ref_disty=mouser | | $0.85
17 | 2 | C10, C11 | Multilayer Ceramic Capacitors MLCC - SMD/SMT Multilayer Ceramic Capacitors MLCC - SMD/SMT 50V 12pF C0G 0805 5% | KEMET | C0805C120J5GACTU | Mouser | 80-C0805C120J5G | https://www.mouser.com/datasheet/2/212/KEM_C1003_C0G_SM D-1101588.pdf | | $0.11
18 | 1 | Y2 | Standard Clock Oscillators Standard Clock Oscillators 13.56MHz 50ppm -40C +85C | Epson | SG5032CAN 13.560000M-TJGA3 | Mouser | 732-5032CAN13.5TJGA3 | https://www.mouser.com/datasheet/2/137/SG5032CAN_en-961596.pdf | | $1.17
19 | 1 | R20 | Thick Film Resistors - SMD Thick Film Resistors - SMD 1K OHM 1% | Yageo | RC0805FR-071KL | Mouser | 603-RC0805FR-071KL | https://www.mouser.com/datasheet/2/447/PYu_RC_Group_51_RoHS_L_10-1664068.pdf | | $0.13
20 | 2 | R35, R40 | Thick Film Resistors - SMD Thick Film Resistors - SMD 2512 1Kohms 1% Tol AEC-Q200 | Panasonic | ERJ-1TNF1001U | Mouser | 667-ERJ-1TNF1001U | https://www.mouser.com/datasheet/2/315/AOA0000C304-1149620.pdf | | $0.63
21 | 2 | R36, R41 | Thick Film Resistors - SMD Thick Film Resistors - SMD 0805 1Kohms 5% AEC-Q200 | Panasonic | ERJ-6GEYJ102V | Mouser | 667-ERJ-6GEYJ102V | https://www.mouser.com/datasheet/2/315/AOA0000C301-1488782.pdf | | $0.10

22 | 2 | R30, R37 | Thick Film Resistors - SMD Thick Film Resistors - SMD 2512 1Mohms 1% Tol AEC-Q200 | Panasonic | ERJ-1TYF105U | Mouser | 667-ERJ-1TYF105U | https://www.mouser.com/datasheet/2/315/AOA0000C301-1488782.pdf | $0.46
23 | 3 | R33, R34, R39 | Thick Film Resistors - SMD 0805 1.0Mohms 0.5W 1% Tol AEC-Q200 | Panasonic | ERJ-P06F1004V | Mouser | 667-ERJ-P06F1004V | https://www.mouser.com/datasheet/2/315/AOA0000C331-1141874.pdf | $0.18
24 | 4 | C1, C3, C5, C7 | Multilayer Ceramic Capacitors MLCC - SMD/SMT Multilayer Ceramic Capacitors MLCC - SMD/SMT 1.0uF 10V X7R 10% | Yageo | CC0805KKX7R6BB105 | Mouser | 603-CC805KKX7R6BB105 | https://www.mouser.com/datasheet/2/447/UPY-GPHC_X7R_6.3V-to-50V_18-1154002.pdf | $0.25
25 | 1 | C12 | Multilayer Ceramic Capacitors MLCC - SMD/SMT Multilayer Ceramic Capacitors MLCC - SMD/SMT 50V 2200pF X8R 0805 5% | KEMET | C0805C222J5HACTU | Mouser | 80-C0805C222J5H | https://www.mouser.com/datasheet/2/212/KEM_C1007_X8R_ULTRA_150C_SMD-1102703.pdf | $0.69
26 | 3 | C16, C17, C18 | Multilayer Ceramic Capacitors MLCC - SMD/SMT Multilayer Ceramic Capacitors MLCC - SMD/SMT 1210 100V 2.2uF X7R 10% T: 2.3mm | TDK | C3225X7R2A225K230AB | Mouser | 810-C3225X7R2A225K | https://product.tdk.com/info/en/catalog/datasheets/mlcc_commercial_midvoltage_en.pdf?ref_disty=mouser | $0.70
27 | 4 | JP1, P2, P4, P6 | Headers & Wire Housings Headers & Wire Housings 3P VERT HEADER Sn | Molex | 22-28-4030 | Mouser | 538-22-28-4030 | https://www.mouser.com/datasheet/2/276/0022284030_PCB_HEA DERS-228162.pdf | $0.16
28 | 1 | R27 | Thin Film Resistors - SMD Thin Film Resistors - SMD 1/8W 28.7K ohm 1% 50ppm | Yageo | RT0805FRE0728K7L | Mouser | 603-RT0805FRE0728K7L | https://www.mouser.com/datasheet/2/447/PYu_RT_1_to_0_01_RoHS_L_11-1669912.pdf | $0.12
29 | 1 | R26 | Thin Film Resistors - SMD Thin Film Resistors - SMD 1/8W 3.4K ohm .1% 25ppm | Yageo | RT0805BRD073K4L | Mouser | 603-RT0805BRD073K4L | https://www.mouser.com/datasheet/2/447/PYu_RT_1_to_0_01_RoHS_L_11-1669912.pdf | $0.43
30 | 1 | R19 | Thick Film Resistors - SMD Thick Film Resistors - SMD 1/8watt 30Kohms 1% 100ppm | Vishay | CRCW080530K0FKEA | Mouser | 71-CRCW0805-30K-E3 | https://www.mouser.com/datasheet/2/427/dcrcwe3-1762152.pdf | $0.10
31 | 0 | Y1 | Crystals Crystals 32.768KHZ 10PPM 7PF -40C +85C | ABRACON | ABS07-166-32.768KHZ-T | Mouser | 815-ABS0716632.768KT | | $0.66
32 | 1 | Alternate Y1 | Crystals 32.768kHz 6pF -40C +85C | ECS | ECS-.327-6-34G-TR | Mouser | 520-.327-6-34GT | https://www.mouser.com/datasheet/2/122/ECX-34G-1064121.pdf | $0.74
33 | 1 | L1 | Fixed Inductors Fixed Inductors WE-PD 330uH 710mA DCR=750mOhms AECQ200 | Wurth Elektronik | 7447714331 | Mouser | 710-7447714331 | https://www.mouser.com/datasheet/2/445/7447714331-1722496.pdf | $2.17
34 | 1 | J2 | Headers & Wire Housings Headers & Wire Housings FRICTION LCK HDR 5P Straight Post gold | TE Connectivity | 3-641215-5 | Mouser | 571-3-641215-5 | https://www.te.com/commerce/DocumentDelivery/DDEController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 | $1.45
35 | 1 | R25 | Thin Film Resistors - SMD 365Kohms .1% 25ppm | Vishay | TNPW0805365KBEEN | Mouser | 71-TNPW0805365KBEEN | https://www.vishay.com/doc?28771
36 | 1 | C22 | Multilayer Ceramic Capacitors MLCC - SMD/SMT Multilayer Ceramic Capacitors MLCC - SMD/SMT 50V 36pF C0G 0805 5% | KEMET | C0805C360J5GACTU | Mouser | 80-C0805C360J5G | https://www.mouser.com/datasheet/2/212/KEM_C1003_C0G_SM D-1101588.pdf | $0.29
37 | 2 | C8, C9 | Multilayer Ceramic Capacitors MLCC - SMD/SMT Multilayer Ceramic Capacitors MLCC - SMD/SMT 50V 39pF C0G 0805 5% | KEMET | C0805C390J5GACTU | Mouser | 80-C0805C390J5G | https://www.mouser.com/datasheet/2/212/KEM_C1003_C0G_SM D-1101588.pdf | $0.24
38 | 4 | R6, R15, R17, R18 | Thick Film Resistors - SMD Thick Film Resistors - SMD 1/8watt 4.7Kohms 5% 200ppm | Vishay | CRCW08054K70JNTA | Mouser | 71-CRCW0805J-4.7K | https://www.mouser.com/datasheet/2/427/dcrcw-1762150.pdf | $0.12
39 | 1 | R16 | Thick Film Resistors - SMD Thick Film Resistors - SMD 1/8watt 47Kohms 1% 100ppm | Vishay | CRCW080547K0FKEA | Mouser | 71-CRCW0805-47K-E3 | https://www.mouser.com/datasheet/2/427/dcrcwe3-1762152.pdf | $0.10
40 | 1 | C24 | Multilayer Ceramic Capacitors MLCC - SMD/SMT Multilayer Ceramic Capacitors MLCC - SMD/SMT 25V 0.047uF C0G 0805 5% | KEMET | C0805C473J3GACTU | Mouser | 80-C0805C473J3G | https://www.mouser.com/datasheet/2/212/KEM_C1003_C0G_SM D-1101588.pdf | $0.72
41 | 2 | C21, C27 | Multilayer Ceramic Capacitors MLCC - SMD/SMT Multilayer Ceramic Capacitors MLCC - SMD/SMT 1206 25VDC 47uF 20% X5R 1.6mm | TDK | C3216X5R1E476M160AC | Mouser | 810-C3216X5R1E476M | https://product.tdk.com/info/en/catalog/datasheets/mlcc_commercial_general_en.pdf?ref_disty=mouser | $1.05
42 | 1 | C23 | Multilayer Ceramic Capacitors MLCC - SMD/SMT 0.0068uF 50Volts C0G 1% | Murata | GRM2195C1H682FA01D | Mouser | 81-GRM2195C1H682FA1D | https://www.mouser.com/datasheet/2/281/murata_03052018_GRM_Series_1-1310166.pdf
43 | 1 | R28 | Thin Film Resistors - SMD 0805 732Kohm 0.1% 25ppm | Panasonic | ERA-6AEB7323V | Mouser | 667-ERA-6AEB7323V | https://www.mouser.com/datasheet/2/315/AOA0000C307-1149632.pdf
44 | 1 | X1 | Crystals Crystals 8MHz 20pF | Fox | FOXSDLF/080-20 | Mouser | 559-FOXSD080-20-LF | https://www.mouser.com/datasheet/2/160/C4SD-1131563.pdf | $0.27

45 6 | | SW1, SW2, SW3, SW4, SW5, SW6 | Tactile Switches Tactile Switches Top Actuated w/o boss w/o ground | Omron | B3U-1000P | Mouser | 653-B3U-1000P | https://www.mouser.com/datasheet/2/307/en-b3u-3615.pdf | $0.92
46 | 2 | D20, D21 | Schottky Diodes & Rectifiers Schottky Diodes & Rectifiers Silicon Schottky Didode | Infineon | BAS140WE6327HTSA1 | Mouser | 726-BAS140WE6327HTSA | https://www.mouser.com/datasheet/2/196/Infineon-BAS40_BAS140SERIES-DS-v01_01-en-767893.pdf | $0.48
47 | 2 | C28, C39 | Trimmer / Variable Capacitors Trimmer / Variable Capacitors TRIMMER CAPACITOR | Vishay | BFC280832659 | Mouser | 594-2222-808-32659 | https://www.vishay.com/doc?28528 | $7.21
48 | 4 | C32, C34, C43, C44 | Multilayer Ceramic Capacitors MLCC - SMD/SMT Multilayer Ceramic Capacitors MLCC - SMD/SMT 100pF 1KV C0G 5% | Vishay | VJ1812A101JXGAT | Mouser | 77-VJ1812A101JXGAT | https://www.mouser.com/datasheet/2/427/vjcommercialseries-1764145.pdf | $0.76
49 | 1 | C15 | Aluminum Organic Polymer Capacitors Aluminum Organic Polymer Capacitors 50volts 68uF ESR 20mohm | Panasonic | 50SVPF68M | Mouser | 667-50SVPF68M | https://www.mouser.com/datasheet/2/315/AAB8000C177-947360.pdf | $2.65
50 6 | | D3, D4, D11, D12, D17, D18 | ESD Suppressors / TVS Diodes ESD Suppressors / TVS Diodes Low Cap Bi TVS 10pF 3.3V 3.8Vbr 25kV | Diodes Incorporated | DESD3V3S1BL-7B | Mouser | 621-DESD3V3S1BL-7B | https://www.mouser.com/datasheet/2/115/DESD3V3S1BL-321080.pdf | $0.29
51 | 1 | R38 | Thick Film Resistors - SMD Thick Film Resistors - SMD 0805 47.0ohms 1% Tol AEC-Q200 | Panasonic | ERJ-6ENF47R0V | Mouser | 667-ERJ-6ENF47R0V | https://www.mouser.com/datasheet/2/315/AOA0000C304-1149620.pdf | $0.10
52 | 1 | Q1 | N-Channel 200V 8.5A (Ta) Surface Mount Die | EPC | EPC2019 | Digikey | 917-1087-2-ND | https://epc-co.com/epc/Portals/0/epc/documents/datasheets/EPC2019_datas heet.pdf | 3.54
53 | 1 | Q2 | N-Channel 200V 48A (Ta) Surface Mount Die | EPC | EPC2034C | Digikey | 917-1214-2-ND | https://epc-co.com/epc/Portals/0/epc/documents/datasheets/EPC2034C_data sheet.pdf | 7.32
54 | 2 | L4, L5 | Fixed Inductors Fixed Inductors 47uH 20% | Vishay | IHLP4040DZER470M11 | Mouser | 71-IHLP4040DZER470M1 | http://www.vishay.com/doc?34251 | $2.58
55 | 1 | J1 | DC Power Connectors DC Power Connectors 4P JACK SKT SHIELDED SNAP AND LOCK | Kycon | KPJX-4S-S | Mouser | 806-KPJX-4S-S | https://www.snapeda.com/parts/KPJX-4S-S/Kycon/view-part/?ref=mouser | $2.23
56 | 1 | U11 | Gate Drivers Gate Drivers Tiny 7A MOSFET Gate Dvr | Texas Instruments | LM5112MY/NOPB | Mouser | 926-LM5112MY/NOPB | https://www.ti.com/lit/pdf/snva606 | $1.31
57 | 1 | U9 | Non-Isolated DC/DC Converters Non-Isolated DC/DC Converters | Texas Instruments | LMZM23600V3SILR | Mouser | 595-LMZM23600V3SILR | https://www.ti.com/lit/pdf/snva807a | $4.52
58 | 1 | U10 | Non-Isolated DC/DC Converters Non-Isolated DC/DC Converters | Texas Instruments | LMZM23600V5SILR | Mouser | 595-LMZM23600V5SILR | https://www.ti.com/lit/pdf/snva807a | $4.52
59 | 1 | U1 | Supervisory Circuits Supervisory Circuits Open Drain | Microchip | MCP111T-240E/TT | Mouser | 579-MCP111T-240E/TT | https://www.mouser.com/datasheet/2/268/21889b-64653.pdf | $0.47
60 | 1 | U7 | Digital Potentiometer ICs Digital Potentiometer ICs Sngl 7B V I2C POT | Microchip | MCP4531-103E/MS | Mouser | 579-MCP4531-103E/MS | https://www.mouser.com/datasheet/2/268/DS-22096a-36447.pdf | $0.70
61 | 1 | U5 | Operational Amplifiers - Op Amps Operational Amplifiers - Op Amps Single 1.8V 1MHz | Microchip | MCP6001T-I/OT | Mouser | 579-MCP6001T-I/OT | https://www.mouser.com/datasheet/2/268/21733j-740845.pdf | $0.24
62 | 2 | L2, L3 | Ferrite Beads Ferrite Beads 600 ohms 25% HIGH CURRENT | Bourns | MH3261-601Y | Mouser | 652-MH3261-601Y | https://www.mouser.com/datasheet/2/54/mh-777565.pdf | $0.10
63 | 2 | F2, F3 | Resettable Fuses - PPTC Resettable Fuses - PPTC .5A 13.2V 40A Imax | Littelfuse | MICROSMD050F-2 | Mouser | 650-MICROSMD050F-2 | https://www.mouser.com/datasheet/2/240/Littelfuse_PTC_MICROSMD_Catalog_Datasheet.pdf-1021745.pdf | $0.47
64 | 1 | U2 | 16-bit Microcontrollers - MCU 16-bit Microcontrollers - MCU | Texas Instruments | MSP430FR5994IPM | Mouser | 595-MSP430FR5994IPM | https://www.ti.com/lit/pdf/slaa722 | $8.11
65 | 1 | U6 | Gate Drivers Gate Drivers 12V Industrial Relay Inductive Load | ON Semiconductor | NUD3112LT1G | Mouser | 863-NUD3112LT1G | http://www.onsemi.com/pub/Collateral/AND8116-D.PDF | $0.44
66 | 1 | F1 | Resettable Fuses - PPTC Resettable Fuses - PPTC Radial Lead 2.5A 72V 40A Imax | Littelfuse | RXEF250 | Mouser | 650-RXEF250 | https://www.mouser.com/datasheet/2/240/Littelfuse_PTC_Rline_Catalog_Datasheet.pdf-1021735.pdf | $0.63
67 | 2 | P7, P9 | Headers & Wire Housings Headers & Wire Housings WR-PHD 2.54mm SMT 6P Hdr Dual Strt | Wurth Elektronik | 61000621121 | Mouser | 710-61000621121 | https://www.mouser.com/datasheet/2/445/61000621121-1717892.pdf | $0.93
68 | 1 | D19 | Schottky Diodes & Rectifiers Schottky Diodes & Rectifiers 3.0 Amp 100 Volt | Vishay | SS3H10-E3/57T | Mouser | 625-SS3H10-E3 | https://www.mouser.com/datasheet/2/427/ss3h9-1768234.pdf | $0.60
69 | 1 | U8 | Switching Voltage Regulators Switching Voltage Regulators 3.5-60V 2.5A 2.5MHz Step Down Converter | Texas Instruments | TPS54260DGQR | Mouser | 595-TPS54260DGQR | https://www.ti.com/lit/pdf/slva464e | $3.50
70 | 1 | U3 | Translation - Voltage Levels Translation - Voltage Levels 4-Bit Bi-directional V-Level Translator | Texas Instruments | TXB0104PWR | Mouser | 595-TXB0104PWR | https://www.ti.com/lit/pdf/scea064 | $0.93
71 | 1 | U4 | Translation - Voltage Levels Translation - Voltage Levels 8-Bit Bi-directional V-Level Translator | Texas Instruments | TXB0108PWR | Mouser | 595-TXB0108PWR | http://www.ti.com/general/docs/suppproductinfo.tsp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 | $1.29

72 | 1 | L1A | Fixed Inductors Fixed Inductors 330uH Shld 10% 1.7A 360mOhms AECQ2 | Coilcraft | MSS1210-334KED | Mouser | 994-MSS1210-334KED | https://www.mouser.com/datasheet/2/597/mss1210-270677.pdf | $2.26
73 | 1 | L1B | Fixed Inductors Fixed Inductors WE-PD 330uH 1.5A DCR=430mOhms AECQ200 | Wurth Elektronik | 7447709331 | Mouser | 710-7447709331 | https://www.mouser.com/datasheet/2/445/7447709331-1722838.pdf | $2.41
74 | 1 | L1C | Fixed Inductors Fixed Inductors PA4320 12x12mm 330uH 1.7A 340mOhms | Pulse | PA4320.334NLT | Mouser | 673-PA4320.334NLT | https://www.mouser.com/datasheet/2/336/P787-1526943.pdf | $2.57
75 8 | | D1, D2, D5, D6, D7, D8, D9, D10 | Standard LEDs - SMD Standard LEDs - SMD Red Diffused 626nm 10mcd | Broadcom Limited | HSMS-C150 | Mouser | 630-HSMS-C150 | https://www.mouser.com/datasheet/2/678/av02-0551en-ds-hsmx-cxxx-05mar2012-1827675.pdf | $0.41
76 | 1 | MD1 | Bluetooth Modules (802.15.1) Bluetooth Modules (802.15.1) Bluetooth Low Energy BLE Module, Shielded, Antenna, ASCII Interface, 12x22mm | Microchip | RN4870-I/RM140 | Mouser | 579-RN4870-I/RM140 | https://www.mouser.com/datasheet/2/268/RN4870-71-Bluetooth-Low-Energy-Module-Data-Sheet-D-1658564.pdf | $7.38
77 | 1 | P3 | Headers & Wire Housings Headers & Wire Housings WR-PHD1.27mm Hdr 14P Dual Str Gold | Wurth Elektronik | 62201421121 | Mouser | 710-62201421121 | https://www.mouser.com/datasheet/2/445/62201421121-1718302.pdf | $1.48

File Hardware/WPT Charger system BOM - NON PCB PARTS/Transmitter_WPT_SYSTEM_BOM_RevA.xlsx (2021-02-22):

 |  |  |  |  |  |  |  |  |  |  |  |  |  | Number of full units | 1
 |  | ASSEMBLY NO: |  |  | DATE: | 2021-02-03
 |  | ASSEMBLY NAME: | Wireless Charger System |  | PREPARED BY: | Franci Franulovic
 |  | REVISION: | A |  | VERIFIED BY: | David Flory
 |  | SOLDER TYPE: | Lead-Free
ITEM | QTY | REFERENCE | DESCRIPTION | MFG | MFG P/N | VENDOR | VENDOR P/N | Datasheet URL | NOTES | Unit Price | Quantity | Order Price | Min Quantity | Quoted Part Number | Availability | Min\Mult Order Qty
1 | 1 | RECEIVER | Desktop AC Adapters 65W 48Vout 1.36A | TDK-Lambda | DT62PW480D | Mouser | 967-DT62PW480D | https://www.mouser.com/datasheet/2/400/dt62-80-d_e-1825770.pdf |  | $53.00 | 1 | $53.00 | 1\1 | 967-DT62PW480D | 6 | 1\1
2 | 1 | RECEIVER / TRANSMITTER | Electrical Enclosures IP68/NEMA 6P Plastic Enclosure 5.88" x 4.38" x 2.19" Opaque | Bud Industries | PU-16537 | Mouser | 967-DT62PW480D | https://www.mouser.com/catalog/specsheets/Bud_PU%20Series_NEMA_6PIP68_PC_Enclosure.pdf |  | $25.30 | 1 | $25.30 | 1\1 | 563-PU-16537 | 8 | 1\1
3 | 1 | RECEIVER | Printed Circuit Board | JLC PCB |  | JLC PCB |  |  | Custom made | $6.68 | 1 | $6.68 | 5
4 | 1 | TRANSMITTER | Printed Circuit Board | JLC PCB |  | JLC PCB |  |  | Custom made | $6.69 | 1 | $6.69 | 5
5 | 0.1 | COIL RECEIVER | Hook-up Wire 14AWG 19/27 PTFE Spool 304.8 m | Alpha Wire | 5859 RD005 | Mouser | 602-5859-100-03 | https://www.mouser.com/datasheet/2/14/AW_Product_Specification-1837536.pdf |  | $1.98 | 0.1 | $0.20 | 304.8m
6 | 0.1 | COIL TRANSMITTER | Hook-up Wire 14AWG 19/27 PTFE Spool 304.8 m | Alpha Wire | 5859 RD005 | Mouser | 602-5859-100-03 | https://www.mouser.com/datasheet/2/14/AW_Product_Specification-1837536.pdf |  | $1.98 | 0.1 | $0.20 | 304.8m
7 | 4 | COIL RECEIVER / TRANSMITTER | Terminals SOLIS DIN 0.5-1.0 | TE Connectivity | 165291 | Mouser | 571-165291 | https://www.te.com/commerce/DocumentDelivery/DDEController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 |  | $0.45 | 4 | $1.80 | 1\1
8 | 0.67 | COIL RECEIVER | Super-Conductive 101 Copper TubesCopper Tubing 1/8" 3ft spool | Mcmaster-Carr | 8965K22 | Mcmaster-Carr | 8965K22 | https://www.mcmaster.com/tubing/od~1-8/material~copper/ |  | $6.94 | 0.67 | $4.65
9 | 0.67 | COIL TRANSMITTER | Super-Conductive 101 Copper TubesCopper Tubing 1/8" 3ft spool | Mcmaster-Carr | 8965K22 | Mcmaster-Carr | 8965K22 | https://www.mcmaster.com/tubing/od~1-8/material~copper/ |  | $6.94 | 0.67 | $4.65
10 | 1 | Receiver | RRC-SMBus Cable | RRC | RRC-SMBus Cable | Mouser | 328-RRCSMBUSCABLE | https://www.mouser.com/datasheet/2/836/DS_SMBus_Battery_Cable_B-1360935.pdf |  | $22.35 | 1 | $22.35 | 1\1 | 328-RRCSMBUSCABLE |  | 1\1
11 | 2 | COIL RECEIVER / TRANSMITTER | Enclosures, Boxes, & Cases SENSOR CUBE WHITE | New Age Enclosures | 789-S1A-404012 | Mouser | 789-S1A-404012 | https://www.mouser.com/datasheet/2/290/NewAgeEnclosures_12092019_404012_cube_r1_0-1673104.pdf | Coil enclosure | $5.70 | 2 | $11.40 | 1\1
 |  |  |  |  |  |  |  |  |  |  | TOTAL COST | $136.92

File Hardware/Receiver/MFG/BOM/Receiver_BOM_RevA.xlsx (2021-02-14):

 |  |  |  |  |  |  |  |  |  |  |  |  |  | Number of assembled boards | 1
 |  | ASSEMBLY NO: |  |  | DATE: | 2021-02-03
 |  | ASSEMBLY NAME: | HEC2 Receiver |  | PREPARED BY: | David Flory
 |  | REVISION: | A |  | VERIFIED BY: | Franci Franulovic
 |  | SOLDER TYPE: | Lead-Free
ITEM | QTY | REFERENCE | DESCRIPTION | MFG | MFG P/N | VENDOR | VENDOR P/N | Datasheet URL | NOTES | Unit Price | Order Quantity | Order Price | Min Quantity | Quoted Part Number | Availability | Min\Mult Order Qty
1 | 4 | C1, C3, C5, C7 | Multilayer Ceramic Capacitors MLCC - SMD/SMT Multilayer Ceramic Capacitors MLCC - SMD/SMT 1.0uF 10V X7R 10% | Yageo | CC0805KKX7R6BB105 | Mouser | 603-CC805KKX7R6BB105 | https://www.mouser.com/datasheet/2/447/UPY-GPHC_X7R_6.3V-to-50V_18-1154002.pdf |  | $0.25 | 4 | $1.00 | 1\1 | 603-CC805KKX7R6BB105 | 65,772 | 1\1
2 | 14 | C2, C4, C6, C17, C21, C27, C30, C33, C34, C35, C36, C37, C38, C39 | Multilayer Ceramic Capacitors MLCC - SMD/SMT Multilayer Ceramic Capacitors MLCC - SMD/SMT 50V 0.1uF X7R 0805 10% | KEMET | C0805C104K5RACTU | Mouser | 80-C0805C104K5R | https://www.mouser.com/datasheet/2/212/KEM_C1002_X7R_SMD-1102033.pdf |  | $0.13 | 14 | $1.76 | 1\1 | 80-C0805C104K5R | 2,621,359 | 1\1
3 | 2 | C8, C9 | Multilayer Ceramic Capacitors MLCC - SMD/SMT Multilayer Ceramic Capacitors MLCC - SMD/SMT 50V 39pF C0G 0805 5% | KEMET | C0805C390J5GACTU | Mouser | 80-C0805C390J5G | https://www.mouser.com/datasheet/2/212/KEM_C1003_C0G_SMD-1101588.pdf |  | $0.24 | 2 | $0.48 | 1\1 | 80-C0805C390J5G | 21,849 | 1\1
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

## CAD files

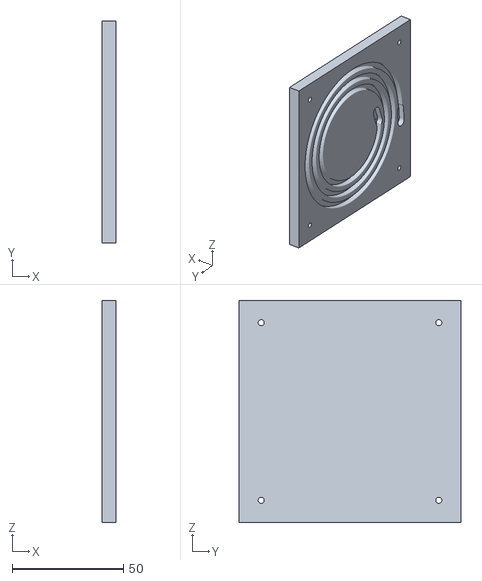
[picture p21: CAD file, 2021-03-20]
docs/Hardware/coil_box.stl
6.50 x 100.0 x 100.0

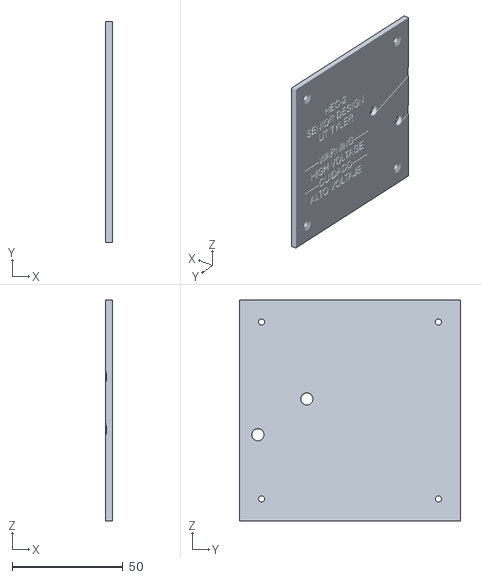
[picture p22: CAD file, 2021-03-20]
docs/Hardware/coil_lid.stl
3.00 x 100.0 x 100.0

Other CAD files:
LaTeX/images/coil_box.dwg
LaTeX/images/coil_box.f3d
docs/Hardware/coil_box.dwg
docs/Hardware/coil_box.f3d

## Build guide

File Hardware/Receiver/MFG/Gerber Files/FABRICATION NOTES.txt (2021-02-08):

13.56 MHz Receiver Rev.A

BOARD SIZE:  5.702 INCH (144.821 mm) X 4.203 INCH (106.76 mm)
Layers: 4
PCB Layers Stack-up 

1. HEC2_Receiver_Copper_Signal_Top.gbr  	TOP SIGNAL
2. HEC2_Receiver_Copper_Plane_1.gbr		GROUND PLANE
3. HEC2_Receiver_Copper_Signal_1.gbr		MID1 SIGNAL
4. HEC2_Receiver_Copper_Signal_Bot.gbr	BOTTOM SIGNAL

Material: FR4 (135degC Tg) RoHS COMPLIANT
Board Thickness: 0.063"
Surface finish: Immersion Gold (Electroless Nickel Gold - ENIG)
Solder Mask Color: Red
Silkscreen Color: White
Min. Drill: 8 mils
Min. Line Width: 8 mils
Min. Spacing: 4 mils

GERBER FILES

File Name		Layer

HEC2_Receiver_Copper_Signal_Top.gbr  	TOP SIGNAL
HEC2_Receiver_Copper_Plane_1.gbr	GROUND PLANE
HEC2_Receiver_Copper_Signal_1.gbr	MID1 SIGNAL
HEC2_Receiver_Copper_Signal_Bot.gbr	BOTTOM SIGNAL
HEC2_Receiver_Soldermask_Top.gbr	TOP MASK
HEC2_Receiver_Soldermask_Bot.gbr	BOTTOM MASK
HEC2_Receiver_Legend_Top.gbr		TOP SILK
HEC2_Receiver_Legend_Bot.gbr		BOTTOM SILK
HEC2_Receiver_Paste_Top.gbr		TOP PASTE
HEC2_Receiver_Paste_Bot.gbr		BOTTOM PASTE

HEC2_Receiver_PTH_Drill.gbr		PTH DRILL - FOR REFERENCE ONLY
HEC2_Receiver_NPTH_Drill.gbr		NPTH DRILL - FOR REFERENCE ONLY

DRILL

HEC2_Receiver.TXT		N/C DRILL

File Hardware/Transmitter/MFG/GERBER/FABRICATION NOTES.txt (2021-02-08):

13.56 MHz Transmitter Rev.A

BOARD SIZE:  5.702 INCH (144.821 mm) X 4.203 INCH (106.76 mm)
Layers: 4
PCB Layers Stack-up 

1. Transmitter_RevA_Copper_Signal_Top.gbr  	TOP SIGNAL
2. Transmitter_RevA_Copper_Plane_1.gbr		GROUND PLANE
3. Transmitter_RevA_Copper_Signal_1.gbr		MID1 SIGNAL
4. Transmitter_RevA_Copper_Signal_Bot.gbr	BOTTOM SIGNAL

Material: FR4 (135degC Tg) RoHS COMPLIANT
Board Thickness: 0.063"
Surface finish: Immersion Gold (Electroless Nickel Gold - ENIG)
Solder Mask Color: Red
Silkscreen Color: White
Min. Drill: 8 mils
Min. Line Width: 8 mils
Min. Spacing: 4 mils

GERBER FILES

File Name		Layer

Transmitter_RevA_Copper_Signal_Top.gbr  TOP SIGNAL
Transmitter_RevA_Copper_Plane_1.gbr	GROUND PLANE
Transmitter_RevA_Copper_Signal_1.gbr	MID1 SIGNAL
Transmitter_RevA_Copper_Signal_Bot.gbr	BOTTOM SIGNAL
Transmitter_RevA_Soldermask_Top.gbr	TOP MASK
Transmitter_RevA_Soldermask_Bot.gbr	BOTTOM MASK
Transmitter_RevA_Legend_Top.gbr		TOP SILK
Transmitter_RevA_Legend_Bot.gbr		BOTTOM SILK
Transmitter_RevA_Paste_Top.gbr		TOP PASTE
Transmitter_RevA_Paste_Bot.gbr		BOTTOM PASTE

Transmitter_RevA_PTH_Drill.gbr		PTH DRILL - FOR REFERENCE ONLY
Transmitter_RevA_NPTH_Drill.gbr		NPTH DRILL - FOR REFERENCE ONLY

DRILL

Transmitter_RevA-RoundHoles.TXT		N/C DRILL ROUND HOLES
Transmitter_RevA-SlotHoles.TXT		N/C DRILL SLOT HOLES

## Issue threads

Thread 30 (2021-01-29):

Note Development Plans where Prototype Failures to Deliver Design Specification

gibbs212521, 2021-01-29:

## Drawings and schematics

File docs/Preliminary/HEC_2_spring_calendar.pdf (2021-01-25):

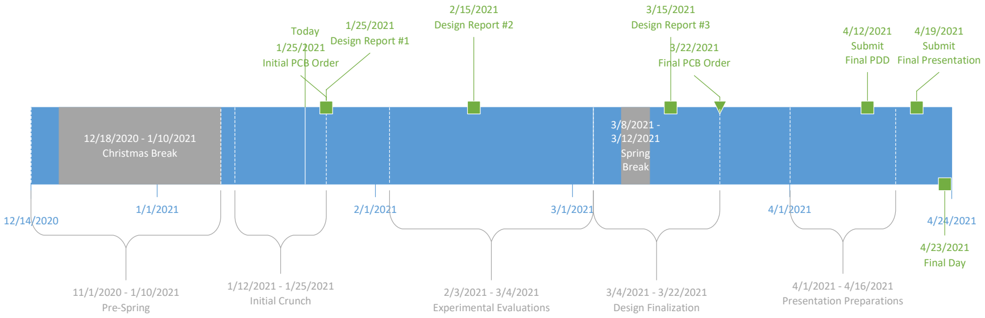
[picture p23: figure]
1/12/2021 - 1/25/2021 Initial Crunch; 4/23/2021 Final Day; Today; 3/22/2021 Final PCB Order; 4/1/2021 - 4/16/2021 Presentation Preparations; 12/18/2020 - 1/10/2021 Christmas Break; 11/1/2020 - 1/10/2021 Pre-Spring; 2/3/2021 - 3/4/2021 Experimental Evaluations; 3/8/2021 - 3/12/2021 Spring Break; 1/25/2021 Initial PCB Order; 3/4/2021 - 3/22/2021 Design Finalization; Design Report #1; 2/15/2021 Design Report #2; Design Report #3; Submit Final PDD; 4/19/2021 Submit Final Presentation

1/25/2021

2/15/2021 | 3/15/2021

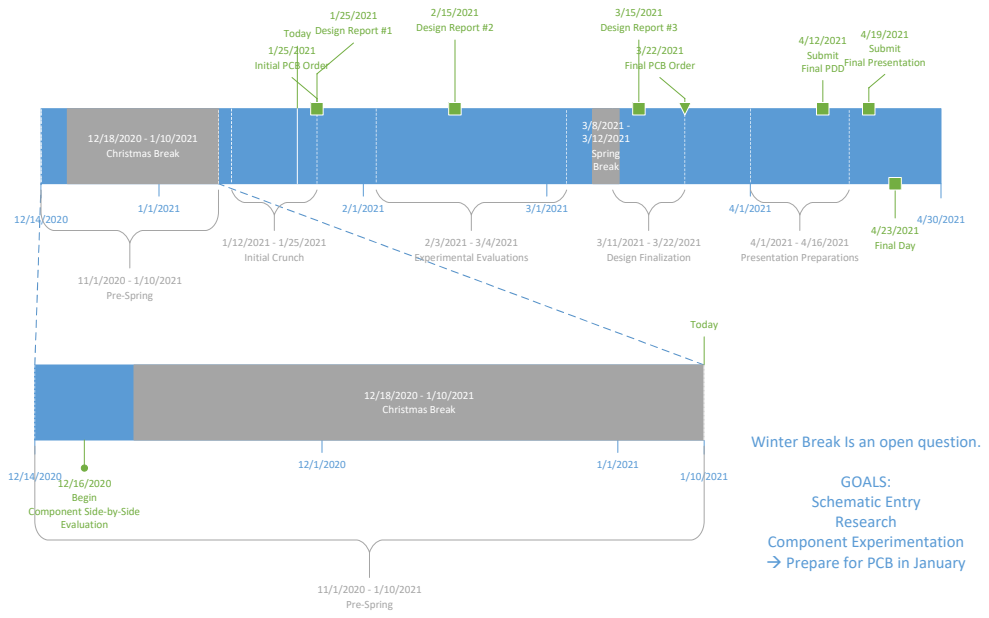
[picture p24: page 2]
12/18/2020 - 1/10/2021 Christmas Break; 11/1/2020 - 1/10/2021 Pre-Spring; 4/23/2021 Final Day; 12/16/2020 Begin; 2/3/2021 - 3/4/2021 Experimental Evaluations; 1/12/2021 - 1/25/2021 Initial Crunch; 3/11/2021 - 3/22/2021 Design Finalization; 4/1/2021 - 4/16/2021 Presentation Preparations; GOALS: Schematic Entry Research; 3/8/2021 - 3/12/2021 Spring Break; Today; Design Report #1; 4/12/2021 Submit Final PDD; Submit Final Presentation

Design Report #3
Final PCB Order

Initial PCB Order

Winter Break Is an open question.

Component Side-by-Side
Evaluation

Component Experimentation
Prepare for PCB in January

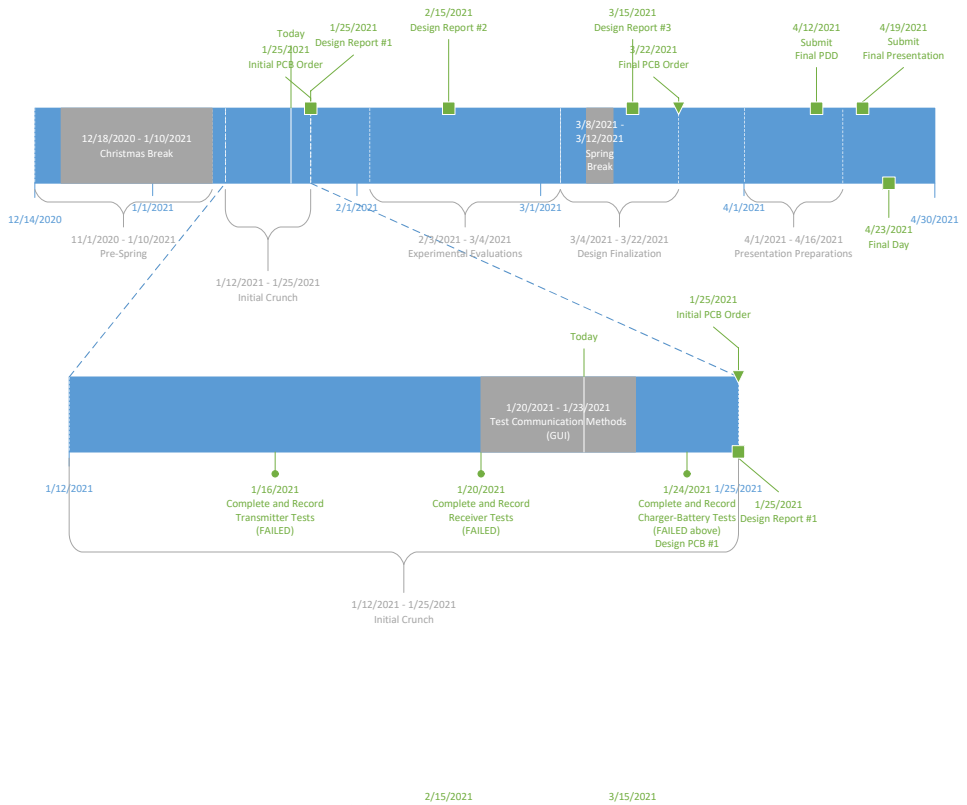
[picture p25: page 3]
1/12/2021 - 1/25/2021 Initial Crunch; Today; 3/4/2021 - 3/22/2021 Design Finalization; 4/23/2021 Final Day; 4/1/2021 - 4/16/2021 Presentation Preparations; 11/1/2020 - 1/10/2021 Pre-Spring; (GUI); 2/3/2021 - 3/4/2021 Experimental Evaluations; 12/18/2020 - 1/10/2021 Christmas Break; 1/25/2021 Initial PCB Order; 3/8/2021 - 3/12/2021 Spring Break; 1/25/2021 Design Report #1; Design Report #2; 4/12/2021 Submit Final PDD; 4/19/2021 Submit Final Presentation

Design Report #3
Final PCB Order

Initial PCB Order

Test Communication Methods

Complete and Record
Transmitter Tests
(FAILED)

Charger-Battery Tests
(FAILED above)
Design PCB #1

Receiver Tests

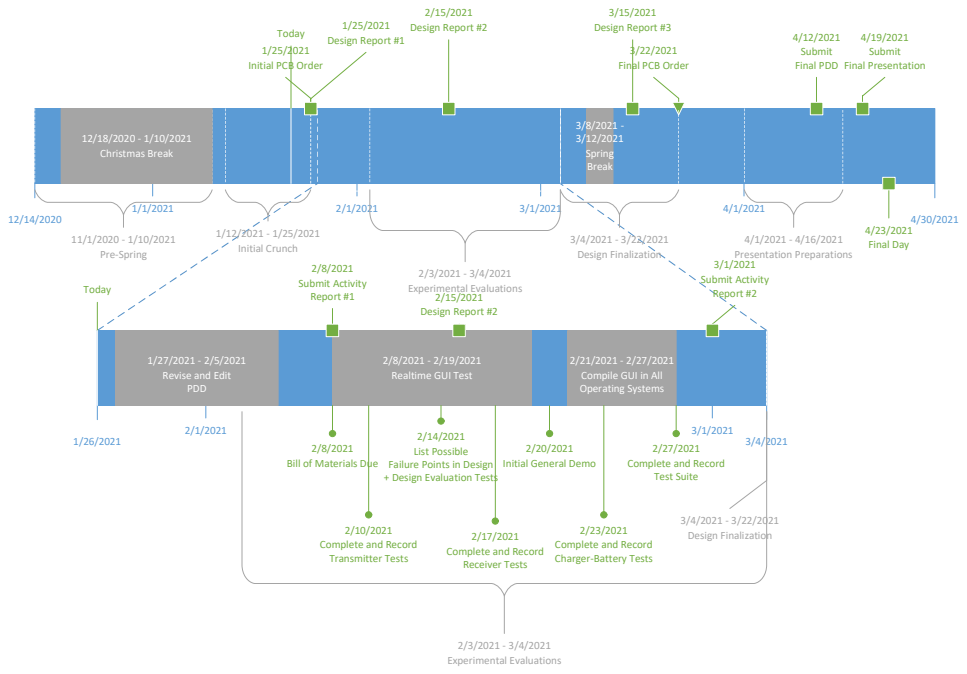
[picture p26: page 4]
11/1/2020 - 1/10/2021 Pre-Spring; 2/3/2021 - 3/4/2021 Experimental Evaluations; 12/18/2020 - 1/10/2021 Christmas Break; 1/12/2021 - 1/25/2021 Initial Crunch; 3/4/2021 - 3/22/2021 Design Finalization; 4/1/2021 - 4/16/2021 Presentation Preparations; 4/23/2021 Final Day 3/4/2021 - 3/22/2021 Design Finalization; 1/27/2021 - 2/5/2021 Revise and Edit PDD; 3/8/2021 - 3/12/2021 Spring Break; Today; Design Report #1; 2/15/2021 Design Report #2; 4/12/2021 Submit Final PDD; Submit Final Presentation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

Initial PCB Order

Final PCB Order

Realtime GUI Test

Compile GUI in All
Operating Systems

List Possible
Failure Points in Design
+ Design Evaluation Tests

Bill of Materials Due

Initial General Demo

Complete and Record
Test Suite

Transmitter Tests

Receiver Tests

Charger-Battery Tests

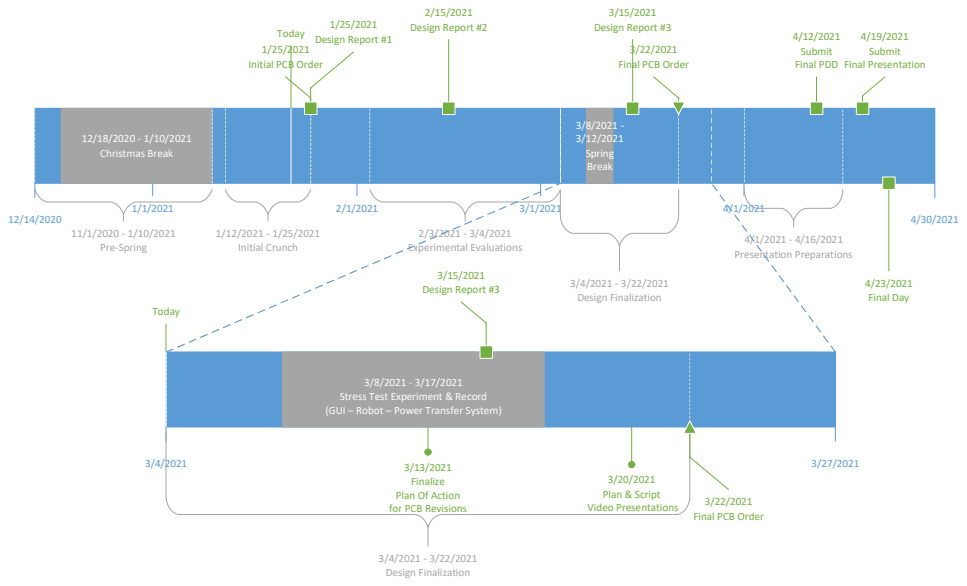
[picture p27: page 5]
12/18/2020 - 1/10/2021 Christmas Break; 3/4/2021 - 3/22/2021 Design Finalization; 1/12/2021 - 1/25/2021 Initial Crunch; 11/1/2020 - 1/10/2021 Pre-Spring; 4/23/2021 Final Day; 1/25/2021 Initial PCB Order; Today; 4/1/2021 - 4/16/2021 Presentation Preparations; 2/3/2021 - 3/4/2021 Experimental Evaluations; 3/20/2021 Plan & Script Video Presentations; 3/8/2021 - 3/12/2021 Spring Break; 1/25/2021 Design Report #1; Design Report #2; 3/15/2021 Design Report #3; 4/12/2021 Submit Final PDD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

Design Report #3
Final PCB Order

Stress Test Experiment & Record
(GUI – Robot – Power Transfer System)

Finalize
Plan Of Action
for PCB Revisions

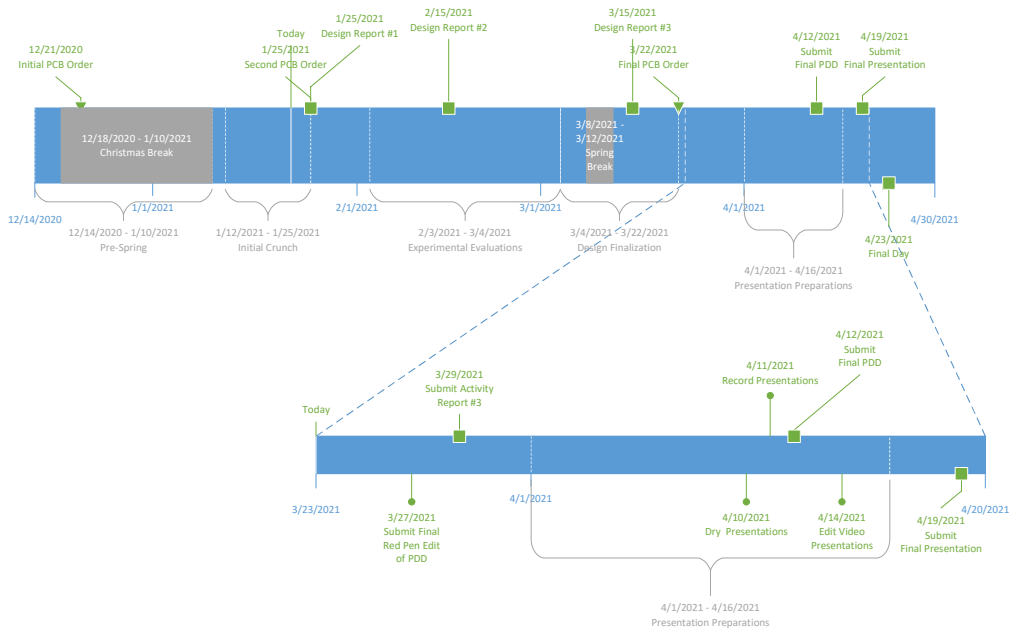
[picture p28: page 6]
4/1/2021 - 4/16/2021 Presentation Preparations; 1/25/2021 Second PCB Order; 4/12/2021 Submit Final PDD; 12/14/2020 - 1/10/2021 Pre-Spring; 1/12/2021 - 1/25/2021 Initial Crunch; 4/14/2021 Edit Video Presentations; 4/10/2021 Dry Presentations; 4/23/2021 Final Day; 3/4/2021 - 3/22/2021 Design Finalization; 4/11/2021 Record Presentations; Today; 12/18/2020 - 1/10/2021 Christmas Break; 2/3/2021 - 3/4/2021 Experimental Evaluations; Design Report #1; 4/19/2021 Submit Final Presentation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

Initial PCB Order

Final PCB Order

Submit Final
Red Pen Edit
of PDD

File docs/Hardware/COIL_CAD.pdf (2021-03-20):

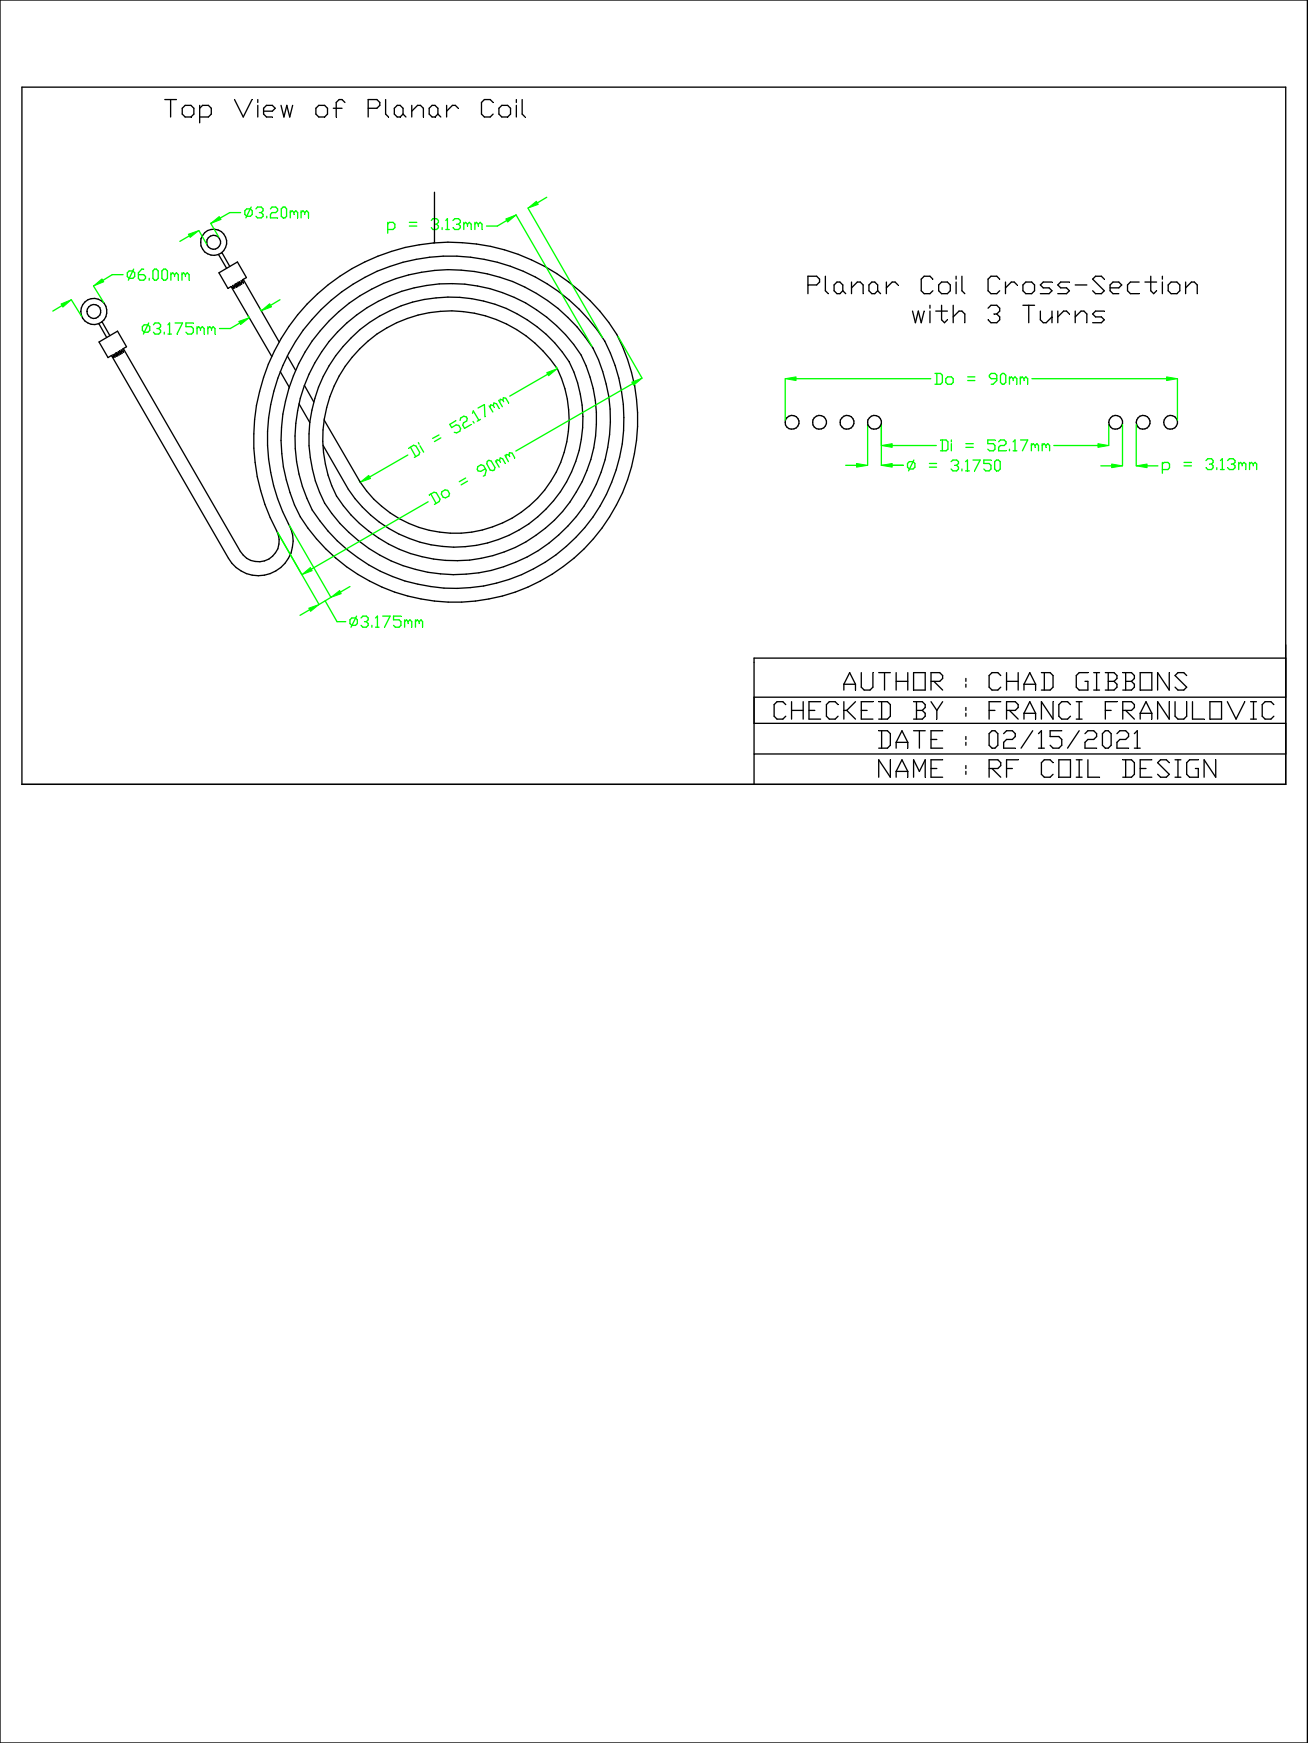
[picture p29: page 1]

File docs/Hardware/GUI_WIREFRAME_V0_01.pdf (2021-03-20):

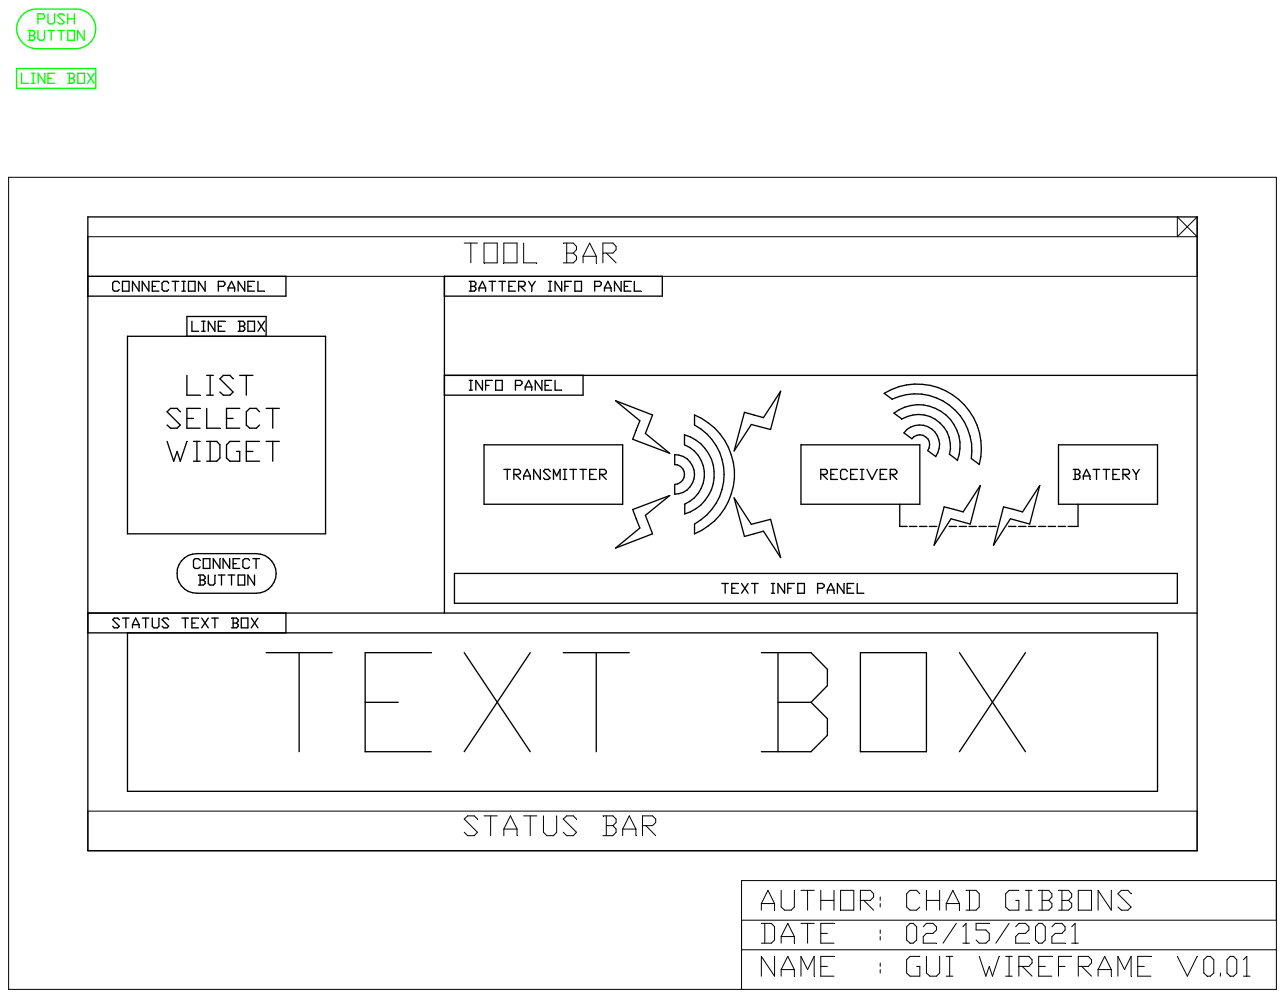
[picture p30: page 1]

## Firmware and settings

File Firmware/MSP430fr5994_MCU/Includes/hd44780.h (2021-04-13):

#ifndef HD44780_H_ // Don't touch
#define HD44780_H_ // Don't touch


#include "stdint.h" // Don't touch


// INFORMATION - please read this first:
//
// Version: 1.00 - Initial realease
// Date   : March 31, 2017
// Author : Dennis Eichmann
//
// This library offers an easy and flexible way to connect a HD44780 (or compatible) display to a microcontroller like the MSP430 or MSP432.
// Of course it can be used on other controllers as well - simply replace the controller specific denominations.
//
// NOTE: The display is used in write mode only, so R/W needs to be tied to GND.
//
// The library works timer based and uses a buffer that holds the display content. By calling a single function of this library inside a timer interrupt
// every 1 ms to 10 ms, the data will automatically be written from the buffer to the display. This ensures that there won't be any timing violations
// for the HD44780 controller, one of the most often seen issues when beginners start working with this popular type of display. This also applies to the
// initialization of the controller - if the timing is wrong during the initialization process, the display will never work as expected.
// A frequently seen workaround for timing issues are delay loops, often adjusted until it finally works, at least as long as the processor's clock frequency
// isn't changed. This timer based method eliminates these issues, regardless of the processor's clock speed and it removes the program blocking delay loops.
// Another benefit is the flexible hardware interface - the library supports the usual parallel connection to the microcontroller as well as a serialized
// interface via a 74HCT595 or 74HCT164 shift register, both as full eight bit or four bit nibble mode. In addition, all connections can be mixed up
// between different ports and the pins also do not need to be consecutive.
//
// But of course you do not only get advantages for free - the library adds some unnecessary overhead you normally could avoid when writing the code
// for one specific application on a given hardware setup. Some drawbacks are the data buffer, for example. For a 4x20 display, this requires 80 bytes of RAM
// already and the library needs some amount of non-volatile memory, of course. The timer will somehow keep the controller active, at least in intervals,
// so it is not the most power saving way. Keep in mind that the display is updated, regardless if the content has changed or not. The very flexible way of
// connecting the display to completely mixed up ports and pins adds some clock cycles for setting the outputs you would not have when writing a complete
// byte to a port for a display having D0 to D7 connected to Px.0 to Px.7 of the microcontroller. And although this library uses conditional compiling,
// depending on the selections made by the user, a tiny amount of extra processing might still be existing.
//
// These small drawbacks will be negligible for most users, but I wanted to mention them anyway.
//
// For questions, suggestions, error reports or any other problems, just contact me: https://e2e.ti.com/members/3534089
// Alternatively open a question or discussion on the TI E2E forum: https://e2e.ti.com/support/microcontrollers/msp430/
// The latest version, more information and some application examples can be found here: https://e2e.ti.com/group/launchyourdesign/m/msp430microcontrollerprojects
//
//
// HOW TO USE THIS LIBRARY:
// ------------------------
// Go through this hd44780.h file and make your selections in all boxes that are not grayed out by the IDE (at least CCS grays out non-relevant parts of code).
// Depending on your selection, not required parts are grayed out automatically. Therefore it is important to start at the top without skipping any required box.
// Once you have reached the end of the configuration, simply call the hd44780_timer_isr() inside a continuously running timer ISR that is executed every 1 ms to
// 10 ms - the time depends on the size of your display, the used interface, your application and your personal feeling. For a 4x20 LCD in 4 bit mode connected
// serially, I would recommend to use 1 ms, but this also depends on the update rate of your screen content. Beside from the interrupt function, this library has
// one other major function to write a string to the position you like and it also offers a few basic functions to output some data. Anyway, for more sophisticated
// string editing, I would recommend to use sprintf and pass the string to to this library.


// ########## INCLUDE THE HEADER FILE FOR THE USED PROCESSOR #################################################################################################################
//                                                                                                                                                                           #
#include <msp430fr5994.h>                                   // Controller specific header file                                                                                #
//                                                                                                                                                                           #
// ###########################################################################################################################################################################
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

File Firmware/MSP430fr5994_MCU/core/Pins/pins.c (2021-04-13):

#include "pins.h"
#include "hd44780.h"


short _compile_transmitter_pins = 0x00;

short ConfigureADC12Pins(short build_transmitter){
    if (build_transmitter==0x01){
        // P1OUT |= 0x03;
        _compile_transmitter_pins = 0x01;
    }
    // WDTCTL = WDTPW | WDTHOLD;               // Stop WDT

    // GPIO Setup
                    // Configure P3.0 for ADC  (ADC12)
    P3SEL1 |= BIT0;
    P3SEL0 |= BIT0;
                    // Configure P3.1 for ADC  (ADC13)
    P3SEL1 |= BIT1;
    P3SEL0 |= BIT1;
                    // Configure P3.2 for ADC  (ADC14)
    P3SEL1 |= BIT2;
    P3SEL0 |= BIT2;
                    // Configure P3.3 for ADC  (ADC15)
    P3SEL1 |= BIT3;
    P3SEL0 |= BIT3;



    // Disable the GPIO power-on default high-impedance mode to activate
    // previously configured port settings
    // PM5CTL0 &= ~LOCKLPM5;

    

    // General ADC Configuration
    ADC12CTL0 &= ~ADC12ENC;
    ADC12CTL0 = ADC12ON | ADC12SHT0_4; //ADC12SHT0_3;      // Sampling time, S&H=16, ADC12 on
    ADC12CTL1 = ADC12CONSEQ_1 | ADC12SHP | ADC12SSEL_3 | ADC12VRSEL_14;                   // Use sampling timer
    ADC12CTL2 |= ADC12RES_2;//ADC12RES_1;//ADC12RES_2;                // 12-bit conversion results
    ADC12CTL3 |= ADC12CSTARTADD__ADC12MEM12;
    // Enable ADC conv complete interrupt (ADC Pin 0-15)
    ADC12IER0 = ADC12IE0 | ADC12IE12 | ADC12IE13 | ADC12IE14 | ADC12IE15;
    
    // Configure ADC12 and/or ADC13
    ADC12MCTL12 = ADC12DF_0 | ADC12VRSEL2 | ADC12INCH_12;               // A12 ADC input select; Vref=AVCC
    ADC12MCTL13 = ADC12DF_0 | ADC12VRSEL2 | ADC12INCH_13;               // A13 ADC input select; Vref=AVCC
    ADC12MCTL14 = ADC12DF_0 | ADC12VRSEL2 | ADC12INCH_14;               // A14 ADC input select; Vref=AVCC
    ADC12MCTL15 = ADC12EOS | ADC12DF_0 | ADC12VRSEL2 | ADC12INCH_15;    // A15 ADC input select; Vref=AVCC

    // while (1)
    // {
    //     __delay_cycles(5000);
    //     ADC12CTL0 |= ADC12ENC | ADC12SC;    // Start sampling/conversion
    //     printf("The pin voltage is %d V \n", ADC12MEM0);

    //     __bis_SR_register(LPM0_bits | GIE); // LPM0, ADC12_ISR will force exit
    //     __no_operation();                   // For debugger
    // }

    return 0;
}

// use (_compile_transmitter_pins) in if logic to multi-build

void GetADC(){
    ADC12CTL0 |= ADC12ENC | ADC12SC;    // Start sampling/conversion
    // __delay_cycles(1000);
    _no_operation();
}

short GetADC_12(){
    GetADC();
    return ADC12MEM12;
}

short GetADC_13(){
    GetADC();
    return ADC12MEM13;
}
short GetADC_14(){
    GetADC();
    return ADC12MEM14;
}
short GetADC_15(){
    GetADC();
    return ADC12MEM15;
}

#if defined(__TI_COMPILER_VERSION__) || defined(__IAR_SYSTEMS_ICC__)
#pragma vector = ADC12_B_VECTOR
__interrupt void ADC12_ISR(void)
#elif defined(__GNUC__)
void __attribute__ ((interrupt(ADC12_B_VECTOR))) ADC12_ISR (void)
#else
#error Compiler not supported!
#endif
{
    ADC12CTL0 &= ~ADC12ENC;
    switch(__even_in_range(ADC12IV, ADC12IV__ADC12RDYIFG))
    {
        case ADC12IV__NONE:        break;   // Vector  0:  No interrupt
        case ADC12IV__ADC12OVIFG:  break;   // Vector  2:  ADC12MEMx Overflow
        case ADC12IV__ADC12TOVIFG: break;   // Vector  4:  Conversion time overflow
        case ADC12IV__ADC12HIIFG:  break;   // Vector  6:  ADC12BHI
        case ADC12IV__ADC12LOIFG:  break;   // Vector  8:  ADC12BLO
        case ADC12IV__ADC12INIFG:  break;   // Vector 10:  ADC12BIN
        case ADC12IV__ADC12IFG0:            // Vector 12:  ADC12MEM0 Interrupt
            // if (ADC12MEM0 >= 0x7ff)         // ADC12MEM0 = A1 > 0.5AVcc?
            //     P1OUT |= BIT0;              // P1.0 = 1
            // else
            //     P1OUT &= ~BIT0;             // P1.0 = 0
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

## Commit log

2021-01-13 Create SECURITY.md
    This may or may not be implemented. This file is currently a place holder.
2021-01-20 commit "Battery Charger Controller Commit"
2021-01-21 commit "Overcame excel hangup - required closing of file first"
    [ProjectManagement.xlsx]
2021-01-23 Update README
    inserted a line on README
2021-01-23 Natasha 1
    Clock interrupt start
2021-01-29 Updated clock interrupt code
2021-01-31 Interrupt is now operational
    Next step is to configure a test for interrupt routine
2021-02-01 Reworked Architecture to Include Setup Routine
    + Reworked interrupt slightly, flushing out comments
    + Inserted Bluetooth Util Library which still requires flushing out.
2021-02-01 Changes to interrupts and start up routine
2021-02-03 Playing with interrupts
2021-02-04 commit "Worked with Natasha to fix button interrupt and plan Bluetooth messages"
2021-02-04 Beginning overhaul for PCB
2021-02-06 Worked on buttons 0,1,2,3 with Chad
2021-02-06 Adjusted to LEDs to PCB values
2021-02-06 For Natasha on ADC
2021-02-06 Worked with Chad on reading pin voltage
2021-02-08 Hardware
    Hardware files
    [HEC2_Receiver_Copper_Plane_1.gbr, HEC2_Receiver_Copper_Signal_1.gbr, HEC2_Receiver_Copper_Signal_Bot.gbr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]
2021-02-08 Code Review with Francisco
    Francsico needs to get board from Franci to test code.
    Refactored code and covered some basic good codingp practices.
2021-02-14 Relocated CAD drawings and did minor refactoring of GUI modules
2021-02-14 BOM update
    BOM Update
    [Receiver_BOM_RevA.xlsx, Transmitter_BOM_RevA.xlsx, Transmitter_WPT_SYSTEM_BOM_RevA.xlsx]
2021-02-22 pdf to png
    Document pictures
    [Transmitter_WPT_SYSTEM_BOM_RevA.xlsx]
2021-02-26 Initial CAD of Coil Box
    coil_box.stl file is for 3D Printing
    [coil_box.dwg, coil_box.f3d, coil_box.stl]
2021-02-26 Fusion 360, CAD, & 3D Printer Files
    .stl is raw import for 3D printer
    .mix is for meshmixer 3D printing program.
    [coil_box.dwg, coil_box.f3d, coil_box.stl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]
2021-03-08 Update button_interrupt.c
    Button 0 to toggle P5.0
